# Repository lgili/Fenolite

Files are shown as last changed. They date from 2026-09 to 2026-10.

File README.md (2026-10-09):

# Fenolite

**Headless, agent-first PCB design automation in Python.** Fenolite lets an engineer — or an AI
coding agent — generate, open, verify, compare, convert and export printed-circuit-board projects
from Python code or a JSON-speaking command line, without a GUI. KiCad is the first backend (its
files, with `kicad-cli` as the verification oracle); a second backend for another major commercial
format family follows.

> **Status: version 0.4.** A design script becomes a KiCad project with a board and a schematic, for
> KiCad 9.0 and 10.0. The loop of the agent guide works on two-layer boards: the board is placed, routed
> by an external router, filled, checked by KiCad's own design-rule check and exported to fabrication
> files. The schematic is judged by KiCad's own electrical rules check, by its netlist and by its
> schematic parity test. Version
> 0.4 adds the agent guide inside the package, boards of up to 8 copper layers with stack-ups, shaped
> outlines, differential pairs, impedance and length rules, routing with planes, and the documents and
> drawings a manufacturer asks for. What was proved for this version, what waits for the next one, and the
> limits are in `docs/release/v0.4.md` (`docs/release/v0.3.md`, `docs/release/v0.2.md` and
> `docs/release/v0.1.md` for the versions before). Every Altium write is experimental: no write kind has
> the evidence to leave that state yet, and most Altium evidence is `INFERRED` or an author report.

*Fenolite* is the Portuguese word for phenolic board material — the laminate many of us etched our
first circuit boards on.

## Principles

- **Agent-first CLI.** JSON on stdout when not attached to a terminal, a fixed envelope, typed
  errors, a small exit-code vocabulary, and writes only with `--confirm` (`--dry-run` shows the plan).
- **Evidence on every answer.** Each result says how it was verified (see below). Nothing is
  claimed that was not checked.
- **No silent information loss.** What Fenolite does not understand in a file is preserved, and a
  lossy operation stops unless explicitly allowed.
- **Small, exact model.** Integer nanometres and microdegrees, stable ids, canonical JSON that
  diffs cleanly in Git.
- **Stdlib-only core.** `pip install fenolite` installs no other package; heavier features are
  optional extras.
- **Your templates, not ours.** Sheet frames and title blocks are generated from your own spec;
  Fenolite ships no organisation's templates, rules or libraries.

The model is described in `docs/design-model.md`; the CLI contract in `docs/cli-contract.md`.

## What version 0.4 does

- **The schematic.** `fenolite build` writes the schematic of the design beside the board, one sheet
  per module, which KiCad's ERC and parity test accept on 9.0 and 10.0 (`docs/schematic.md`).
- **Checks.** `fenolite check` runs KiCad's ERC and DRC, compares the netlist of the schematic with the
  model and the board, and compares schematic and board without a tool (`fenolite netlist`,
  `fenolite parity`).
- **Tables and files.** The bill of materials and the placement table (`fenolite bom`, `fenolite pnp`)
  are rendered through a column template that you write (`docs/assembly.md`). Fabrication files and
  review renders (`fenolite export`, `fenolite render`) are described in `docs/exports.md`, and
  `fenolite manifest` lists every design file and artefact with its SHA-256 and a state.
- **Small questions.** `diff`, `roundtrip`, `fmt`, `explain`, `restore`, `net`, `region`, `neighbors`
  and `pads` answer one thing each, with paging and a concise form.
- **The layout is kept.** A board edited in KiCad survives a rebuild, also when a module or a net is
  renamed, and `fenolite sync --to-source` writes the placements into the source tree (`docs/lens.md`).
- **The design script.** Six more rule kinds (hole to hole, hole clearance, annular width, courtyard,
  silkscreen, creepage), exact quantities, typed interfaces, and your own drawing sheet and title block
  (`docs/dsl.md`, `docs/sheet-templates.md`).
- **Altium files are read.** `inspect`, `check`, `diff` and `equivalent` take Altium documents,
  libraries and projects, read-only and without a tool (`docs/altium.md`, `docs/equivalence.md`), and
  `fenolite analyze` measures current capacity, clearance and creepage on a board
  (`docs/analyses.md`). What is proved of this, and one known defect, are in the release record.
- **Altium files are written.** `fenolite build --target altium` writes the PCB document (stacks of up to
  16 signal layers, blind and buried vias, texts, keep-outs, holes, polygons and the script's rules), the
  schematic documents per module, both libraries, the project file, an output job and the drawing sheet;
  `fenolite check` judges copper and parity on Altium input, `equivalent --level 5` compares routing, and
  `fenolite kit` builds the Altium verification kit (`docs/altium.md`, `docs/altium-kit.md`). All of it is
  experimental: the release record says per file kind what is proved and what is missing.

- **The agent guide.** `fenolite guide` prints the guide that ships in the package, `fenolite skill
  install` puts it where an agent finds it, `fenolite init` writes a starter project, and
  `fenolite fetch freerouting` installs the pinned router (`docs/cli-contract.md`).
- **Larger boards.** 6 and 8 copper layers, stack-ups, outlines with arcs and cut-outs, holes, rule areas,
  board texts and dimensions, differential pairs, impedance targets, net lengths and meanders, via
  protection, net ties and waivers, placement rules and part heights (`docs/dsl.md`); `route` keeps plane
  nets to their planes and is bounded by `--timeout`, and `fenolite ready` says whether a project is
  electrically ready. What each change ships, and what waits for the next release, is in
  `docs/release/v0.4.md`.
- **Fabrication documents.** `fenolite export` writes IPC-2581, ODB++, STEP, PDF and DXF, and fabrication
  and assembly drawings (`docs/exports.md`, `docs/drawings.md`); `fenolite testpoints` reports fiducials and
  test points.

## Evidence labels

| Label | Meaning |
|---|---|
| `KICAD-VERIFIED` | accepted by `kicad-cli` of the stated version, and the claim confirmed by its output |
| `ORACLE-VERIFIED(<tool>)` | an independent parser or tool agreed |
| `CORPUS-VERIFIED` | round-trip holds on public files listed in the corpus manifest |
| `ALTIUM-VERIFIED(kit)` | confirmed by a native-tool acceptance run with archived results: a run of the verification kit that `fenolite kit` builds, checks and records ([docs/altium-kit.md](docs/altium-kit.md)) |
| `ALTIUM-VERIFIED(author-report)` | reported by the author from ordinary use; never enough for a release claim |
| `INFERRED` | deduced from public documentation; a hypothesis in `docs/hypotheses.md` tracks it |
| `UNKNOWN` | bytes or fields preserved without interpretation |
| `UNVERIFIED` | default for anything new |

A command's overall label is the lowest label of the steps it ran.

## Install

```bash
pip install fenolite
```

It installs no other package. `fenolite capabilities --json` then says which external tools it found:
`kicad-cli` (KiCad 9.0 or 10.0) for the checks, the fills and the exports, and a router. It runs on Linux, macOS
and Windows.

## The loop

The ten commands an agent runs, from an empty folder to fabrication files. They start from a starter
project made of built-in parts and use the built-in router, so `kicad-cli` is the only tool they need; a
real board is routed by an external router or by copper written in the script.
`fenolite guide start --text` prints the agent guide, which explains each command and what to do when one
fails (in this repository: `src/fenolite/agent/skill/SKILL.md`), and `fenolite skill install` copies it
to where an agent reads skills:

```fenolite-loop
fenolite capabilities --brief --json
fenolite init blink --confirm --json
fenolite build blink/design.py --out blink/build --dry-run --json
fenolite build blink/design.py --out blink/build --confirm --json
fenolite place blink/build --strategy grid --confirm --json
fenolite route blink/build --router direct --confirm --json
fenolite fill blink/build --confirm --json
fenolite check blink/build --json
fenolite export blink/build -o blink/fab --all --manifest --confirm --json
fenolite render blink/build -o blink/views --svg --png --confirm --json
```

## Install for development

```bash
git clone <this repository>
cd fenolite
uv sync --extra dev
uv run fenolite --version
make check-fast   # lint, format, types, residue scan and the tests that need no external tool
make check        # everything, on parallel workers: the gate before a merge
```

Talk to it like an agent does:

```bash
uv run fenolite capabilities --json --fields tools          # what is installed here
uv run fenolite capabilities --text                         # the same, for humans
echo $?                                                     # 0 ok, 2 usage, 4 confirm, 5 findings …
```

Optional extras: `geo` (polygon booleans), `kicad-ipc` (live KiCad session), `mcp` (MCP server),
`oracles` (Gerber re-parsers used in tests), `dev`. Routers need no extra: they run as separate programs.

## Licence and provenance

Apache-2.0 (`LICENSE`, `NOTICE`). Format knowledge comes only from public sources; see `LEGAL.md`
for the clean-room rules and `CONTRIBUTING.md` for how to contribute. Every CI run and every commit
(after `make hooks`) passes a residue scan (`tools/residue/`) that blocks absolute paths, internal
identifier shapes and known non-public files; see `docs/provenance.md` for the provenance rules. AI agents working in this
repository: read `AGENTS.md` first.

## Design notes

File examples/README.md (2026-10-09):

# examples

Designs authored for Fenolite (CC0-1.0), used as documentation and as end-to-end tests. Every
example is original work: no file, value, name or layout comes from any organisation's projects.

| example | what it shows |
|---|---|
| `blink_2layer/` | the thin DSL: a mini MCU, a resistor and an LED (bottom side) on a 50 mm × 30 mm two-layer board, from the authored mini library through the folder's own library tables; `fenolite build` turns it into a KiCad 9.0 or 10.0 project: the board, project and rules files, the schematic `blink.kicad_sch` with `sym-lib-table`, and under `lib/` the three footprints and the symbol libraries `Mini.kicad_sym` and `fenolite.kicad_sym` (`docs/schematic.md`); the 29 pins the circuit does not use are marked with `no_connect`, so KiCad's ERC reports nothing on the built project |
| `blink_routed/` | the blink with copper declared by the script: three tracks from pad to pad with waypoints and layer-changing vias, and a row of stitching vias, 11 tracks and 7 vias in all; the build resolves them after placement, so a part moved in KiCad pulls its tracks along (`docs/copper.md`) |
| `board_40parts/` | forty parts in two modules: two mini MCUs, each driving nine LEDs through nine resistors, with an enable pull-up, on a 100 mm × 80 mm two-layer board with a `GND` zone on both layers and one scripted ground via under each controller; only the two controllers are placed (and locked), the rest is left to `fenolite place --strategy grid`; the board minimums come from `design.rules.minimum`, so KiCad's DRC judges the finished board against the script's own rules; it is the second board of the v0.1 acceptance loop (`docs/release/v0.1.md`); its schematic takes one A3 sheet, a row of symbols per module, and KiCad's ERC and parity test report nothing on it |
| `blink_official/` | the same circuit on KiCad's official libraries; DSL source only, built by a `needs_libs` test into a temporary folder |
| `altium_sample/` | the experimental Altium target (`fenolite build … --target altium`): eight parts at the top level and in two modules, a 5 V regulator, a driver with an enable pull-up and an LED, two supplies sharing `GND`, every pin connected by number; its lib ids name `FenoliteSample.SchLib` and `FenoliteSample.PcbLib`, which Fenolite does not ship; the built files are committed under `tests/data/altium/sample/` |
| `altium_kicad/` | the Altium target from KiCad symbols (change c0034): a dual amplifier with common supply pins, a controller with pins on four sides, upright resistors and a connector from the authored CC0 `FenoliteDemo.kicad_sym`, found through the folder's `sym-lib-table`; the build writes their pins and units into `altium_kicad.SchLib`, and the built files are committed under `tests/data/altium/kicad_example/` |
| `altium_hier/` | sheets per module and a signal harness for the Altium target (change c0037, `--altium-sheets modules`): a connector on the top sheet, a controller and a flash memory in two modules, an `SPI` harness between them; `partial.py` adds a harness entry whose net stays on one sheet; the lib ids name `FenoliteHier.SchLib` and `FenoliteHier.PcbLib`, which Fenolite does not ship; the built files are committed under `tests/data/altium/hier/` |
| `altium_hier_board/` | the blink circuit of `blink_2layer/` split into the modules `driver` and `led`, with its board and the same authored libraries, so the Altium build writes a PCB document whose parts link through their sheet symbols |
| `kit/` | the five sample scripts of the Altium verification kit (`docs/altium-kit.md`): `flat`, `tree`, `routed`, `board6` and `libs`, all on Fenolite's own catalog; `fenolite kit build` builds them into the kit, and nothing it builds is committed |
| `yardstick/` | the yardstick board, at stage 5 of five (`docs/evidence/yardstick.md`): an invented controller of eight identical 48 V buck channels with an isolated high-voltage sense section, 388 parts of KiCad's official libraries and of the generated hole and assembly libraries on a 250 mm × 110 mm six-layer board with a declared stack-up, inner planes, slots under the isolators, plated mounting holes with keep-outs, a high-voltage rule area, the USB pair's rules and impedance target, thermal via arrays, placement rules, a net tie, fiducials, tooling holes and test points; one function makes a channel and is called eight times, references are `n·100 + k`, the script places every part and draws no track, and every value is stated once at the top as `chosen for the example` or with a source id; DSL source only, built for KiCad 10 from the verified library cache by a `needs_libs` test and taken through the loop every night by `tools/yardstick.py run` (routed by Freerouting, judged by KiCad), with a time and memory budget per step |

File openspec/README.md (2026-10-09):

# openspec

Spec-driven development with [OpenSpec](https://github.com/Fission-AI/OpenSpec).

- `specs/<capability>/spec.md` — the current, normative requirements (SHALL/MUST + scenarios).
- `changes/<id>/` — one proposed change: `proposal.md` (why), `design.md` (how), `specs/` (deltas),
  `tasks.md` (≤ 1-day tasks, each with the command that proves it).
- `config.yaml` — project context and artefact rules injected into every change.

No code lands without a change. Archive a change with `openspec archive <id>` once all tasks are done.

## Change ids

Archived changes are under `changes/archive/`; a change in `changes/` is proposed or being implemented. Plan items keep their numbers (c0009–c0016);
split-offs and follow-ups take c0017 and later numbers in implementation order, and a new split-off
takes the next free number. Ids follow the form `cNNNN-<slug>`, a project convention (the `openspec`
CLI accepts any kebab-case name); lettered ids such as `c0009a` are not used. A slug may still change
until its change is proposed. The nine v0.2a changes were allocated together as c0060–c0068 on
2026-10-04, while c0058 was being written, so c0057 stays unused.
The six v0.2b changes were allocated together as c0069–c0074 on 2026-10-05.
The ten changes of the write part of v0.3 were allocated together as c0083–c0092 on 2026-10-06, and
c0093 was taken for the release of v0.2 on the same day.
Since 2026-10-07 (c0136) v0.3 is the whole second backend, its read part and its write part, and v0.4
names the proposals that are written on other branches and are not in this table: c0077–c0081 (the
agent track), c0096, c0097 and c0099 (board authoring) and c0100–c0120 (the complex board). c0095 is
reserved; c0098 is in v0.4 by the maintainer's decision of 2026-10-08 (roadmap, "Open decisions", row 35) and has its row below. `docs/roadmap.md`, “Milestone names”, has the decision; archived changes
keep the names of their day. The changes of v0.4 were gathered on the branch `v04` and are released as
`0.4.0` by c0154; their folders are not all rows of this table.

| id | slug | roadmap item | parent |
|---|---|---|---|
| c0009 | `kicad-board-backend` | 0009 (part 1) | — |
| c0010 | `kicad-project-file` | 0010 | — |
| c0011 | `dsl-thin-build` | 0011 (part 1) | — |
| c0012 | `sheet-templates-kicad` | 0012 | — |
| c0013 | `kicad-oracle-and-check` | 0013 (part 1) | — |
| c0014 | `verification-evidence` | 0014 | — |
| c0015 | `zone-fill` | 0015 | — |
| c0016 | `routing-plugins` | 0016 | — |
| c0017 | `kicad-board-writer` | split-off | 0009 |
| c0018 | `kicad-rules-footprints` | split-off | 0009 |
| c0019 | `layout-preserve` | split-off | 0011 |
| c0020 | `check-netlist-drc` | split-off | 0013 |
| c0021 | `kicad-libs-cache` | follow-up | c0008 |
| c0022 | `placement-grid` | split-off | 0016 |
| c0023 | `specctra-freerouting` | split-off | 0016 |
| c0024 | `manufacturing-exports` | unowned deliverables | — |
| c0025 | `release-v0-1` | unowned deliverables | — |
| c0026 | `kicad-board-minimums` | dogfood gap | c0010 |
| c0027 | `build-properties-vendoring` | dogfood gap | c0011 |
| c0028 | `board-frame-copper` | dogfood gap | — |
| c0029 | `copper-check` | dogfood gap | — |
| c0030 | `footprint-fields` | dogfood gap | — |
| c0031 | `zone-settings` | dogfood gap | — |
| c0032 | `altium-schematic-writer` | v0.3 write, first item pulled forward | — |
| c0033 | `altium-binary-schematic` | follow-up | c0032 |
| c0034 | `altium-schlib-writer` | v0.3 write item pulled forward | c0032 |
| c0035 | `altium-pcb-writers` | v0.3 write items pulled forward | c0032 |
| c0036 | `no-connect-pins` | follow-up | c0032 |
| c0037 | `altium-hierarchy-harness` | v0.3 write item pulled forward | c0032 |
| c0038 | `altium-pcb-copper` | v0.3 write item pulled forward | c0035 |
| c0039 | `altium-compound-reader` | v0.3 read | — |
| c0040 | `altium-schematic-reader` | v0.3 read | — |
| c0041 | `altium-pcb-reader` | v0.3 read | — |
| c0042 | `altium-project-reader` | v0.3 read | — |
| c0043 | `altium-import` | v0.3 read | — |
| c0044 | `altium-inspect-check-diff` | v0.3 read | — |
| c0045 | `design-equivalence` | v0.3 read | — |
| c0046 | `altium-sheet-template-import` | v0.3 read | — |
| c0047 | `board-analyses` | v0.3 read | — |
| c0048 | `altium-eco-clean` | v0.3 (Altium writer) | c0038 |
| c0049 | `test-speed` | v0.1 | — |
| c0050 | `transform-composition-bound` | v0.1 | — |
| c0051 | `drc-canary-repeatability` | v0.1 | — |
| c0052 | `release-hygiene` | v0.1 | — |
| c0053 | `altium-script-copper` | v0.1 (Altium writer) | c0038 |
| c0054 | `dsl-rule-constructor` | v0.1 | c0011 |
| c0055 | `dsl-footprint-authoring` | dogfood gap / v0.3 write footprint generator | c0011, c0018 |
| c0056 | `dsl-pin-pad-map-slots` | dogfood gap / v0.3 write footprint generator | c0055 |
| c0057 | (unused) | — | — |
| c0058 | `authored-symbols` | follow-up | — |
| c0059 | `shared-footprint-pads` | follow-up | c0055 |
| c0060 | `kicad-schematic-reader` | v0.2a | — |
| c0061 | `kicad-schematic-writer` | v0.2a | — |
| c0062 | `erc-oracle` | v0.2a | — |
| c0063 | `netlist-compare` | v0.2a | — |
| c0064 | `bom-pnp-templates` | v0.2a | — |
| c0065 | `artifact-manifest-states` | v0.2a | — |
| c0066 | `cli-inspection-commands` | v0.2a | — |
| c0067 | `evidence-matrix` | v0.2a | — |
| c0068 | `v01-followups` | v0.2a | c0025, c0028, c0029, c0031 |
| c0069 | `layout-lens-complete` | v0.2b | c0019 |
| c0070 | `schematic-hierarchy-layout` | v0.2b | c0061, c0063 |
| c0071 | `rules-complete` | v0.2b | c0018, c0026, c0054 |
| c0072 | `schematic-board-parity` | v0.2b | c0062 |
| c0073 | `interfaces-quantities` | v0.2b | — |
| c0074 | `drawing-sheets-followups` | v0.2b | c0012, c0068 |
| c0075 | `standard-component-catalog` | dogfood gap: offline common symbols and footprints | c0008, c0058 |
| c0076 | `component-catalog-coverage` | expand offline symbols and standard package footprints across common families | c0055, c0056, c0075 |

| c0082 | `kicad-worksheet-oracle-isolation` | CI correction: isolated worksheet boundary oracle | — |
| c0083 | `altium-repeated-sheets` | v0.3 write | c0043 |
| c0084 | `altium-rule-lowering` | v0.3 write | c0038, c0042 |
| c0085 | `altium-pcb-complete` | v0.3 write | c0035, c0038 |
| c0086 | `altium-schematic-complete` | v0.3 write | c0032 |
| c0087 | `altium-outjob-sheet` | v0.3 write | c0042, c0046 |
| c0088 | `altium-light-drc` | v0.3 write | c0044, c0072 |
| c0089 | `equivalence-level-5` | v0.3 write | c0045 |
| c0090 | `altium-roundtrip-write` | v0.3 write | c0044 |
| c0091 | `altium-verification-kit` | v0.3 write | — |
| c0092 | `altium-write-graduation` | v0.3 write | c0091 |
| c0093 | `release-v0-2` | release of v0.2a and v0.2b as `0.2.0`: release record, guard, version | every v0.2a and v0.2b change |
| c0094 | `bom-dnp-grouping` | correction of v0.2a: a BOM line is all DNP or all fitted | c0064 |
| c0098 | `electrical-readiness` | v0.4 (the maintainer's decision of 2026-10-08): `fenolite ready`, one read-only reply on whether a KiCad project is electrically ready: open nets, KiCad's ERC and DRC, unconnected pins, power nets without a declared width or a zone, parts without a footprint or a value | c0062, c0108 |
| c0121 | `altium-component-bodies` | v0.3 follow-up: the component bodies that c0085 cut, fact rows first | c0085 |
| c0122 | `altium-zone-holes` | correction of v0.3: a zone fill keeps the holes of its poured region | c0043 |
| c0124 | `altium-plane-lines` | correction of v0.3: the Altium import makes no track of a line on an internal plane | c0043, c0088 |
| c0125 | `altium-clearance-scopes` | v0.3 follow-up: more forms of the Clearance record in the Altium rule table | c0084, c0088 |
| c0126 | `footprint-instance-graphics` | v0.3 write: the graphics and texts of a footprint instance and the corner ratio of a pad in the model; closes task 2.2 of c0090 | c0090, c0123 |
| c0127 | `altium-arc-record-values` | v0.3, follow-up (decision of 2026-10-06) | c0090 |
| c0128 | `altium-rewrite-via-drill` | v0.3, follow-up (decision of 2026-10-06) | c0090 |
| c0129 | reserved | v0.3 follow-up of c0121 and c0099: keep the model keys of a component body that was read | c0099, c0121 |
| c0130 | `altium-clearance-matrix-cells` | v0.3 follow-up: a Clearance matrix read as one rule per cell of item kinds | c0125 |
| c0131 | `altium-unit-slack-rule` | v0.3 follow-up: the slack of the copper check on Altium input as a stated rule | c0130 |
| c0132 | `altium-via-inner-pads` | correction of v0.3 (2026-10-07): a via whose record names layers without a pad shape is judged by its hole there | c0088, c0130, c0131 |
| c0133 | `release-0-2-1` | patch release `0.2.1`: the rule for patch releases of the series, the record, the guard, the version | c0093, c0135 |
| c0134 | `catalog-pin-text-legibility` | correction of v0.3: an authored symbol shows a pin name only where it can be read; a measured rule on every authored symbol, no writer changes | c0076, c0086 |
| c0135 | `altium-pin-map-backport` | correction of 0.1.0 and 0.2.0: an Altium build applies `pad_map` to the PCB document and writes it into the schematic | c0056, c0035 |
| c0136 | `milestone-renumbering` | names only: the write side of the second backend is v0.3 (released as `0.3.0`) and the proposals open on other branches form v0.4; no behaviour changes | — |
| c0138 | `altium-outjob-gerber-settings` | correction of v0.3: the Gerber output of a written output job carries the complete settings record, with the plotted layers from the board; fact rows first | c0087 |
| c0143 | `catalog-power-interface-library-case` | correction of 0.2.0 and 0.2.1: a design with catalog parts and a `Power` interface builds for KiCad, the power flag in the catalog's library | c0061, c0075 |
| c0146 | `altium-schematic-fonts-and-part-r` | correction of v0.3 (found in Altium Designer 26 on 2026-10-07): the font table of a written schematic holds each distinct font once; the authored `Repeat` sample is written by the schematic writer | c0087, c0083, c0086 |
| c0148 | `altium-pin-hide-bits` | correction of v0.3 (found in Altium Designer 26 on 2026-10-08): every written pin holds bit 0x20 of `PINCONGLOMERATE`, with 0x08 and 0x10 as show flags; the reader reads the two bits as hide flags on pins without 0x20 | c0032, c0034, c0040 |
| c0149 | `release-0-2-2` | patch release `0.2.2`: the record, the version | c0133, c0143 |
| c0150 | `release-0-3-0` | release of the write part of v0.3 as `0.3.0`: the release record with the verdict of the rule of c0092 per Altium write kind and the maintainer's exception for the kit, its guard, the version and the changelog cut; c0149 is the patch release `0.2.2` on its own branch, and c0151 and c0152 are proposed as the follow-ups the record names | c0083–c0092, c0121–c0148 |
| c0140 | `part-height-rules` | v0.4: part heights as bodies of their footprint, read by one function, and height limits over named rule areas judged by `check`, `place` and `build` | c0099, c0103, c0113 |
| c0152 | `clearance-rounding` | follow-up of c0131 (Altium's rule check of 2026-10-08, S-0616): the copper check on Altium input lowers its clearance rules by Altium's observed tolerance, 3.5 file units in whole nanometres (9 nm), where that is above the unit's slack | c0131, c0132 |
| c0153 | `kicad-cli-per-worker` | correction (two transient failures of the kicad-9 job on 2026-10-08): every `kicad-cli` run gets private temporary, runtime, cache and state folders, so parallel runs share no instance lock file | c0009, c0082 |
| c0154 | `release-0-4-0` | release of v0.4 as `0.4.0`: the release record with the verdict per change, what is deferred to the next release by the maintainer's decision of 2026-10-08 and the follow-ups found that day, its guard, the version and the changelog cut | c0077–c0081, c0096–c0120, c0137, c0140, c0141, c0145, c0152, c0153 |

Older planning text that says `tokens.yaml` means the token inventory `src/fenolite/backends/kicad/data/tokens.toml`.

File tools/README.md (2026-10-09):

# tools

Developer scripts (stdlib-only, run as `uv run python tools/<script>.py`). They are not part of the
installed package. Later changes add the schema generator, the residue scan, the corpus fetcher and
the oracle setup scripts here.

| script | what it does |
|---|---|
| `test_outcomes.py` | Compares the JUnit XML files of two pytest runs (`--junitxml`): the totals of each run and every test id whose outcome differs; exit 0 when equal, 1 when not. It proves that a parallel run gives the results of a serial run (`tests/README.md`, "Parallel runs"). |
| `kicad_libs_fetch.py` | Fetches the official KiCad footprint and symbol libraries at the pinned commits of tags 10.0.6 and 9.0.9 into a verified cache outside the repository (`--cache`, else `FENOLITE_LIBS_CACHE`, else `~/.cache/fenolite/libs`); `--verify` re-hashes it. The libraries are CC-BY-SA 4.0 and are never committed (`docs/formats/kicad/libraries.md`, "Library cache"). |
| `altium_census.py` | `--uses altium-sch` or `--uses altium-schlib` [`--json`]: reads the cached Altium schematic or library corpus rows with `fenolite.backends.altium.read` and prints the merged census (record ids, unknown ids and keys, key case, `WEIGHT`, owners, fractions, pin strings, side streams, stream sizes, issue codes). Key names, ids and counts only, never a value of a file (change c0040). |
| `gen_agent_guide.py` | Writes the generated parts of the agent guide under `src/fenolite/agent/skill/`: `references/commands.md` from `fenolite.cli.describe`, `references/dsl-reference.md` from the signatures of `fenolite.dsl`, and the index of pages between the two marker lines of `SKILL.md`. `--check` writes nothing and exits 1 naming each stale file; `make check-fast` runs it. |
| `gen_evidence_matrix.py` | Renders `docs/evidence/matrix.md` from the evidence declarations of the backend modules (`fenolite.backends.matrix`) and the level text of `docs/hypotheses.md`: the matrix of backend, file kind and operation, the register level of each id it names, and each module's declaration. `--check` writes nothing and exits 1 when the committed page is stale (`tests/unit/test_evidence_matrix_page.py` runs it). |
| `yardstick.py` | Takes `examples/yardstick` through the loop of its stage and judges the run (change c0119; "The yardstick" below). |
| `yardstick_budgets.toml` | The seconds and MiB each step of the yardstick may take, per stage, and the findings a stage accepts. |

## The yardstick

`uv run python tools/yardstick.py run --out build/yardstick --record build/yardstick/record.json` (or
`make yardstick`) reads `STAGE` from `examples/yardstick/design.py` without running it, and runs the steps
of that stage, each as one child process `python -m fenolite <args> --json` in the output folder, which
becomes the project folder and must be empty. It needs `kicad-cli` 10 and `FENOLITE_LIBS_CACHE` naming the
verified library cache of tag 10.0.6 (`kicad_libs_fetch.py --tag 10.0.6`); from stage 4 also
`FENOLITE_FREEROUTING_JAR` (`fenolite fetch freerouting --confirm`, and Java 25) and `FENOLITE_KRT` with
`FENOLITE_KRT_PYTHON` (the pinned KiCadRoutingTools checkout), as the nightly job sets them.

- **Steps of stage 1**, in order: `capabilities`, `build-dry`, `build`, `fill`, `check` (concise; it exits
  5 before stage 4, because nothing is routed), `export`, `render`, `bom`, `pnp`, `manifest`, `rebuild-dry`,
  `rebuild`, `inspect`, `build-install` (a dry-run build without `FENOLITE_LIBS_CACHE`, so the libraries
  come from the KiCad install), then `heavy-read` and `heavy-rt1` once for each of the two corpus boards
  tagged `heavy` (`corpus_fetch.py --uses heavy --only <id> <id>`; `--skip-heavy` leaves them out).
  `--only STEP,…` runs single steps on an existing project.
- **Steps added by the later stages:** stage 3 `impedance`; stage 4 `route-pairs` (KiCadRoutingTools on the
  pair, with the escape of the controller), `route` (Freerouting, `--timeout 3600`, two tiers),
  `fill-routed`, `check-routed` (exit 0, or 5 with counts within the ratchets), `net` and `analyze`;
  stage 5 `export-package` (the document kinds and drawings, with `--manifest`) and `testpoints`.
- **Per step** the record keeps the arguments, the exit code, the wall seconds, the peak resident memory
  of the step's largest process, the bytes of the reply and the issue counts by code. The replies are
  kept under `yardstick-run/replies/` of the output folder.
- **Rules.** Every step exits as its stage expects; every `check` stage that ran is `ok`, except
  `drc.kicad`, whose only error type before stage 4 is `unconnected_items`; `copper.clearance` has no
  finding and the net comparison no difference; the manifest lists every file that `export`, `render`,
  `bom` and `pnp` wrote; the dry rebuild plans no change to a file outside `.fenolite/`, and the rebuild
  leaves the board's bytes unchanged. A failed `build` or `fill` skips the steps that need the board.
  From stage 4, `check-routed` holds KiCad's open connections and DRC errors of the routed board to the
  stage's ratchets; an error of `length.rules` there counts through KiCad's `length_out_of_range` or
  `skew_out_of_range` when KiCad reports that type as often, and fails the stage otherwise; at stage 5 every file that `export-package` and `testpoints` wrote is listed in
  `fab/fenolite-artifacts.json`.
- **Budgets.** `yardstick_budgets.toml` holds a table per stage: `source`, then `seconds` and `mib` per
  step under `[stage<n>.steps.<step>]`, and from stage 4 `[stage<n>.ratchets]` with `open_connections` and
  `drc_errors`. A step over its budget, or a count over its ratchet, fails the run; a step without a
  budget is recorded and fails nothing; a stage without a table, or from stage 4 without its ratchets, is
  exit 2. `rebase RECORD RECORD RECORD` prints the budgets that three runs give (median seconds times 1.5,
  rounded up to 10 s; largest MiB times 1.25, rounded up to 50 MiB; a ratchet is the largest count), and
  `rebase --provisional RECORD` those of one local run (times 4 and times 2).
- **Accepted findings.** A finding that only a repair in Fenolite can remove is accepted for a stage by
  an entry `[stage<n>.accepted.<key>]` with `stage` (the `check` stage), `type`, `reason` and `owner` (the
  change or issue that owns the repair). It is counted in every record and fails nothing; any other type
  still fails the run. Stage 1 has none.
- **The record** (`fenolite.yardstick-record.v0`) holds the date, the commit, the stage, the runner, the
  tool versions, the board's measures, the steps, the rules, the accepted findings, the budgets and the
  verdict, with no absolute path. `row RECORD --url URL` prints its row of the `Runs` table of
  `docs/evidence/yardstick.md`.
- **Exit codes:** 0 passed; 1 a step, a rule or a budget failed; 2 usage, or a missing `kicad-cli`,
  library cache, corpus row, router, budget table or ratchet table. The summary is printed, and appended to `--summary FILE`.
- Seconds and MiB are measures of one runner: no evidence label moves on a budget.

## Agent evaluation (`tools/agent_eval/`)

Measures whether a fresh AI agent can use Fenolite (change c0081). `run.py` gives one task of
`tools/agent_eval/tasks/` to one runner of `runners.toml` in a clean place, and Fenolite itself decides
the result.

```
make agent-eval TASK=led-indicator RUNNER=replay
uv run python tools/agent_eval/run.py --task led-indicator --runner replay [--repeat N] [--keep] [--record] [--yes]
```

| file | what it does |
|---|---|
| `run.py` | Builds the wheel of the checkout, installs it with no extra and no index in a new environment under a new temporary folder outside the repository (`uv` does both), makes an empty work folder, copies the task's `files/`, runs its `prepare` lines, installs the guide as the runner's row says, prints the budget, starts the runner with the call log first on `PATH`, stops it when the task's minutes are over, judges, writes `result.json` beside the work folder and prints one verdict line. Exit 0 when every verdict is `passed`, 5 otherwise, 1 when the place could not be prepared, 2 for a refused run. The temporary folder is removed unless `--keep` is given. |
| `judge.py` | The verdict, from the files of the work folder: the project exists, `fenolite check` exits 0, the nets of the built model are the expected groups of `REF-PIN`, the board fits, the output files exist. `passed` needs `kicad-cli`; without it the verdict is `unjudged`. |
| `shim.py` | The call log: a stand-in named `fenolite` that passes a call through unchanged and appends one JSON line per call (`n`, `argv`, `exit`, `elapsed_ms`, `error_code`). It logs no environment value; an absolute path is logged relative to the current folder, or as `<outside>/NAME`. |
| `tasks.py`, `tasks/` | The task format and the five tasks with their reference solutions (`tasks/README.md`). |
| `runners.toml` | The runners. `replay` plays the reference solution of a task and starts no agent: it is what the test suites run. Every other row starts a real agent and names the public page it was written from. |

**A run with a real agent costs money and is started by a person, never by an agent and never in CI.**
`run.py` refuses a runner other than `replay` while the variable `CI` is set; without `--yes` it prints
the task, the runner, the time budget and the cost cap and starts nothing; a row marked `unconfigured`
does not start at all. One run is one agent session of at most the task's minutes (20, and 30 for
`custom-footprint`), so the five tasks are at most 110 minutes of agent time. What a session costs is
not known before the first one: run `led-indicator` once, read the cost the runner reports, then decide
on the rest. The tool reads no key and calls no service itself; the agent it starts inherits the
environment of the person who started it, and is not sandboxed beyond an empty work folder and a new
environment.

To record a run, add `--record`: one row is appended to `docs/evidence/agent-eval.md` (date, commit,
runner, model, task, verdict, calls, failed calls, minutes, first failure), with no path, prompt or
transcript. Add a row to `Findings` by hand for each distinct first failure. `--keep` leaves the
temporary folder, which holds the transcript, on your machine; it is never committed.

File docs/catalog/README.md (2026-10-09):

# Fenolite component catalog

Fenolite ships an offline, incrementally expanded catalog under the `Fenolite:` library ID. Its
entries are Fenolite-authored model definitions. The catalog includes generic passive,
semiconductor, protection, power/control IC and electromechanical symbols: **49 symbols** plus **100 distinct
footprint variants** for chip passives, discretes, ICs, connectors, LEDs, switches, leaded passives,
crystals and mechanical features. See the
[coverage matrix](coverage.md) for exact IDs, evidence and package limitations.

Use the definitions in Python with `fenolite.catalog.get_symbol()` and
`fenolite.catalog.get_footprint()`. `fenolite catalog list` searches the installed catalog and
`fenolite catalog show Fenolite:Resistor` prints one entry's metadata. A KiCad build uses a catalog
definition when the CLI design references its lib id. With the lower-level `build_design()` API,
pass `get_footprint(lib_id)` definitions in `authored_footprints` and symbol definitions in
`authored_symbols`. A project definition with the same exact lib id
overrides the catalog for that build only. Other component packs can be added without requiring a
CAD installation or network access.

A catalog footprint definition holds no text field. The KiCad build generates the two a KiCad
footprint needs (change c0077): `Reference` (`REF**` in the project library, the part's reference on the
board) on `F.SilkS`, 1 mm above the footprint's courtyard box, and `Value` (the footprint's name in the
library, the part's value on the board) on `F.Fab`, 1 mm below it. `Part.field("Reference", …)` and
`Part.field("Value", …)` move or hide them (`docs/dsl.md`, "Field placement"). So a board that names
only catalog ids passes `fenolite check`: `tests/_catalog_design.py` holds such a design, and
`tests/unit/cli/test_catalog_only.py` and `tests/kicad/build/test_catalog_only.py` build and check it.

The schematic symbols use aligned wire connection points, inward-facing stems and 0.254 mm body
strokes. Their outlines are Fenolite-authored interpretations of familiar electrical shapes.
Review sheets render the actual catalog geometry, including background fill and terminal roles.

Pin names follow one rule (change c0134): a symbol shows a pin name only where it can be read.

- A symbol whose drawing tells its pins apart hides its pin names and shows the pin numbers alone:
  the passives, diodes, transistors, thyristors, switches, the relay, the transformer, the
  optocoupler, the bridge rectifier and the two amplifiers. Where the drawing alone would not say
  which pin is which, strokes say it: a plus and a minus at the amplifier inputs; a plus, a minus
  and two waves inside the bridge; an arrowhead on the optocoupler's emitter leg.
- The four plain rectangles show their names and are sized for them: `Linear_Regulator`,
  `Offline_Power_Controller`, `Microcontroller` and `Power_Module`.
- A hidden name stays in the definition: `fenolite catalog show` and the role line of the review
  sheets list every name, and a design may still name a pin by it.

`tests/unit/catalog/test_pin_text_legibility.py` measures the rule on every catalog symbol at the text
size of KiCad (1.27 mm) and at an estimate of Altium's 10-point pin text: no shown pin text overlaps
another, a shown name has room inside the body, no shown name or number lies on a stroke of the body or
on the mark of a pin shape, and no shown name only repeats its pin's number. The Altium size is an
assumption, not a measurement in Altium.

## Symbol review

The [20-symbol expansion inventory](target-20-symbols.md) records exact IDs, conceptual pin roles and public references.

- [New symbols, sheet 1](previews/c0076-new-20-symbols-page1.svg): transistors, thyristors, protection and potentiometer.
- [New symbols, sheet 2](previews/c0076-new-20-symbols-page2.svg): thermistors, crystal, switches, relay, transformer and photodetectors.
- [Complete 49-symbol gallery](previews/c0076-all-49-symbols.svg).

Regenerate the complete gallery with:

```sh
uv run python tools/catalog/render_symbols.py docs/catalog/previews/c0076-all-49-symbols.svg --page-size 20
```

The new drawings retain zigzag resistance, show unactuated contact states and inward photodetector arrows. Generic B/C/E, G/D/S, coil and winding numbers are role identifiers. The four-terminal pushbutton has two internally common pairs; the two Würth footprints require different explicit maps. No generic symbol supplies a default footprint. Offline build tests preserve these maps and pad nets for KiCad 9/10 targets.

## Footprint review

The [100-slot inventory](target-100-footprints.md) is fully resolved. It is a curated selection
informed by a public-board corpus; it is not a measured worldwide popularity ranking.

Review the native geometry in five sheets of 20 footprints each:

- [Sheet 1](previews/c0076-current-gallery-page1.svg)
- [Sheet 2](previews/c0076-current-gallery-page2.svg)
- [Sheet 3](previews/c0076-current-gallery-page3.svg)
- [Sheet 4](previews/c0076-current-gallery-page4.svg)
- [Sheet 5](previews/c0076-current-gallery-page5.svg)

Blue is the fabrication outline, green the courtyard, orange copper and gray explicit paste
windows. White drill apertures distinguish round holes and plated slots. The sheets show the
component-side view with pad numbers; asymmetric connector origins retain their electrical
coordinates while the renderer centers the courtyard. These are schematic review drawings of
the footprint geometry, not 3D mechanical models.

Regenerate the full sheet and its five pages with:

```sh
uv run python tools/catalog/render_footprints.py docs/catalog/previews/c0076-current-gallery.svg --page-size 20
```

The final audit checks 100 unique IDs against the inventory, registered public sources, distinct
pad/body/paste geometry (ignoring labels and IDs), positive pad clearance and the complete courtyard
bounds. Every definition is serialized and read back with its pad kind, layers, drill, slot,
attributes and drawing geometry preserved. A hermetic API build assigns all 100 definitions to
authored terminal-only test symbols, explicitly maps their terminals, and reads the resulting
board back for KiCad 9 and 10 targets. This proves catalog use and pad/net preservation; the
audit fixture does not represent a functional circuit or a routed board.

Reproduce the focused audit and local branch gate with:

```sh
uv run pytest tests/unit/catalog tests/unit/cli/test_catalog.py tests/unit/lens/test_build_catalog_inventory.py tests/unit/lens/test_build_catalog_symbols.py -q
make check-fast
openspec validate --specs --strict
```

The catalog is not a substitute for checking a selected manufacturer's part. Generic symbols do not
promise a device pinout. Copper lands without an explicit source recommendation are labelled
`INFERRED`; even sourced example lands are starting patterns that require checking against the exact
component datasheet and assembly process before fabrication. Catalog entries do not qualify a part
or board for electrical, thermal or safety requirements.

## Public evidence

- `S-0314` identifies the common passive component families and schematic-symbol categories.
- `S-0315` supplies 0402, 0603, 0805 and 1206 resistor body dimensions. It does not specify the
  footprints' copper land geometry.
- New family and package references are mapped per entry in [the catalog evidence map](sources.md).

Source details are in [the evidence register](../evidence/sources.md).

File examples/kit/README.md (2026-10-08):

# examples/kit

The five sample scripts of the Altium verification kit (`docs/altium-kit.md`). `fenolite kit build --out DIR
--confirm` builds each into an Altium project of the kit; nothing that it builds is committed here.

| sample | what it holds |
|---|---|
| `flat/` | a controller, a resistor, an LED and a connector on one sheet, with the generic drawing sheet and a title block; built in the binary and in the ASCII form |
| `tree/` | a supply, a sensing stage and four LEDs in the modules `power`, `io` and `io/leds`, with the bus `D`; four sheets, no board |
| `routed/` | the circuit of `flat` with tracks, vias, one polygon, five rules and two planted violations |
| `board6/` | the circuit of `flat` on six copper layers with a plane, blind and buried vias, texts, graphics, a keep-out and a hole |
| `libs/` | seven catalog parts, for the schematic library and the PCB library that the build writes |

Every script is authored for Fenolite (CC0-1.0) and takes its symbols and footprints from Fenolite's own
catalog, so a build reads no library and gives the same bytes on every machine.

A sample script is a design script. It may also bind `KIT`, a mapping with the keys `sheets`, `forms`,
`copper`, `planes` and `drawing_sheet`, and a function `kit_model(model)` that returns the model with what
the DSL cannot declare (a bus, six copper layers, board items). Both are read by `fenolite kit build` only:
`fenolite build` builds the same script without them.

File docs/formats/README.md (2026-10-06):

# docs/formats

One page per file-format topic, per backend (`kicad/`, `altium/`, …). Every fact on a page cites a
public source listed in `../evidence/sources.md` and carries an evidence label
(`KICAD-VERIFIED`, `ORACLE-VERIFIED(<tool>)`, `CORPUS-VERIFIED`, `INFERRED`, `UNKNOWN`).
Code is written from these pages, never from third-party source code (see `LEGAL.md`).

## Altium import pages (c0043)

- `altium/connectivity.md`: the rules by which the import derives nets from schematic sheets.
- `altium/import.md`: the mapping of PCB records into the model, the id table and the extension-bag keys.
- `altium/pcb-bodies.md`: the component-body record and its typed keys.

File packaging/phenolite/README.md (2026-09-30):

# phenolite → Fenolite

`phenolite` is an alias. Installing it installs **[Fenolite](https://github.com/lgili/Fenolite)**,
the headless, agent-first PCB design automation library for Python:

```bash
pip install fenolite      # the real package
pip install phenolite     # the same thing, for those who spell it in English
```

Import `fenolite` in your code. *Fenolite* is the Portuguese word for phenolic board material.

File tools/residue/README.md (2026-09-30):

# Residue scan

`scan.py` looks for material that must not be in a public repository: absolute user paths,
cloud-drive paths, internal revision or part-number shapes in data files, whole files known to be
derived from non-public material, and private tokens.

```bash
uv run python tools/residue/scan.py              # tree (+ dist/*.whl if present); exit 5 on hits
uv run python tools/residue/scan.py --staged     # what `git commit` would record
uv run python tools/residue/scan.py --list-patterns
make hooks                                        # install the pre-commit hook
```

Output lines are `path:offset:pattern-id`; the matched text is **never** printed.

## Sources

| Source | Where | Public? |
|---|---|---|
| structural regexes | `patterns.regex` | yes |
| whole-file SHA-256 list | `blobs.sha256` | yes (hashes only) |
| private tokens | `FENOLITE_RESIDUE_TOKENS` (inline, comma or newline separated), the file named by `FENOLITE_RESIDUE_TOKENS_FILE`, or `~/.fenolite-residue-tokens` | **never committed** |
| private whole-file SHA-256 list | the file named by `FENOLITE_RESIDUE_BLOBS_FILE`, or `~/.fenolite-residue-blobs` | **never committed** |

Token file format: one token per line; `#` starts a comment; a plain token matches
case-insensitively when not surrounded by letters or digits; a line starting with `re:` is a
regular expression. Blob files: `<sha256> <label>` per line.

A private gate with the maintainers' token list runs before every release; its content is not
published. No token list may be committed here, not even hashed (`tests/residue/test_no_token_list.py`).

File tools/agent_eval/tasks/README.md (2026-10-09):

# Tasks of the agent evaluation

Each folder is one task for `tools/agent_eval/run.py` (change c0081): a board stated as a requirement,
and what a correct result holds.

| task | what the agent must do |
|---|---|
| `led-indicator` | write a design script from nothing, place, route with the built-in router, check, export |
| `regulator-zone` | put the supply nets in a net class, pour a ground zone on one layer, fill it, keep the board within a size |
| `custom-footprint` | author a symbol and a footprint from dimensions, for a part the catalog lacks, with one pin on two pads |
| `fix-short` | find the short of a given routed project with `check` and repair it without changing a net |
| `two-sided` | place parts on both sides and join them with scripted copper through a via, under given minimums |

## Where the tasks come from

Every task, prompt, circuit, number and expected result here was written for Fenolite. Nothing comes
from an employer, a private project, a product or any organisation: the circuits are textbook
arrangements of a header, a resistor, a LED, a Zener diode and a capacitor, the part `U1` of
`custom-footprint` is invented, and every size is a round value chosen for the task. Every part of
every solution is an id of Fenolite's built-in catalog or is authored in the solution's script, and
no solution needs an external router or a KiCad library.

## Licence

The tasks are dedicated to the public domain under `CC0-1.0`: the `task.toml` files with their prompts
and expected results, the `commands.txt` files and this page. The task scripts (every `.py` file of a
task) carry the `Apache-2.0` header that the repository's SPDX guard (`tests/unit/test_spdx_headers.py`)
demands of every `.py` file, while the task texts are `CC0-1.0`.

## The format

```
<name>/
  task.toml             title, prompt, [budget] minutes, [expect], optional prepare
  files/                optional: copied into the work folder before the agent starts
  solution/
    commands.txt        the fenolite lines of a correct run, one per line
    files/              optional: the files a correct run writes
```

- `prompt`: at most 300 words, in plain words. It names every reference of the expected nets and the
  folders to leave. It names no command, no option and no page of the guide: finding them is what a
  run measures.
- `[expect]`: `project` (the folder of the built project), `copper_layers`, `max_size` (two lengths
  with units; the board may lie either way), `outputs` (file patterns, `**` for any depth) and
  `[expect.nets]`, a label for each net with its `REF-PIN` entries. `PIN` is a pin number of the
  part's symbol, not a pad number, and a pin on several pads is listed once. The labels are never
  compared: only the groups are.
- `prepare`: `fenolite` lines that build the starting state in the work folder. No task folder holds a
  built project: `fix-short` holds a script, and its starting project is built by the code under test.

`tools/agent_eval/tasks.py` reads a task and refuses a malformed one; `tests/unit/test_agent_eval.py`
loads them all and builds every solution; `tests/kicad/acceptance/test_eval_solutions.py` replays every
solution on `kicad-cli`.

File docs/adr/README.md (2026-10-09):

# Architecture Decision Records

One file per decision: `NNNN-short-slug.md`, numbered in order of allocation, never renumbered.
Format (MADR-lite); every ADR MUST contain these six sections, in this order:

```markdown
# ADR-NNNN: <title>

## Status
Proposed | Accepted | Superseded by ADR-XXXX | Deprecated

## Context
What forces are at play; what problem needs a decision.

## Decision
The decision, stated so that it can be checked.

## Alternatives
Each alternative considered, and why it was not chosen.

## Consequences
What becomes easier or harder; follow-up work.

## Evidence
Public sources (ids from `docs/evidence/sources.md`), tests or hypotheses that back the decision.
```

`tests/unit/test_adrs.py` checks the sections and the status vocabulary.

| ADR | Title | Status |
|---|---|---|
| [0001](0001-neutral-model.md) | Neutral model: small now, frozen after the second backend | Accepted |
| [0002](0002-kicad-file-backend.md) | KiCad file backend: Fenolite's own readers and writers, `kicad-cli` as the oracle | Accepted |
| [0003](0003-clean-room-and-provenance.md) | Clean-room development and provenance of format knowledge | Accepted |
| [0004](0004-licence-apache-2.0.md) | Licence: Apache-2.0; copyleft only behind a process boundary | Accepted |
| [0005](0005-sheet-templates.md) | Sheet templates: a neutral drawing sheet built from closed, sourced specifications | Accepted |
| [0006](0006-specctra-and-freerouting.md) | Specctra files from a restricted reference, and Freerouting behind a process boundary | Proposed |
| [0007](0007-fetching-external-tools.md) | Fetching external tools on request: only inside `fenolite fetch`, only with `--confirm`, only bytes of the pinned size and SHA-256 | Accepted |

**Numbering.**

- ADR-0002 was allocated by change c0001 before 0003 and 0004 existed; change c0009 writes it, so it is the only number written out of order.
- The next free number is one above the highest number written or allocated; a new ADR takes it when its change is proposed, and numbers are never reserved.
- ADR numbers are not tied to planning decision numbers. With 0001 to 0007 written (0006 by change c0023, 0007 by change c0078), the next free number is 0008.

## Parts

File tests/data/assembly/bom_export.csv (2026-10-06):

Reference | Value | Footprint | Datasheet | Description | ${DNP} | Bin
R10 | 330 | Mini:Mini_R_0603 |  | made-up resistor, 1 %, "thick" film | DNP
D1 | LED | Mini:Mini_LED_THT_3mm
R1 | 10k | Mini:Mini_R_0603 | none | made-up resistor |  | A

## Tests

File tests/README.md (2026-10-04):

# tests

| Folder | What lives there | Needs |
|---|---|---|
| `unit/` | fast, hermetic tests of `fenolite` and of repository invariants | nothing |
| `consistency/` | CLI contract checks run against every registered command (change c0002) | nothing |
| `residue/` | IP residue scan over the tree and the built wheel (change c0003) | nothing; private token list optional |
| `corpus/` | tests over the fetched public corpus (`tools/corpus_fetch.py`) | `needs_corpus` |
| `kicad/` | tests that call `kicad-cli` 9.0/10.0 | `needs_kicad` |
| `libs/` | census of the official KiCad libraries (read, resolve, count; nothing committed) | `needs_libs`, `slow` |
| `data/` | small fixtures authored for Fenolite, declared in `data/MANIFEST.toml` | nothing |

Run everything that needs no external tool with `uv run pytest -q`. `make check-fast` runs the
checks and the tests of `unit/`, `residue/` and `consistency/` that need no external resource;
`make check` runs every test. Both use parallel workers (see "Parallel runs" below).

## Markers and modes

| Marker or variable | Effect |
|---|---|
| `needs_kicad`, `needs_corpus`, `needs_libs` | skip when the resource is absent |
| `FENOLITE_REQUIRE=kicad,corpus,libs` | required-resource mode: those skips become failures (CI oracle jobs) |
| `kicad_min_major(10)` | skip when the running `kicad-cli` is older (for example `pcb upgrade`, 10.0 only); never a failure, even in required-resource mode |
| `FENOLITE_HEAVY=1` | include corpus files over 20 MB |
| `FENOLITE_KICAD_CLI=/path` | use this `kicad-cli` (a missing file counts as no `kicad-cli`) |
| `KICAD10_FOOTPRINT_DIR`, `KICAD10_SYMBOL_DIR` (or `KICAD9_*`) | official library folders for `needs_libs`; they take precedence over the install |
| `FENOLITE_KICAD_INSTALL_DIR=/path` | the KiCad share folder to use instead of the default install (a missing path counts as no install) |
| `FENOLITE_CENSUS_OUT=/path/census.json` | where `tests/libs/` writes its counts (never a tracked file) |

## Parallel runs

`make check`, `make check-fast` and the CI jobs run the tests on `pytest-xdist` workers
(capability ci-baseline, "Parallel test runs"). A plain `uv run pytest ...` stays serial.

| Where | Options |
|---|---|
| `make check`, `make check-fast` | `-n auto --maxprocesses 8 --dist loadfile` (`PYTEST_WORKERS`, `PYTEST_MAX_WORKERS`, `PYTEST_PARALLEL`) |
| CI `unit`, `kicad-10`, `kicad-9` | `-n auto --dist loadfile` (4 workers on the Linux runners, 3 on macOS) |
| by hand | `uv run pytest tests/kicad -q -n 8 --dist loadfile` |

Rules for tests:

- Write only below `tmp_path`. Use no fixed port and no fixed path outside the repository.
- Do not depend on a test of another file. A summary test may read what the earlier tests of its
  own file collected: `--dist loadfile` runs a file on one worker, in file order. `--dist load`
  breaks such files, so do not use it.
- Give every subprocess call that must finish a limit of 10 s or more. A short limit is only for
  a call that must time out.
- The write modes are serial. With `FENOLITE_PROBES_WRITE=1`, `FENOLITE_GOLDEN_WRITE=1`,
  `FENOLITE_CENSUS_OUT` or `FENOLITE_CHECK_EVIDENCE` set, a run with `-n` stops with a usage error
  (exit code 4): several workers would write the same file.
- Prove a change of the options with `uv run python tools/test_outcomes.py serial.xml parallel.xml`
  on the `--junitxml` files of a serial and a parallel run.

### Measurements (2026-10-04, change c0049)

Machine: 10 cores (4 performance, 6 efficiency), macOS, KiCad 10.0.6, corpus and library caches
present. The machine was never quiet: other agents ran test suites and a Docker container during
every run below (2 to 12 other pytest processes, load average 5 to 38). The times are therefore
upper bounds, and comparisons between rows are rough.

| Run | Options | Wall time | Outcomes |
|---|---|---|---|
| whole suite, before | serial | 3357 s (56 min) | 4827 passed, 24 skipped |
| `tests/kicad` | serial (part of the run above) | 1783 s | 584 passed, 10 skipped |
| `tests/kicad` | `-n 6 --dist loadfile` | 605 s | 584 passed, 10 skipped |
| `tests/kicad` | `-n 8 --dist loadfile` | 546 s | 584 passed, 10 skipped |
| `tests/kicad` | `-n 10 --dist loadfile` | 617 s | 584 passed, 10 skipped |
| `tests/kicad` | `-n 8 --dist load` | 838 s | 583 passed, 11 skipped: `test_upgraded_summary` lost the results of its file |
| `make check-fast` | `-n auto --maxprocesses 8 --dist loadfile` | 122 s (tests 101 s) | 3832 passed, 6 skipped |
| `make check`, after (rebased: 736 more tests) | `-n auto --maxprocesses 8 --dist loadfile` | 1226 s (20 min; tests 1205 s) | 5563 passed, 24 skipped |

- The cap is 8: the fastest of 6, 8 and 10, and it leaves two cores to the `kicad-cli` threads.
- With `loadfile` the longest file bounds the run. In the `tests/kicad` runs with 8 and 10 workers,
  `tests/kicad/check/test_corpus_rt.py` alone took 509 s and 611 s on its worker (412 s serial). The
  next ones are `tests/libs/test_official_resolve.py` (468 s serial), `tests/libs/test_official_read.py`
  (411 s) and `tests/kicad/check/test_check_demos.py` (364 s). Splitting them is later work.
- Equality. `tools/test_outcomes.py` on the serial and the final parallel JUnit files: the 4849
  test ids present in both runs have the same outcome (0 differences). The parallel run has 738
  more ids (723 from changes merged between the two runs, 15 from this change) and lacks 2 that
  were renamed. On one commit, the 594 ids of `tests/kicad` (`-n 8 --dist loadfile`) equal the
  serial run id by id.
- Before and after are not the same suite: the final run holds 15 % more tests and used 4538 s of
  CPU against 3064 s. Per test, the wall time went from 0.69 s to 0.22 s (3.2 times faster) while
  other agents kept the machine at a load average of 18 to 31.
- The maintainer's earlier figure for a serial `make check` on a quiet machine was 11 minutes.

### CI effect (2026-10-04, change c0049)

The first run with the parallel steps is https://github.com/lgili/Fenolite/actions/runs/37178050484
(commit 87c4244). The last serial run that finished on `main` is https://github.com/lgili/Fenolite/actions/runs/37171749778
(commit 75f3a87); three changes landed between the two, so the suites are not the same.

| Job | Serial: job, pytest | Parallel: job, pytest | Serial outcomes | Parallel outcomes |
|---|---|---|---|---|
| `unit` (ubuntu) | 139 s, 115.82 s | 108 s, 84.14 s | 4304 passed, 1080 skipped | 4490 passed, 1109 skipped |
| `unit` (macos) | 246 s, 201.36 s | 81 s, 56.46 s | 4304 passed, 1080 skipped | 4490 passed, 1109 skipped |
| `kicad-9` | 242 s, 208.50 s | 274 s, 239.96 s | 388 passed, 340 skipped, 1 xfailed | 426 passed, 343 skipped, 1 xfailed |
| `kicad-10` | 1485 s, 1440.18 s | 1088 s, 1051.89 s | 1140 passed, 21 skipped | 1182 passed, 21 skipped |
| whole run | 1492 s (24 min 52 s) | 1095 s (18 min 15 s) | all jobs passed | all jobs passed |

- Totals. Each job grew by exactly the tests added between the two commits, counted with
  `--collect-only` on both trees: 215 for the whole suite (`unit`, 5384 to 5599), 42 for
  `tests/kicad tests/corpus` (`kicad-10`, 1161 to 1203) and 41 for `tests/kicad` (`kicad-9`, 729 to
  770). No test failed in either run.
- `kicad-9` lists every outcome (`-rA`): the 386 passed and xfailed test ids that both logs list
  have the same outcome, and the 38 ids only in the parallel log are the tests of
  `tests/kicad/copper`, added after the serial run.
- Times. `kicad-10` bounds the run: its pytest step went from 24 min 0 s to 17 min 32 s with 42 more
  tests. The design expected a drop to about a third; `--dist loadfile` is bounded by its longest
  file (see the measurements above). `kicad-9` did not get faster: 31 s more with 41 more tests.

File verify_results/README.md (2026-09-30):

# verify_results

Results of verification runs made outside CI (for example a native-tool acceptance kit run on a
licensed machine). Each result file records the tool and version, the date, and the SHA-256 of
every artefact it judged, so an evidence label can point to it.

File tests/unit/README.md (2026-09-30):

# tests/unit

Hermetic unit tests: no network, no external tools, no corpus. Mirror the package layout
(`tests/unit/core/`, `tests/unit/model/`, `tests/unit/cli/`) and keep repository-invariant tests
(`test_pyproject_invariants.py`, `test_spdx_headers.py`, …) at this level.

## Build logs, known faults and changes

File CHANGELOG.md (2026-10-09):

# Changelog

All notable changes to Fenolite are documented here. The format follows
[Keep a Changelog](https://keepachangelog.com/en/1.1.0/) and the project uses
[Semantic Versioning](https://semver.org/) (pre-1.0: minor versions may break).

## [Unreleased]

## [0.4.0] - 2026-10-08

### Added

- v0.4, the agent track, board authoring and the complex board: the agent guide ships in the package with a starter project and eleven design pages, `fenolite fetch freerouting` installs the pinned router, and `tools/agent_eval` measures an agent on five authored tasks (c0077 to c0081); constrained placement, rule explanations of copper findings, `fenolite ready`, signed body volumes and part heights (c0096 to c0099, c0140); 6 and 8 copper layers, stack-ups, outlines with arcs and cut-outs, rule areas and board items, differential pairs, impedance targets, net lengths and meanders, routing with planes, open nets and a bounded routing step, pairs for KiCadRoutingTools, script copper in a part's frame, via protection, placement rules, net ties and waivers, power paths, the documents and drawings a manufacturer asks for, fiducials and test points, a reviewed plan written as reviewed, and the yardstick example (c0100 to c0120). What each change ships and what waits for the next release is in `docs/release/v0.4.md`; every Altium write stays experimental.
- **New command `fenolite ready PATH`** (c0098): one read-only reply on whether a KiCad project is electrically ready for fabrication. It gathers the open nets (`analysis.connectivity`, as `fenolite net`), KiCad's ERC and DRC (the `erc.kicad` and `drc.kicad` stages of `check`, unchanged) and the footprint rule of `model.validate`, and adds three rules: pins on no net or alone on a net without a no-connect mark (`ready.pin-unconnected`), power nets with neither a track width of their class or of a rule nor a zone (`ready.power-net-unsized`), and parts without a value (`ready.part-value-missing`); open nets are `ready.net-open`. Exit 0 when `result.ready`, 5 with the findings; a missing `kicad-cli` exits 6 as for `check`, and `--no-kicad` reports ERC and DRC as skipped (`ready.check-skipped`, `result.complete` false). The three rules are `INFERRED` (`H-G-READY-RULES`). `model.circuit.power_interface_nets` and `checks.validate.unresolved_footprints` are now the one place of the power-interface set and of the footprint rule, used by ERC lite, the schematic writer and `model.validate` with their output unchanged.
- `fenolite check` marks every DRC type whose count reached the limit of KiCad's report (499 entries of `clearance` and `unconnected_items`, 199 of any other type): `summary.limits` of the stage `drc.kicad` and one `check.report-limit` warning per type; such a count is a lower bound. Status and exit code do not change (c0141). A reply of a board under every limit gains `"limits": []`; `null` says that nothing is known. The limits are measured on an authored bench with `kicad-cli` 10.0.6; the 9.0.9 counts of 2026-10-05 wait for their recorded probes.
- **Footprints from the built-in catalog and from `dsl.Footprint` now carry `Reference` and `Value` on the board and in the project library, so a catalog-only board passes `check`. Projects built before gain the two properties on their next build: this is the first change of KiCad bytes since 0.2.0, and only for these footprints.** Altium projects do not change. (c0077) The two fields are generated 1 mm above (`Reference`, `F.SilkS`) and below (`Value`, `F.Fab`) the footprint's extent box, and `Part.field` moves or hides them. **A library footprint that lacks one of the two now gets it on the board too, with the new info `build.field-added`: a `Part.field` request for such a field, which ended in `FEN-3004`, now builds.** **`fenolite build --target altium` of a design that names catalog symbols or footprints and declares script copper no longer stops with `FEN-3001`**: the KiCad build that resolves the copper takes the catalog's definitions too. Verified on `kicad-cli` 9.0.9 and 10.0.6 (`H-K-FP-FIELDS`, `KICAD-VERIFIED (9.0.x, 10.0.x)`; the `kicad-9` and `kicad-10` jobs of CI run 37772583226 pass `tests/kicad/build/test_catalog_only.py`).
- **New command `fenolite fetch freerouting`** (c0078): downloads the pinned Freerouting jar from its publisher after `--confirm`, checks its size and SHA-256 and installs it in the user's tools folder, where `route --router freerouting` finds it; no other command downloads anything (ADR-0007). `--dry-run` shows the file, its size, its digest, its address and its licence (GPL-3.0) and makes no request; `--from FILE` installs a copy you already have, with the same check; `--dir DIR` chooses another folder. The tools folder is `FENOLITE_TOOLS_DIR`, else the cache folder of the platform (`~/Library/Caches/fenolite/tools`, `%LOCALAPPDATA%\fenolite\tools`, `~/.cache/fenolite/tools`). The command installs no Java: Freerouting still needs Java 25 or newer. **Changed messages:** without a jar, `fenolite route --router freerouting` still exits 6 with `FEN-6001`, and its message and hint now name `fenolite fetch freerouting --confirm`; the `freerouting` entry of `doctor`'s `result.routers` gains `source` (`argument`, `env`, `fetched` or `null`). Two new error codes: `FEN-6003` (exit 6, retryable: the download failed) and `FEN-3006` (exit 3: the bytes do not have the pinned size or SHA-256; nothing is written). `--router-path` and `FENOLITE_FREEROUTING_JAR` work as before and win over the tools folder. The `routing` jobs of CI install their jar with this command, which proves the pinned address, size and digest on every run (`H-G-FETCH-PIN`); the decision that allows the download is row 36 of the roadmap's "Open decisions" (ADR-0007).
- `design.board(copper=…)` takes 6 and 8 copper layers (c0100): zones, planes and script copper on every inner layer, the KiCad layer table KiCad itself writes, proved through fill, DRC and export on KiCad 9 and 10 (the KiCad 9 half runs on two committed filled boards; `H-K-PCB-LAYERS` and `H-K-BUILD-LAYERS` are `KICAD-VERIFIED (9.0.x, 10.0.x)`, and the `kicad-9` and `kicad-10` jobs of CI run 37772583226 pass them); `Design.copper_layers`; a rebuild names the board's count when it differs, and `layout.copper-mismatch` hints at `copper=<the board's count>` and `--discard-layout`; the hint of `build.plane-not-lowered` names the `design.zone(…)` call instead of a step in KiCad; `--target altium` writes the six- and eight-layer document with the stack of c0085. `fenolite.dsl.design.INNER_LAYERS` and `layers.INNER_ROWS` are replaced by `inner_layers(copper)` and `inner_rows(copper)`.
- `fenolite route` selects the nets that still have open connections, so a second run and script copper can share a net; `routed` and `unrouted` now come from the board after the merge, copper of nets left open is kept, and `--require-complete` exits 5 and writes nothing when a selected net stays open (c0108). Tracks, arcs and vias carry `locked`, read from and written to KiCad boards; `--rip` keeps locked and script copper; `Design.track`, `via` and `stitch` take `locked=`. `fenolite net` gives `islands` and `open` per net. `routing.select.unrouted` takes `open_nets`. An Altium build writes the lock of a locked track, arc or via, or warns with `altium.not-lowered`; the Altium import reads it. **Releases 0.2.x and 0.3.x cannot read a model document that carries the key `locked` on a track, an arc or a via.**
- **`fenolite export` writes IPC-2581, ODB++, STEP, board PDF and DXF per layer, and the schematic PDF** (c0116; `--ipc2581`, `--odb`, `--step`, `--pdf`, `--dxf`, `--sch-pdf`); `--all` still selects the four fabrication kinds, and a preset changes no document kind. A STEP gets the 3D models that Fenolite locates, reported with their source and SHA-256 in `result.models`; a missing model is a warning. A schematic whose hierarchy names a sheet that cannot be given to the run is refused (`export.sheet-missing`), and a board that does not fit its page gives the warning `export.page-too-small`. `result.repeat` says which hashes compare between exports. New command `fenolite models` lists the models of a board and copies them into `3dmodels/` with `--vendor`; `tools/kicad_libs_fetch.py --models` fetches single files of the official 3D library (no fetch was run yet). `LibraryResolver.missing_models` now also finds a model in the project's `3dmodels/` folder, in the install and in a fetched cache, so it can report fewer warnings than before. The document kinds and `fenolite models` carry `INFERRED`: their probes are recorded for `kicad-cli` 10.0.6 and not yet for 9.0.9.
- Board stack-ups (c0101): `read_board` fills `Board.stackup` from a KiCad stack-up that KiCad uses, created boards whose model holds a stack-up get the complete node and a matching board thickness, and scripts declare one with `design.stackup()` and `fenolite.dsl.stack` (the board's stack-up wins over an unlocked script one). `analyze` takes its thicknesses from it, `export` notes a job file that will state KiCad's default, and `inspect` shows it. New warnings name a stack-up that KiCad ignores and a board thickness that differs from its layers. An Altium build writes a stated core or prepreg, passes masks over and names what the document does not hold. A design without a stack-up builds the files it built before. **Changed: a board whose model holds a stack-up and that is created for KiCad (for example a model imported from Altium) now gets the `stackup` node in `setup`, and is refused with `kicad.board.stackup-invalid` when its copper entries are not the board's copper layers.** **Changed: `export --gerbers` of a board without a stack-up reports one info, `export.stackup-default`; an info does not stop the writes of `export`: only an error does (a warning does not either, since c0116).** **Release 0.2.x cannot read a model document that carries the new keys** (`dielectric_kind`, `color`, `impedance_controlled`). Stack-ups are written for 2, 4, 6 and 8 copper layers. `stack.preset(name)` gives the entries of a stack-up that one public fabricator page states, for `design.stackup(*stack.preset(name))`: `two-layer-1.6mm`, `four-layer-1.6mm` and `six-layer-1.6mm` (`stack.PRESETS`; sources S-0720 to S-0722, `INFERRED`), and the guide page `rules` teaches them. The job file, completeness and default rows of the stack-up facts are `KICAD-VERIFIED (9.0.x, 10.0.x)`, the re-save rows `KICAD-VERIFIED (10.0.x)`, and so is `backends.kicad.stackup.EVIDENCE`.
- `fenolite analyze` gains power paths (`[[path]]`, `--path`, `--kinds power`): the copper on the path, its narrowest sections and via groups, capacities judged where the whole current flows, and a bounded resistance and drop from a resistivity you give; insulation between layers (`--kinds insulation`, `insulation_nm`); creepage that bridges grooves narrower than your groove width (`groove_nm`, `--groove-width`). Creepage and clearance now cross copper of other nets, or of none, at no length and name it, so they can be shorter than before; a judged creepage that passes a groove without a groove width now warns. The capacities and the drop are estimates against your limits, not a simulation, and Fenolite ships no resistivity, groove width or insulation distance. **A reply without the new kinds changes too:** each measure holds `over`, `result.inputs` holds `paths`, `resistivity_pohm_m` and `groove_nm`, the evidence names `H-G-AN-OVER`, and a board with a graphic on a copper layer now gets a warning in the distance analysis. **Not yet usable on a real board:** the insulation between layers and the resistance of a via group need the depths of the stack-up, which the model gets with change c0101; until then the reply says that the stack-up is missing. A requirements file that holds a `[[path]]` row, `insulation_nm` or `groove_nm` is refused by 0.2.x and 0.3.0 (c0115).
- Via protection (c0112): `protect()` and `protection=` on `Design.via`, `via_step` and `Design.stitch`, and `Design.via_protection()` for the board default. KiCad boards read and write tenting, covering, plugging, capping and filling per via and in `setup`; target 9 holds tenting only and refuses the others (exit 7). `inspect` reports `via_protection`. **Changed:** a KiCad 9 board with via tenting, rebuilt for target 10, now keeps the mask that 9.0.9 plots, and a protection set in KiCad on a script via is reported when the build replaces it. Altium: the build writes a via's tenting where the design states it, the import reads the tenting flags into the model (**every imported via gains explicit tenting**), and the four other features are named and not written. A design that states no protection builds the files it built before, for KiCad and for Altium. 0.2.x and 0.3.0 cannot read a `board.json` that carries `protection` or `via_protection`.
- **The agent guide ships in the package** (c0079): `fenolite guide` prints it, `fenolite skill install` copies it to an agent's skill folder or adds a pointer to `AGENTS.md`, and `fenolite init` writes a starter project that builds with the built-in catalog and that the built-in router closes; `capabilities --brief` and `capabilities --command NAME` give a small first reply (6.0 kB for 35 commands, against 21.9 kB) and a command's arguments as data. **`agent/SKILL.md` moved into `src/fenolite/agent/skill/`**, and its loop block now starts from an empty folder: `capabilities --brief`, `init blink`, `build`, `place`, `route --router direct`, `fill`, `check`, `export`, `render`. `inspect` left the block for the page's section on small questions. A command can print a text of its own in text mode (`Result.text`), which is how `fenolite guide start --text` prints a page; the JSON output of every existing command is unchanged, and the default result of `capabilities` gains only the entries of the three new commands. `skill install --agent claude-code` writes to `.claude/skills/fenolite`, and `--dir DIR` serves every other agent. The block is proved on KiCad 10.0.6 for projects of both majors and on KiCad 9.0.9 for target 9 (`H-K-GUIDE-STARTER`, `KICAD-VERIFIED (9.0.x, 10.0.x)`, by the `kicad-9` and `kicad-10` jobs of CI run 37772583226).
- A yardstick example of about 370 parts (`examples/yardstick`), taken through the loop every night by `tools/yardstick.py` with time and memory budgets per step, and a record of its runs in `docs/evidence/yardstick.md` (c0119). The board is an invented controller of eight identical 48 V buck channels with an isolated high-voltage sense section, on KiCad's official libraries; it is at stage 5 of five: six copper layers with a declared stack-up and inner planes, a board outline with rounded corners, slots under the isolators, plated mounting holes with keep-outs, a high-voltage rule area, the USB pair's rules and impedance target, thermal via arrays, placement rules, a net tie, fiducials, tooling holes and test points (388 parts). The runner also routes it (KiCadRoutingTools for the pair, Freerouting for the rest, with a budget of 3600 s), refills it, judges the routed board against ratchets of open connections and DRC errors, runs the analyses of the high-voltage gap, exports the document kinds and drawings and the test-point report, and reads and round-trips the two heavy demo boards of the corpus. `make yardstick` runs it locally. The job `yardstick` of `nightly.yml` is not a merge gate; its first passing run (37836196244, dispatched on the release branch) reached stage 5 with 459 open connections and 78 other DRC errors on the routed board, within the ratchets, but one run is not three: the budgets of `tools/yardstick_budgets.toml` are provisional, from local runs, and the ratchets are bounds until the first three scheduled runs. Building it found that `Design.stackup()`, `Design.rule_area()` and the board drawings refused a board declared with `board(outline=…)` (fixed, see below), so the example had a rectangular outline until that repair.
- **`fenolite route --timeout` now bounds the whole routing step for every router** (c0109): it bounded each net for KiCadRoutingTools, and 600 stood for the default. `route` keeps the copper of every router run that finished in time and reports the rest with `route.budget-exhausted` (a warning, exit 0; it was `route.tool-failed`, exit 5, and no copper); run `route` again to continue with the nets still open. KiCadRoutingTools routes groups of nets of equal sizes in one process, with `--escalation off` and without `--clearance` (`--router-option group-nets=N` splits a group); a net that does not fit at the requested sizes now stays open instead of being routed narrower. Freerouting is given only the nets of the job (a net outside the job whose class clearance is larger than the default rule stays declared, `route.net-declared`) and runs without its optimizer unless `--router-option optimize=on` (`route.optimizer-cut`), so its routes may hold more vias and detours than before. New `--order GLOB` routes the matching nets first, in tiers; new result keys `budget`, `runs` and `not_attempted`. For plugin authors: `RoutingJob.budget`, `JobNet.tier`, `RouterRun`, `RoutingResult.runs` and `not_attempted`, `routing.budget.Budget`; the constructors of both plugins take `budget` where they took `timeout`, and `write_dsn` takes `others`. No model or schema change.
- **Pads keep KiCad's fabrication marks, scripts place fiducials, test points and tooling holes, and a new command reports them** (c0118). Pads keep KiCad's fabrication marks (fiducial, test point, BGA, heatsink, castellated, mechanical, press-fit) in the model as `Pad.fab_property`, read and written on boards and in footprint files; authored pads take `fab_property=`. New command `testpoints`: test points, fiducials, holes, net coverage and the user's targets (`--min-coverage`, `--min-pitch`, `--min-fiducials`), and a CSV, with `--manifest` its entry of kind `testpoints`. Placement tables mark fiducial rows (field `fiducial`, key `fiducials` of `[placement]`). An Altium build writes a part with a marked pad as before and names the unwritten marks in one `altium.not-lowered` info ("pad properties"), also for library footprints such as BGA packages. `Ipcd356Record` gains `covered`, the mask code of a record. A script places fiducials, test points and tooling holes with `design.fiducial()`, `design.test_point()` and `design.tooling_hole()`, whose footprints and symbols are generated in `Fenolite_Assembly` and whose fiducials and tooling holes get a copper keep-out (`clear_<ref>`, through `rule_area`) and are locked. An Altium build writes test points as parts, leaves fiducials out with one `altium.not-lowered` info ("assembly features"), and writes a tooling hole as a board hole, as every hole of `design.hole()`. Releases 0.2.x and 0.3.0 cannot read a model document that carries `fab_property`. The KiCad facts are recorded for 10.0.6 and 9.0.9.
- `tools/agent_eval`: five authored tasks, a judge that uses `fenolite check` and the expected nets, a log of every `fenolite` call, and a runner that starts a fresh agent on one task in a clean environment. Reference solutions are replayed by the test suites; runs with a real agent are started by hand and recorded in `docs/evidence/agent-eval.md` (c0081). Nothing of it is in the package and no command changes. `make agent-eval TASK=<name> RUNNER=replay` plays a task's solution without any agent. A real agent costs money: the runner refuses one while `CI` is set, and without `--yes` it prints the budget and starts nothing; the first row for a real agent is written from its public documentation and stays `unconfigured` until the maintainer has checked it. No run with a real agent is recorded: **the first runs with a real agent are deferred to the next release** by the maintainer's decision of 2026-10-08. Writing the tasks found one defect, fixed since by c0143 (released in 0.2.2 and 0.3.0): a design that names the built-in catalog and a `Power(...)` interface does not build (`build.vendor-unsafe-name`, the libraries `Fenolite` and `fenolite` differ only in letter case), so a catalog part with a power input pin cannot pass KiCad's ERC from a connector supply; the task `regulator-zone` uses a Zener shunt regulator for that reason.
- `route` joins the SMD pads of plane nets to their planes with fan-out vias before the router runs, and never traces a plane net (c0107); `--no-plane-fanout` skips the step, and `result.plane_layers` and `result.plane_fanout` report it. Copper layers of type `power` are plane layers, and **`board(planes=…)` now sets that type on KiCad boards: the board of a script that declares planes changes in those rows, also on a rebuild; a script without planes builds the bytes it built before.** A plane without a zone of its net gives `build.plane-zone-missing`. The Specctra file declares plane layers and planes, keeps classes to their layers, and carries class clearances, class-to-class clearance and per-layer widths; the rules it cannot carry, the edge clearance among them, are reported (`specctra.rule-not-sent`). `route` now reads the project's rules file. New rule kind `no_tracks` (`disallow track` in KiCad, for target 10 until its probe is recorded on 9.0), which an Altium build reports as not lowered. **Releases 0.2.x and 0.3.x cannot read a model document that holds a `no_tracks` rule.** `build.plane-not-lowered` is no longer given.
- **Net ties, waivers and check severities** (c0114). Net-tie pad groups are read, written and authored (`Footprint.net_tie`), and the copper check no longer reports two pads of one group: a board whose tied pads touch, or sit closer than the clearance, loses those `copper.short` and `copper.clearance` findings in `check` and in the build's copper guard. `design.waive()` accepts one `copper.*` or `kicad.drc.*` finding with a reason, which `check` and the build's copper guard then list as `info`, and `check` reports waivers and KiCad exclusions that no longer match (`check.waiver-unmatched`, `check.exclusion-stale`); `design.rules.severity()` sets the severity of a KiCad DRC check in the project file. Waivers also apply to `check` on a built Altium project and to the copper guard of the Altium build; the Altium build reports net-tie groups and severities instead of writing them. **Output changes:** the result of `check` gains `waivers`, `result.copper_check` of `build` gains `waivers`, the summary of `copper.clearance` gains `net_tie_pairs` and that of `drc.kicad` gains `exclusions`, and the issue of a DRC entry that the KiCad project excludes now ends with ` (excluded in the project: <comment>)`. The model gains three keys, each omitted when unused, so a design that uses none of them builds the same bytes: `net_ties` (`board.json`, `library.json`), `waivers` (`findings.json`) and `severities` (`rules.json`); 0.2.x cannot read a document that carries one of them. KiCad's verdicts are proved on `kicad-cli` 10.0.6; the 9.0.9 runs are owed.
- Script copper can be given in a part's frame (c0111): `part.at(dx, dy)` and `part.pad(n).at(dx, dy)` stand wherever a point is taken, and the build resolves them after placement, so vias, waypoints and stitches follow a moved part at the next build. `design.stitch(region=part.pad(n))` makes a thermal via array inside a pad. `part_frame` gives the same points to the Python API. `via_step` and `Design.via` also take their point as one argument, an anchor or an `(x, y)` pair; the two-length forms work as before, and a script without anchors builds the same bytes. No model, schema, CLI or issue-code change: an anchor that cannot be resolved and a pad that cannot hold an array use five existing `kicad.copper.*` codes (`docs/copper.md`). A via of another net anchored inside a pad passes KiCad's DRC, which gives it the pad's net; the copper guard of `build` refuses it. Measured on `kicad-cli` 10.0.6; the same probes on 9.0.9 are pending, so `H-G-FRAME-ANCHOR` and `H-K-VIA-IN-PAD` are `INFERRED`.
- `export --fab-drawing` writes a fabrication drawing (outline and its dimensions, board, stack-up, drill and
  impedance tables, numbered notes) with KiCad's drill maps and report, and `--assembly-drawing` top and bottom
  assembly drawings, all plotted by `kicad-cli` from a copy of the board; `--drawing-spec FILE` sets paper, sheet,
  tables, notes and assembly options; the drill counts are checked against KiCad's report (c0117;
  `docs/drawings.md`). The impedance table has no row yet, and the stack-up table waits for stack-ups read from
  KiCad boards (c0101). The kinds are `INFERRED`: their probes hold on `kicad-cli` 10.0.6 and are not yet recorded
  on 9.0.9.
- **The agent guide teaches how to design a board** (c0080): eleven pages (`fenolite guide <topic>`) on the design script, parts, footprints, placement, routing, rules, checks, reading and comparing files, fabrication files, the Altium target and recovery, plus generated command and DSL references (`tools/gen_agent_guide.py`, whose `--check` runs in `make check-fast`, with the lint step). Every command line, design script and recovery recipe of the guide is run by tests, and **a new command, DSL name or error code must be added to it**: `tests/unit/agent/test_pages.py` names what is missing. The start page keeps its loop and gains the index of the pages; its line on `fenolite manifest` no longer names an artefact folder outside the project, which that command refuses. The page `design-script` says that a `Power` builds with catalog parts (c0143), and the page `routing` teaches the anchors of script copper, `part.pad(n).at(dx, dy)` and `part.at(dx, dy)` (c0111).
- Rule areas and keep-outs (`design.rule_area`), board texts, drawings and dimensions (`design.text`, `line`, `rect`, `circle`, `arc`, `polygon`, `dimension`) and rules scoped to an area (`select.area`, written as `intersectsArea`) from the script (c0103); script items are regenerated on every build. `check` and the copper guard of `build` apply area rules and report copper in a keep-out as `copper.keepout` (`--copper-check warn` writes anyway); a rule naming no rule area stops the build (`build.area-unknown`). With `--target altium` rule areas with a restriction and centred texts are written, and an area's name, an area for rules only, a justified text, a dimension and a rule with an area selector are reported. **Release 0.2.x cannot read a model document that carries the new keys** (`name` of a keep-out, `h_justify`, `v_justify`, `dimensions`, the selector `area`). A rule with an area selector is written for KiCad 9 and 10: its probe `dru-cond-area` is recorded for 10.0.6 and, since the image run of 2026-10-08, for 9.0.9. The rule-area, text, dimension and keep-out facts are `KICAD-VERIFIED (9.0.x, 10.0.x)` (the re-save of an area's name and of a dimension's text on 10.0.6 only), confirmed by the `kicad-9` and `kicad-10` jobs of CI run 37772583226; every name a created dimension writes is a name of the 8.0 format (the 8.0.0 demo boards, S-0723, and the format page, S-0001). **`fenolite check` can exit 5 where it exited 0**: on a board whose copper lies in a keep-out, and on a board whose hand-written `intersectsArea` rules are now applied by the copper stage. The summary of the copper stage gains `keepouts` and `rule_areas`, `result.pcb` of an Altium build gains the kind `dimension`, and a KiCad board read with a named rule area, a justified text or a linear dimension now holds them in the model.
- Differential pairs in KiCad (c0104): class pair width, gap and via gap (`diff_pair_width`, `diff_pair_gap` and `diff_pair_via_gap` on `design.rules.netclass()`, written to and read from the project file); rule kinds for pair gap, uncoupled length, skew and length (`diff_pair_gap`, `diff_pair_uncoupled`, `skew`, `diff_pair_skew`, `length`); `select.pair()` and `design.rules.pair()`; the copper check lowers the clearance inside a pair as KiCad does, so `check` stops reporting a coupled pair that is below its class clearance and at or above its class pair gap; pair names with digits after the P or N are recognised (`D_P0`/`D_N0`), so `build.diff-pair-name` stops warning on them. `build.interface-not-lowered` is now given only for a pair that no rule selects, and the new warning `build.diff-pair-gap-shadowed` names a pair that KiCad would report at its class gap. A hand-written `.kicad_dru` with pair rules now lifts them into the model. The pair kinds and the pair selector are written for KiCad 10, where every probe is recorded on 10.0.6; for target 9 they are refused (`rules.kind-unchecked`, exit 7) until their probes are recorded on 9.0.9. **0.2.x and 0.3.0 cannot read a `circuit.json` or a `rules.json` that carries the new keys, kinds or the `diff_pair` selector.** An Altium build names pair rules, class pair values and pair interfaces (`altium.not-lowered`) and writes none of them.
- **Outlines with arcs and cut-outs, holes, and rebuilds that follow a new outline or copper count (c0102).** A script can give the board an outline with arcs and cut-outs (`board(outline=…)`, `cutout()`, `fenolite.dsl.shape`) and holes (`design.hole()`); authored footprints accept unnumbered hole pads. A rebuild now follows a new outline or copper count: copper that no longer fits, or that lies on a removed layer, is dropped and reported, and a stale stack-up is removed. Outline edges carry new uuids from the first build after this change. With `--target altium` an outline with arcs plans no PCB document, a round hole that is not plated is written, and a slot or a plated hole is reported. **Release 0.2.x cannot read a model document that carries the new key `arcs`.** Rebuilds that stopped with `layout.copper-mismatch` for a count change, or kept an old outline with `layout.outline-kept`, now apply the script: run them with `--dry-run` first to read the counts of `kicad.outline.copper-dropped` and `kicad.layers.removed`. An outline edited in KiCad still wins unless the script says `board(..., locked=True)`. The symbol library writer of authored symbols now writes `in_bom`, `on_board` and `exclude_from_sim` of the definition, where it wrote `yes`, `yes` and `no` for every symbol. The outline, hole and layer-change facts are `KICAD-VERIFIED (9.0.x, 10.0.x)` (the zone box `KICAD-VERIFIED (10.0.x)`): KiCad 9.0.9 reports `invalid_outline` for two overlapping cut-outs only, where 10.0.6 also reports a cut-out across or touching the edge and a self-crossing ring, and Fenolite's own check refuses all of them for both targets.
- Placement rules (c0113): `design.near()` for decoupling, crystal and gate-driver proximity. `fenolite check` gains the default stage `placement.rules` (rules of a built project, wire length and congestion of every board), on KiCad projects and on Altium documents; `place` reports the same numbers (`result.rules`, `result.measures`) and refuses a part in a keep-out that forbids footprints, as KiCad's DRC does (`place.keepout`), and its grid leaves such areas free; `build` reports rule findings as warnings (`result.placement.rules`). On a built project with rules, `check` can now exit 5. An Altium build stores the rules and says in one `altium.not-lowered` info that it did not judge them. A `rules.json` with `proximity` cannot be read by 0.2.x or 0.3.0. `rule_area(forbid=…)` takes `footprints`, which was refused: the area is then a placement keep-out (`(footprints not_allowed)` in KiCad; one `altium.not-lowered` info of kind `keepout-footprints` in an Altium build). The keep-out rule is recorded on KiCad 10.0.6 and waits for the KiCad 9 run of CI (`H-K-PLACE-KEEPOUT`).
- **A board whose zone or rule area holds `(layer "*.Cu")` can be rewritten** (c0145): the layers of a zone written under the singular head with a wildcard or a mask (`(layer "*.Cu")`, `(layer "F&B.Cu")`) were read, and then every rewrite of the board, unchanged, was refused with exit 7 (`field 'layers' cannot be written from the model`): `route`, `place`, a rebuild and `write_board`, in 0.2.1 too. The child is now kept as written, as under `layers`. A single layer written under `layers` is kept as well instead of being respelled, and a changed layer set over a wildcard is refused under both heads. KiCad 10.0.6 itself does not load a wildcard under `layer` (`docs/formats/kicad/board.md`, `H-K-ZONE-LAYER-HEAD`), so `fill` and `check` still fail on such a board with the tool's message.
- Net lengths as KiCad 9 and 10 count them (tracks, arcs, via heights from the stack-up, die lengths), pin-to-pin lengths and pair skew in `fenolite analyze --kinds length --net GLOB [--from REF]`, a `length.rules` stage in `check` for length and skew rules, and `Design.meander` to bring a script track to a target length or to the length of another script track (c0106). The total follows the major of `--kicad-version`: the two majors count a via apart, and a file without a stack-up is counted on the default stack-up KiCad assumes, with the info `kicad.length.default-stackup`. `result.lengths` gives each net's parts, its paths from a start pad and the copper on no path; new codes `analysis.length-open`, `analysis.length-stub`, `kicad.length.bad-die` and eight `kicad.meander.*`. `fenolite build` resolves meanders right after script copper and reports `result.copper.meanders` when a script holds one; a script without meanders builds the same bytes. The routed lengths of `fenolite net` and of `equivalent --level 5` now come from the same kernel functions (`geometry.arc_length`, `segment_length`), with the same values to the nanometre. `result.pairs` gives the skew of each differential pair (a pair interface of the design, or two nets the pair name rule couples). The default stage `length.rules` of `fenolite check`, right after `copper.clearance`, judges the `length`, `skew` and `diff_pair_skew` rules of change c0104 on those totals without `kicad-cli`, as KiCad does (`min` and `max`, not `opt`; a net of pads only at length 0; skew against the longest net of each group, each pair apart for `diff_pair_skew`), with the new codes `length.out-of-range`, `length.skew-out-of-range` and `length.input-missing`; it runs on KiCad input only, and `check` on Altium input keeps its stage list. The canaries are recorded for `kicad-cli` 10.0.6 and not yet for 9.0.9, so every reply carries `INFERRED`; an Altium document is measured without via heights and is `UNVERIFIED`.
- **A reviewed plan is written as reviewed, a command writes all its files or none, and a long step reports progress** (c0120). A dry run returns `result.plan_id`, and `--confirm --plan ID` writes the reviewed bytes without running the command again (`FEN-4002`, exit 4, when a target or an input changed). A command writes all its files or none; a failed write gives `FEN-1002` (exit 1, retryable) instead of a traceback. **Changed:** a command that reports an error finding writes nothing, `place --force` excepted (`manifest` and `kit record`, whose write is the report of the findings, still write); a writing command that reports an error without `--confirm` now exits 5, not 4. A stopped command (SIGTERM, Ctrl+C) stops its tools and gives `FEN-1003`. `--progress` writes progress records on stderr. `route` reuses the copper of router runs that finished before a stop (`result.resumed`, `route.resumed`). **Changed:** exit 1 is a bug only when `retryable` is false; the hint of `FEN-4001` names `--confirm --plan <id>`; every plan carries `result.plan_id` and every receipt `plan`; `capabilities` lists `global_flags` and `mutation_flags`; `route` returns `resumed`. Dry runs now write under `~/.cache/fenolite/state` (`FENOLITE_STATE_DIR`; `off` turns it off).
- `fenolite route` gives differential pairs and escape requests only to a router that routes them (`features` in `fenolite capabilities`), or the pair nets as single nets with `--pairs-as-nets`; every other pair gives `route.pair-skipped` (c0110). `--escape REF[=grid|perimeter]` names parts to escape (`route.escape-skipped` without the feature); Freerouting runs without automatic neck-down and takes `fanout=off`; routed copper narrower than asked gives `route.width-below-job`. The KiCadRoutingTools pair (`route_diff.py`) and escape (`bga_fanout.py`, `qfn_fanout.py`) steps exist; after the gate of c0110 KiCadRoutingTools declares `pairs` and not `escape` (below); Freerouting's design file holds no `pair` list. No model or schema change.
- Impedance targets per net class or pair (`design.rules.impedance()`, `trace()`), checked by derived rules on KiCad 9 and 10 and written as KiCad 10 tuning profiles; build warnings for shadowed rules, class values, gaps and an unmarked stack-up; `fenolite impedance` with the table for the fabricator and `INFERRED` estimates of single-ended lines; an Altium build keeps targets in the model and names them; 0.2.x and 0.3.0 cannot read a `rules.json` that carries the key `impedance` (c0105). The KiCad probes of the change (`pro-tuning-*`, `dru-impedance-width`) are written and not yet recorded.
- A part can state its height (`Part(height=…)`): it becomes a body of its footprint, kept in `.fenolite/`, and `design.height_limit(area, max=…)` limits the parts under a named rule area. `check` (stage `placement.rules`), `place` and `build` report `placement.too-tall` and `placement.height-unknown`. A part's height has one source, its bodies, read by `outward_height`. A `rules.json` with `heights` cannot be read by 0.2.x or 0.3.0 (c0140). **Not yet complete:** the signed body bounds of change c0099 are not on this line, so `outward_height` reads each body's `height`; on the Altium target a limit gives `placement.rule-unresolved`, because a PCB document holds no rule-area name, and a script height is reported as a body without an outline (`altium.not-lowered`, `body/<id>`) and not written.
- Copper findings carry hashable rule candidate explanations for the actual clearance judgment; relation/source grouping preserves every finding without advice or exemptions, with unchanged numeric verdicts and CLI output (c0097).
- **Signed component body volumes:** known Altium imports serialize z_min/z_max equal to source standoff/height; negative standoff no longer produces model.body-height. Mounted-face volume analysis reports intersections and missing inputs conservatively (c0099).
- **Retained unknown bodies:** malformed heights (stored as 0), reversed extents, unsupported model types and mismatched projection sides are retained with projection_unknown and a warning, without model.body-height or an unmapped census entry (c0099).
- **Body document compatibility:** v0.2.0 body documents retain defaults, bytes and legacy validation until reimport; the readers of releases 0.2.x and 0.3.0 reject documents with new body keys (c0099).
- Add mechanical intent metadata (`MechanicalIntent`, `Part.place(..., locked=True, anchor=...)`), group-bounded constrained placement with injected checkers (`fenolite place --strategy constrained --constraints FILE`, schema `fenolite.placement-request.v0`), explicit incomplete assessment and confirmed readback copper previews for both faces. Holes and keep-outs of a script stay `design.hole()` and `design.rule_area()`: the hole and keep-out calls of the c0096 branch are not part of this integration (the maintainer's decision of 2026-10-07). `Hole.intent`, `Keepout.intent` and `FootprintInstance.anchor` are model fields that builds do not persist (c0096). Releases 0.2.x and 0.3.0 cannot read a `board.json` that carries `intent` or `anchor`.
- The explanation of a copper finding between the two nets of a differential pair holds the row `pair-gap:<class>` that governs it (c0104 with c0097), and `fenolite place --strategy constrained` judges supplied volumes with the body-volume check of c0099 and takes each copper finding's relation from c0097, where it computed its own (c0096, task R5). No verdict changes.

### Changed

- The layer-table benches of c0100 write the created test board without its stack-up, so they judge the layer table alone; a stack-up whose copper entries are not the board's copper layers is refused by the board writer on a created and on a read board alike (`kicad.board.stackup-invalid`), which the requirement of c0101 now states and a test pins. No behaviour of the library changes (c0101).
- The README of the agent evaluation tasks says in one sentence which licence covers what: the task scripts carry the `Apache-2.0` header that the SPDX guard demands of every `.py` file, the task texts are `CC0-1.0` (c0081).
- The probes that the v0.4 changes registered for KiCad 9 have their 9.0.9 outcomes, measured in the pinned image (57 rows of `docs/evidence/kicad/probes/9.0.9.json`). **A rule of the kind `no_tracks` is now written for target 9 too** (`dru-kind-no_tracks` is `present` on 9.0.9); it gave `rules.kind-unchecked` there before. Three outcomes differ from their tests on 9.0.9 and are recorded as measured: `drc-limit-hole_clearance` and `drc-limit-keys` (`different`), and `route-fanout-t9` (`inconclusive` in a container without `kicad-cli` 10).
- The fan-out oracle of c0107 is judged on KiCad 9 wherever it runs: the two target-9 boards of its case, filled by KiCad 10.0.6, are committed under `tests/data/kicad/routing/`, and a run on 9.0 without a `kicad-cli` 10 reads them after checking that they are the boards it built and routed. `route-fanout-t9` is `equal` on 9.0.9 in the pinned image (it was `inconclusive`). No behaviour of the library changes (c0107).
- Three probes of c0108 are pinned on KiCad 9 as well: `pcb-lock-load`, `copper-open-kicad` and `copper-open-parity` are registered for both majors and recorded `equal` on 9.0.9 in the pinned image; they were registered for KiCad 10 alone and measured on 9 by hand. No behaviour of the library changes (c0108).
- The probes that the changes stacked after the first 9.0.9 run registered for KiCad 9 have their 9.0.9 outcomes, measured in the pinned image (173 more rows of `docs/evidence/kicad/probes/9.0.9.json`, 723 in all). **Rules with an `area` or a `diff_pair` selector and rules of the kinds `diff_pair_gap`, `diff_pair_uncoupled`, `skew`, `diff_pair_skew` and `length` are now written for target 9 too** (`dru-cond-area`, `dru-cond-diff_pair` and the five `dru-kind-*` probes are `present` on 9.0.9); they were refused there before (`rules.unsupported-selector`, `rules.kind-unchecked`). One outcome differs from its test on 9.0.9 and is recorded as measured: `outline-invalid-selfx` is `absent` (9.0.9 reports no `invalid_outline` for the self-crossing ring of the bench).
- The height of a part (`fenolite.model.board.outward_height`, c0140) now takes the `z_max` of a body with signed bounds and skips a body of unknown projection, so the height limits of `check`, `place` and `build` judge an imported Altium body by its signed bounds (c0099).
- **The copper check on Altium input passes copper up to 9 nm inside a clearance rule, where it passed 5 nm** (c0152). Altium Designer 26.5.0's own rule check reports none of the seven pad-to-track findings that Fenolite gave on the public document `altium-third-party-pcbdoc-03`, 8 and 9 nm short of a 5 mil rule (S-0616). The cause is not Fenolite's reading: the document's own integers put the track 3.5 file units (8.89 nm) inside the rule, and Fenolite reads the gap to within 0.11 nm; Altium allows at least that much. Every clearance rule of a PCB document is now lowered by 9 nm, that observed tolerance in whole nanometres (`CLEARANCE_SLACK_NM`; the unit's 5 nm of c0131 is inside it), documented in `docs/formats/altium/import.md` as `ALTIUM-VERIFIED(author-report)`. On the eight public PCB documents the class of findings 8 to 20 nm short goes from 25 to 9 (0 on `-03`, 1 on `-01`, 8 on the heavy one), all 10 to 20 nm short, and they stay errors. KiCad boards are judged strictly at the nanometre, as before.
- The fact rows of differential pairs (c0104) in `docs/formats/kicad/rules.md`, `project.md` and `copper.md` say `KICAD-VERIFIED (9.0.x, 10.0.x)`, as their five hypothesis rows do: the `kicad-9` job of CI run 37772583226 passed the pair rules, names, classes, copper parity and rule design tests on 9.0.9.
- Impedance targets (c0105): `dru-impedance-width` (both majors) and eight `pro-tuning-*` probes (KiCad 10) are pinned in the probe files from CI run 37772583226, and `H-K-DRU-IMPEDANCE` is `KICAD-VERIFIED (9.0.x, 10.0.x)`. The KiCad 10 GUI save that settles the keys of a tuning profile (`H-K-PRO-TUNING-KEYS`) is deferred to the next release, so tuning profiles stay `INFERRED`.
- Net lengths (c0106): `H-K-NETLEN-TOTAL`, `-STACKUP` (2 to 8 copper layers), `-RULES` and `-MEANDER` are `KICAD-VERIFIED (9.0.x, 10.0.x)` and `-VIA9` `KICAD-VERIFIED (9.0.x)`, from the `kicad-9` and `kicad-10` jobs of CI run 37772583226; the roadmap moves matched-length and skew analysis from v0.6 to v0.4.
- `tests/routing/test_krt_gate.py::test_planes` (c0107) routes the plane bench through KiCadRoutingTools with and without a `no_tracks` rule, needing a checkout and no `kicad-cli`; v0.22.1 put every track on `F.Cu` in all three runs, so `H-K-KRT-PLANES` is recorded `inconclusive` and the plugin keeps `route.constraint-not-sent`. The plane fan-out is `KICAD-VERIFIED` (`backends.kicad.fanout.EVIDENCE`), and the routing page of the agent guide shows `route` on a board with `planes=` and `result.plane_fanout.failed`.
- The design script of the routing page of the agent guide locks one script track (`locked=True`, c0108); `test_krt_outcome_is_recorded_either_way` prints the outcome `krt-partial`, so the `routing` job's log shows it; the MODIFIED "Net selection" of c0108 keeps the scenario names of the living spec.
- KiCadRoutingTools on nets that already hold copper is recorded (c0108): `krt-partial` is `different` on 9.0.9 and 10.0.6 in the `routing` jobs of CI run 37803522539 (one of the bench's six open connections stays open, every earlier copper item is kept); `H-K-KRT-PARTIAL` records it and stays `INFERRED`. Nothing depends on it, since `route` takes its verdict from the board.
- `H-K-KRT-GROUP` (c0109) is `KICAD-VERIFIED (9.0.x, 10.0.x)`: the `routing` jobs of CI run 37772583226 passed `test_group` on both majors. S-0216, S-0221 and S-0222 name the tag pages of Freerouting 2.4.1 and the `route.py --help` of KiCadRoutingTools v0.22.1 that c0109 relies on.
- The feasibility gate of c0110 is written: the pair, name, QFN and BGA benches (authored parts in `tests/routing/_gateparts.py`), `tests/routing/test_pair_gate.py` and `test_escape_gate.py` run in the `routing` jobs and print each outcome, each tool run bounded by `FENOLITE_GATE_SECONDS` (900 by default). `krt-pair-names` is recorded `equal` on a local checkout (`H-K-KRT-PAIRNAMES`); `H-K-DRU-PAIRCOUPLE` is `KICAD-VERIFIED (9.0.x, 10.0.x)` and its four `dru-pair-couple-*` probes are pinned for both majors.
- **KiCadRoutingTools routes differential pairs** (c0110): the gate ran in the `routing` jobs of CI run 37803522539 on 9.0.9 and 10.0.6. `krt-pair-t9` and `krt-pair-t10` are `equal` (no unconnected item, no gap or uncoupled finding), so `kicadroutingtools` declares `pairs` and `fenolite route --router kicadroutingtools` gives it the pairs, routed with `route_diff.py` (the gate ran the tool by script; the run through `fenolite route` under KiCad is still to be recorded); `H-K-KRT-PAIR` is `KICAD-VERIFIED (9.0.x, 10.0.x)`. Its escape is not declared: on the BGA bench the dog-bone escape left more connections open than routing without it and put vias in pads (`krt-escape-bga-t<M>` `different`, `H-K-KRT-ESCAPE` refuted by `H-K-KRT-ESCAPE-2`), so `--escape` still gives `route.escape-skipped` with every router. Freerouting's fanout stage stays on by default (better than `fanout=off` on both benches and majors, `H-G-DSN-FANOUT-2`); `H-G-DSN-PAIR` and `H-G-DSN-NARROW` are `ORACLE-VERIFIED(freerouting 2.4.1)`. The outcomes are in `docs/evidence/routing.md` and the results files `krt-v0.22.1.json` and `freerouting-2.4.1.json`.
- The agent guide's `routing` page teaches a thermal via array: its tested design block adds `design.stitch(…, region=d1.pad(2))`, one via inside pad 2 of `D1` (c0111). The two fact rows of `docs/formats/kicad/frame.md` on anchored points and on vias inside an SMD pad are `KICAD-VERIFIED (9.0.x, 10.0.x)`, from the `kicad-9` and `kicad-10` jobs of CI.
- **`fenolite place` and `fenolite check` judge a keep-out that forbids footprints at `KICAD-VERIFIED`** (c0113): `H-K-PLACE-KEEPOUT` holds on 9.0.9 and 10.0.6 in the `kicad-9` and `kicad-10` jobs of CI, so `placement.legality.KEEPOUT_EVIDENCE` no longer lowers the level of a reply on a board with such a keep-out.
- The agent guide teaches net ties, waivers and check severities (c0114): the `footprints` page declares a net-tie footprint with `net_tie()`, the `rules` page calls `design.rules.severity()` and `design.waive()`, and the `checks` page says how to accept one finding. The fact rows of net ties and of stored DRC exclusions are `KICAD-VERIFIED (9.0.x, 10.0.x)`, from the `kicad-9` and `kicad-10` jobs of CI.
- The power benches of c0115 take a target: `neck-plain`, with its fill stored, and `layers` also run on KiCad 9 (`tests/kicad/analysis/test_power_nine.py`), whose 9.0.9 outcomes the `kicad-9` job prints for tasks 1.2 and 11.1. No behaviour of the library changes.
- The 9.0.9 outcomes of the power benches are recorded (c0115): the `kicad-9` job of CI run 37803522539 printed `equal` for the plain neck (nothing at 1.95 mm, 2.0000 mm at 2.05 mm) and for the inner layers, so `analysis-neck-plain` and `insulation-layers` are registered for KiCad 9 too (two more rows of `9.0.9.json`), and `H-K-AN-LAYERS` is `KICAD-VERIFIED (9.0.x, 10.0.x)`.
- **An export that selects a document kind, and `fenolite models`, carry `KICAD-VERIFIED`** (c0116): the four hypotheses of `exports.DOCUMENTS_EVIDENCE` and `H-K-EXPORT-MODELS` hold on 9.0.9 and 10.0.6 in the `kicad-9` and `kicad-10` jobs of CI. The first real fetch of official 3D models (the three of `examples/blink_official` at tags 9.0.9 and 10.0.6, with the maintainer's consent of 2026-10-08) is recorded in `docs/evidence/kicad-libs.md`, and `H-G-MODELS-FETCH` is `CORPUS-VERIFIED`.
- **The drawing kinds of `fenolite export` carry `KICAD-VERIFIED`** (c0117): `H-K-DRAW-ITEMS`, `-PAGE` and `-DRILL` hold on 9.0.9 and 10.0.6 in the `kicad-9` and `kicad-10` jobs of CI, so `exports.drawings.EVIDENCE` is raised and the fact rows of the drawings follow.
- The agent guide teaches the assembly features (c0118): the `placement` page calls `design.fiducial()`, `design.test_point()` and `design.tooling_hole()` in its tested design block, and the `fabrication` page names them beside `fenolite testpoints`. New KiCad tests build the features from the script (`tests/kicad/assembly/test_built_features.py`, with the two outcomes `asm-tooling-drill` and `asm-features-pos`) and run the probes of both majors on KiCad 9 (`test_features_nine.py`).
- **`fenolite testpoints` carries `KICAD-VERIFIED` evidence for its own part** (c0118): the `kicad-9` job of CI run 37803522539 printed the 17 probes of the pad marks, fiducials, keep-out and test points that are stated for both majors, each with its 10.0.6 outcome, so they are registered for KiCad 9 too (17 more rows of `docs/evidence/kicad/probes/9.0.9.json`), the five rows `H-K-PAD-FABPROP`, `-LIB`, `H-K-FIDUCIAL-FORM`, `-KEEPOUT` and `H-K-TESTPOINT-D356` are `KICAD-VERIFIED (9.0.x, 10.0.x)` (the keep-out refill on 10.0.x only) and `exports.testpoints.EVIDENCE` is raised; the reply still takes the lower level of the board read. The features built from a script passed their checks on both majors.
- Development: the release record of 0.4.0 and its guard (`docs/release/v0.4.md`, `tests/unit/test_release_record_v04.py`, change c0154): the verdict per change of v0.4, what is deferred to the next release by the maintainer's decision of 2026-10-08 (everything that depends on his own tests: KiCad GUI saves, a run of a real agent, Altium Designer checks) and the follow-ups found that day.

### Fixed

- The RT-A2 test of the examples (`tests/unit/lens/test_altium_rta2.py`) classifies `examples/yardstick`, which c0119 added and which made three of its tests fail: no Altium build of the yardstick writes anything, so it is listed as refused with the measured reason. Without the official KiCad libraries its symbols do not resolve (exit 3); with them the build is refused in the binary and in the ASCII form (exit 5) by one `altium.text-unwritable`, the description of `Isolator_Analog:AMC1200BDWV` holding `±`. A test holds the entry to that reason where the libraries are installed. No behaviour of the library changes (c0119).
- The DRC report limits of c0141 say what each KiCad major measured. KiCad 9.0.9 writes no `hole_clearance` entry for the construct of the limits bench (a pad beside an unplated hole), so that limit is not measured there and stays the assumed 199; `backends.kicad.drc.MEASURED_TYPES` names the measured types per major (thirteen on 10.0, twelve on 9.0) and follows the probe files. The 9.0.9 report has nine top-level keys, without `ignored_checks`; `drc-limit-keys` compares with the keys of the running major and is `equal` on 9.0.9 (recorded again), and `drc-limit-hole_clearance` stays `different` there. The limits, the marks and every reply of `check` are unchanged (c0141).
- **A board declared with `board(outline=…)` takes a stack-up, rule areas and board drawings** (c0101, c0103;
  found by c0119). `design.stackup()`, `design.rule_area()` and `design.text`, `line`, `rect`, `circle`, `arc`,
  `polygon` and `dimension` refused such a board ("call board() first") because they tested the size that only
  `board(width, height)` sets; they now accept a board of either form, as `zone()` and `cutout()` do. A rounded board
  writes the stack-up, rule areas and drawings, with their uuids, that a rectangle of the same script writes, and a
  rectangle's files are unchanged.
- The yardstick runner (`tools/yardstick.py`, c0119) judges `rebuild.board-unchanged` on the board as the rebuild
  left it. It hashed the board at the end of the run, after `route-pairs`, `route` and `fill-routed` had rewritten it,
  so the first nightly run (37820561099) failed the rule although the rebuild wrote the bytes it found (SHA-256
  `8886fb6a…` before and after). No command changes.
- The yardstick runner judges the errors of `length.rules` on the routed board as it judges KiCad's DRC errors there:
  `length.out-of-range` and `length.skew-out-of-range` are counted once, by the `drc_errors` ratchet, when KiCad's
  `length_out_of_range` and `skew_out_of_range` have the same counts, and fail the stage when they differ. The first
  nightly run failed on the routed USB pair (`USB_DN` 121.7 mm and `USB_DP` 114.2 mm against a 60 mm maximum, 7.5 mm
  of skew against 0.5 mm), which KiCad reported with the same counts (c0119).
- **A `docker:<image>` value of `FENOLITE_KICAD_CLI` or `--kicad-cli` runs that image on Windows.** The marker went
  through a `Path`, which spells the slashes of `kicad/kicad:9.0.9` as backslashes on Windows, so the runner was given
  the image `kicad\kicad:9.0.9`. `cli.docker_image` turns them back (an image reference holds no backslash), and the
  runner, the pull hint and the tests' resolver use it.
- The tests that CI runs on KiCad 9 and on Windows match what those platforms do: the routing benches that `kicad-cli`
  judges are written for the major of the local `kicad-cli` (a 10.0 board is one that KiCad 9 does not read, and the
  `Mini.pretty` footprints are in the 10.0 form, so a target-9 bench takes `Mini_v9.pretty`); the fake `java` of the
  Freerouting tests and the stand-in agent of the time-budget test start on Windows; the files of a built project are
  compared by POSIX names; a test board names a Windows model path as an escaped KiCad string; `docs/hypotheses.md` is
  read as UTF-8. `H-K-OUTLINE-INVALID` and `INVALID_ON_9` of `test_outline_shapes.py` say what 9.0.9 reports: no
  `invalid_outline` for the self-crossing ring of the bench (`outline-invalid-selfx` `absent`, as recorded in
  `9.0.9.json`); the 10.0.6 expectation is unchanged.
- **Parallel `kicad-cli` runs no longer share KiCad's instance lock file** (c0153). Every run of the package runner now gets its own temporary, runtime, cache and state folders (`TMPDIR`, `TMP`, `TEMP`, `XDG_RUNTIME_DIR`, `XDG_CACHE_HOME`, `XDG_STATE_HOME`) beside its own `KICAD_CONFIG_HOME`, removed with the run, so `fenolite` commands run side by side, and the oracle tests on parallel workers, no longer race on `/tmp/org.kicad.kicad/instances/kicad-cli-<major>.0` ("Invalid lock file"). The Docker runner is unchanged (each container has its own `/tmp`). Outputs do not change; a project folder named `.fenolite-state` is now a reserved name, like `config`.
- A schematic symbol that is mirrored and turned by 90 or 270 degrees connects its pins where KiCad does (c0137): KiCad turns the symbol first and mirrors the turned symbol, and Fenolite mirrored first. A build whose `schematic-placements.toml` asks for such a pair (`rotation = 90` with `mirror = "x"`, for example) set the labels of that unit where KiCad does not connect its pins, and the own netlist, the netlist guard and `fenolite netlist` read such an instance of a KiCad sheet with its pins swapped; all of them now follow `schlayout.pin_point`, which rotates first. The order is read from the demo sheets of the corpus (`docs/formats/kicad/schematic.md`, `H-K-SCH-PINFRAME-ORDER`, `CORPUS-VERIFIED`), which a sheet with such an instance now names in its evidence; the probes `sch-pin-frame-*` could not tell the two orders apart (their symbol is symmetric) and keep their outcomes. **A build without such a pair is written byte for byte as before**; the stacked-pin test over the corpus no longer leaves those instances out.

## [0.3.0] - 2026-10-08

### Added

- v0.3, the write part of the second backend: `fenolite build --target altium` writes a complete Altium project (PCB document, schematic documents, both libraries, project file, output job and drawing sheet), a model with a board is written back as Altium documents with the round-trip level RT-A3, `fenolite check` judges copper and parity on Altium input without a tool, `equivalent` compares routing at level 5, and `fenolite kit` builds, checks and records the Altium verification kit. **Every Altium write stays experimental in 0.3.0**: by the rule of change c0092 no write kind has the evidence to leave it, and no kit run is recorded. What is proved, the verdict per write kind and what is not in this release are in `docs/release/v0.3.md`.
- A pin may be bonded to several pads (c0123): `pad_map={"3": ("3", "EP")}` in a script, and the pads that a footprint model lists for one pin in an Altium import. Every pad takes the pin's net on the board; the generated KiCad schematic holds one hidden pin per further pad, so KiCad's netlist, ERC and parity test see them; `netlist.assignment_compare` and level 2 of `equivalent` name every pad. `Component.pin_pad_map` holds such a pin in several pairs, and `Component.pads_of(pin)` reads it. A design whose pins have one pad each is written byte for byte as before. **The model version stays `"0"`, at a cost: Fenolite 0.2.x and earlier read a document that holds a pin of several pads without an error and apply one pad per pin.** New finding `model.pin-pad-map` (error) for a pad that two pins name; a build of a script with such a pad keeps its own error beside it (`altium.pin-pad-map-invalid`, `build.pin-pad-map-invalid`).
- An Altium build bonds a pin to every pad its `pad_map` lists (c0123). The release 0.2.1 fixed the build for a map of one pad per pin; now each pad of a pin carries the pin's net in the PCB document, script copper and `--copper-from` are checked against every pad, and the map record of the pin in the schematic and its library lists all its pads. RT-A2 compares the map. `fenolite check`, the parity test and `equivalent` know the map of a built Altium project from 0.3.0: they report nothing for the mapped pins, where 0.2.1 reports `netlist.assignment-differs`. A map that names a missing pin or pad, or that leaves one pad to two pins, is refused with `altium.pin-pad-map-invalid`, as in 0.2.1. **The files of an Altium build change only for a script whose `pad_map` gives a pin several pads.**
- The Altium import names the components of a sheet that several sheet symbols name per channel: by the project's PCB document, else by the project's designator format (`D9_1` … `D9_12` instead of `D9` twelve times). On the public project with such a sheet, the schematic and the board now share 694 pad assignments instead of 508. The import instantiates repeated sheets: a sheet symbol `Repeat(NAME, first, last)` gives one channel per index, each with its own components, nets and designators (`$ChannelIndex` and `$ChannelAlpha` are resolved; a sheet entry `Repeat(NAME)` takes one member of the parent's bus per channel; a net inside a channel is named per channel); `altium.import.repeated-sheet` is now only the statement that cannot be instantiated. Imported components carry the pin-to-pad map of their footprint model (`pin_pad_map`), which `check` and level 2 of `equivalent` apply; `altium.import.pin-map` (info) counts the map records that one pad per pin cannot say. The `Repeat` part rests on Altium's documentation and authored sheets (no public file holds one), and a board links to such channels by designator only; the annotation file is still not read (c0083).
- The Altium PCB document holds stacks of up to 16 signal layers, blind and buried vias, board texts, graphics, keep-outs and non-plated holes; polygons are written unpoured and repoured in Altium. `result.pcb` of an Altium build counts every model item as written or not lowered, and an item without a record is named by `altium.not-lowered` (`where` = `<kind>/<id>`). Changed: a blind or buried via is written instead of refused; `altium.via-unsupported` is a warning for micro vias only, and the build goes on without them; a board's keep-outs, texts, graphics and holes are written instead of reported per kind; a copper count that is odd or above 32 gives the stack of the two outer layers and `altium.not-lowered` (`stackup`) instead of `altium.copper-stack`. A keep-out holds its restrictions in the key Altium saves and in the key KiCad's importer reads, so a KiCad import carries them. Component bodies are not written yet (reported one by one), and the model's board holes have no slots (c0085).
- `equivalent --level 5` compares routing per net: which pads the copper joins, the vias per layer pair and the routed length per layer. Differences are located at the net (`equiv.route-missing`, `equiv.route-connectivity`, `equiv.route-vias`, `equiv.route-length`); copper that reaches no pad and nets that depend on a zone without a fill are reported and fail nothing (`equiv.route-stub`, `equiv.route-unjudged`, under `result.notices`). `--tolerance-ppm` and a profile's `tolerance_ppm` set a relative tolerance for routed lengths. **Behaviour change:** without `--level`, `equivalent` now runs level 5 when both sides hold a track, an arc or a via, so two routed boards that differ only in their routing exit 5 where they exited 0; pass `--level 4` for the earlier result. The triangle holds at level 5 on `kicad-cli` 10.0.6 for the routed sample and the seven public PCB documents (c0089).
- An Altium build writes an output job set up from the export preset and draws the script's drawing sheet on its schematics; `template build --target altium` writes a `.SchDot` from a sheet specification. The job (`<name>.OutJob`, on by default beside a PCB document, `--altium-outjob off` to leave it out) holds Gerber, NC drill, pick-and-place, bill-of-materials, schematic-print and PCB-print outputs with their source documents and two containers, and no output setting: the options of `--altium-outjob-preset` are listed in `result.outjob.defaults` to be set in Altium. The drawing sheet of `design.sheet(drawing_sheet=…)` is drawn on every Altium schematic as lines and texts on a custom sheet of the paper's size, with the title block as sheet parameters; a logo and a text that mixes a token with other text are losses that need `--allow-lossy`. Both files are proved by Fenolite's own readers only and stay `INFERRED` until Altium has opened them (c0087).
- An Altium build writes the script's rules by kind and scope, names every rule it cannot lower with its reason, and `export --altium-rul` writes them as a rule file. Seven Altium rule kinds carry the neutral ones (Clearance, Width, Routing Via Style, Hole Size, Board Outline Clearance, Hole To Hole Clearance, Minimum Annular Ring), scoped to all objects, a net, a net class or their conjunction; a rule is written exactly or not at all. **Changed:** the single `altium.not-lowered` info with `where` `design-rules` is gone; each rule that is not written gives one `altium.not-lowered` warning with `where` `design-rules/<kind>`, and `result.rules` lists what was written and what was not. A `clearance` or `edge_clearance` minimum of the script now reaches the PCB document and precedes the class rules; a width, via or hole-size minimum is reported, because Altium's record also holds a maximum. The import maps Board Outline Clearance, Hole To Hole Clearance and Minimum Annular Ring (c0084; that Altium applies the rules is not yet confirmed).
- `fenolite kit` builds the Altium verification kit, checks the files a run leaves and records the run: the base of the label `ALTIUM-VERIFIED(kit)`. `kit build` writes five sample projects from the scripts under `examples/kit/`, a checklist (`STEPS.md`), a result form and a script that a user may start inside Altium for the compile steps; the kit is the same byte for byte on every machine. `kit verify` reads the documents that Altium saved with Fenolite's readers, compares them with the kit's own at the levels of `equivalent`, checks the typed values and lists strings that look like a home folder or a login name. `kit record` writes the archive of the results and a run record without any path or user name; `kit status` lists the runs and the rows whose run is stale. No run was made yet, so no row carries the label; the copper check of a re-saved board waits for c0088 and is reported as pending (`docs/altium-kit.md`, c0091).
- A model with a board can be written as Altium documents; RT-A2 compares footprints and copper, and the new level RT-A3 measures an import, write and re-import over the public corpus. `AltiumBackend().write(design)` (and `fenolite.lens.altium.write_model` for a design read from a KiCad board, whose rounded pads need KiCad's corner ratio) writes the PCB document from the model alone and a schematic generated from the circuit; what the writers do not carry is counted per kind and reported as `altium.not-lowered`, and a loss of copper, pads or footprints is refused (`FEN-7001`) without `allow_lossy`. The write is experimental and is not in the capability report. An Altium build now stores the board it wrote in `.fenolite/board.json` (footprints with their pads, tracks, arcs, vias, zones), so `roundtrip.rta2` compares every kind of the written scope and no longer has `summary.not_in_model`; a project built earlier is skipped with `model-predates-board` until it is built again. No project file of a build changes. New: the opt-in check stage `roundtrip.rta3` with the codes `check.rta3-failed` and `check.rta3-unwritten`, and `fenolite roundtrip PATH --level rta0|rta1|rta2|rta3` for Altium input. On the seven public PCB documents that are not heavy the two imports are equal inside the written scope and KiCad's importer reads each rewrite as Fenolite does; a rewrite is not a copy: footprint graphics, bodies, shapes on copper and poured fills are not in it, and `docs/evidence/altium-roundtrip.md` gives the counts (c0090).
- A footprint of the model holds its graphics and free texts, and a rounded pad its corner ratio (c0126): `FootprintInstance.graphics`, `FootprintInstance.texts` (in the pad frame) and `Pad.corner_ratio` (parts per million of the pad's shorter side; `Design.validate()` reports `model.corner-ratio`). `fenolite diff` compares them as the kinds `footprint_graphic` and `footprint_text`. **Changed: the Altium import maps the tracks, arcs, fills, regions and texts of a component to its footprint (the designator and the comment become the fields `Reference` and `Value`), so `altium.import.unmapped` no longer lists `footprint-graphics` on a normal document and an imported `board.json` is larger** (the own samples grow by 41 % to 76 %; measured on the public corpus: owed). **Changed: a rewrite of an Altium board (`AltiumBackend().write`, RT-A3) keeps the lines, arcs, fills, regions, designator and comment of its footprints on the overlays and on Mechanical 1 to 16**; a graphic on copper is counted as `footprint-copper`, a loss that needs `allow_lossy`. `fenolite build --target altium` places the footprints into the model and goes through the same lowering (`lower.from_design` with `lower.LowerOptions`); every project file it writes keeps its bytes, and only `.fenolite/board.json` changes: it holds the footprint graphics and corner ratios that were written (the ten `ALTIUM` pins of the pinned builds moved for that reason alone). RT-A2 and RT-A3 compare the footprint graphics and the corner ratio; a project built before this change is skipped with `model-predates-graphics`. No KiCad output changes: a design read from KiCad holds the fields only after `backends.kicad.fpitems.with_footprint_items`. A model document of 0.2.0 reads as it is; **0.2.0 cannot read a model document that carries the new keys** (`graphics` and `texts` of a footprint, `corner_ratio` of a pad). `lens.altium.pcb_document` and `lens.altium.corner_ratios` are removed.

### Changed

- **The default output of an Altium build changes** (c0086): the Altium schematic draws each symbol's own graphics, follows the module tree at any depth, and carries port directions, buses, parameters and text outside ASCII. `--altium-symbols generic` gives the former output (one rectangle per part), byte for byte; `graphics` is the default by the maintainer's decision of 2026-10-06. New options `--altium-symbols generic|graphics` and `--altium-directions on|off`, new `result.schematic`, new info `altium.bus-flattened`. With `--altium-sheets modules` a nested module now gets its own sheet `<name>_<module path with ".">.SchDoc` instead of being drawn on the sheet of its top-level module; `flat` stays the default. Symbols and footprints from the catalog, and symbols the script authored, now build for `--target altium`. The properties of a part become hidden parameters. In the binary form a comment or a parameter value may hold Windows-1252 characters. The committed samples `blink`, `kicad_example`, `no_connect` and `routed` were regenerated; their earlier bytes, which the author reports covered, are kept under `tests/data/altium/generic/`. Nothing of this has been opened in Altium yet (Part Y of `docs/evidence/altium-schematic.md`); KiCad's importer reads the written library graphics as the model holds them.
- **`fenolite check` on Altium input runs two more stages by default, and can exit 5 where it exited 0** (c0088): `copper.clearance` (shorts, clearance and zone overlaps of the PCB document, with the Clearance rules the document holds) and `parity` (the PCB document against its schematic documents: references, values, footprints and nets), both without any tool. `--stages` selects the former set. The stage says what it could not judge and then carries `UNVERIFIED`: unpoured polygons, internal planes, Clearance rules outside the rule table, and filled zones that no clearance applies to (a pour is never judged against a default the document does not hold). `fenolite parity` takes an Altium project, project folder or PCB document. `fenolite build --target altium` judges the copper of the PCB document it is about to write and refuses a board with a short (exit 5, nothing written); `--copper-check warn` writes it, and the option is no usage error with that target any more. The result of an Altium build gains `copper_check`. The copper check judges no board-edge clearance on either backend. For Altium input only, each clearance rule is judged 5 nm lower, because a distance of an Altium document can read up to 4 nm closer after the unit conversion; KiCad boards are judged exactly as in 0.2.0.
- **`fenolite check` on an Altium PCB document can judge clearance where it judged shorts only, and exit 5 where it exited 0** (c0125): the Altium rule table reads more forms of a Clearance record. A blank object matrix and one whose every entry equals the rule's value are one clearance; the records of a clearance matrix between all net classes (`ISMATRIX` and the cell keys) are read; `ExistsOnLayer` of every copper layer of the board on both scopes gives a clearance rule with `layers`, and `OnMid` on a board without an internal signal layer applies to nothing (new reason `no-layer`, which is no unread rule). A matrix of differing clearances stays unmapped and its reason now counts the differing entries instead of quoting the matrix; the option that ignores the pads of one footprint, a layer condition for some of the copper layers and every other scope function stay unmapped too. The forms are read, never written. **On the public corpus this lifts ONE of the three PCB documents that had no clearance in force**, to the level `INFERRED`: the one whose records are a clearance matrix on a two-layer board, the only forms a neutral rule says exactly. The two others stay `UNVERIFIED` (`docs/evidence/altium-roundtrip.md`, "Light DRC over the corpus"). `map_rules`, `rulemap.lift` and `import_rules` take the board's copper layers (`layers=`); KiCad boards and every written file are unchanged.
- **The Altium import reads a Clearance matrix cell by cell, and the stage summary of a document check has one more key** (c0130): a Clearance record whose object matrix holds differing clearances gives its generic rule and one more clearance rule per cell (`<rule>/<kind>-<kind>`, with `item_kind` selectors for `track`, `pad`, `via` and `zone`), when the matrix is exact in those kinds; a matrix that tells an arc from a track or a through-hole pad from a surface pad stays unmapped and its reason names the pairs. Cells for fills, regions, text and holes are kept in the rule's bag. `summary.clearance_cells` (`judged`, `unjudged`) counts them, from the new `DesignRules.clearance_cells`. **On the public corpus this lifts one record, on the heavy document, which stays `UNVERIFIED`; the two other documents with such a matrix are not moved** (their matrices are not exact, and they carry the option that ignores the pads of one footprint). The measurement of that heavy document also found 28 false shorts of the import (vias without a pad on inner layers), listed on `docs/evidence/altium-roundtrip.md`. Read only; KiCad boards and every written file are unchanged.
- **The canonical model of an imported Altium project changes when a footprint model lists several pads for a pin** (c0123): the pads are pairs of `pin_pad_map`, no longer `pin_pads` entries of the extension bag, and `altium.import.pin-map` counts only a record without a pad and a pad that another pin holds. On the public project with such records the assignment comparison covers four more elements.
- **The output job that `fenolite build --target altium` writes now holds the Gerber settings, and every written `.OutJob` differs from the one an earlier build wrote** (c0138). No release wrote an output job (0.2.x writes none; the job is unreleased v0.3 work), so this concerns folders built from the development branch. **A rebuild into such a folder replaces the job and keeps the old one as `<name>.OutJob.bak`**, as it does for every other file the build wrote; it is refused instead (exit 7, `FEN-7001`, nothing written) only when the job was edited since that build or when the folder's `.fenolite/` record is gone, and then `--discard-layout` replaces it, again with the backup. **A rebuild of a folder built by 0.2.x adds the output job to the project file, keeping `<name>.PrjPcb.bak`**: a project file that is still as a build wrote it and does not list the job is written again with the job listed, so that Altium's Projects panel shows it; a project file that was changed since (Altium saved it, or you edited it), or that the folder's `.fenolite/` record does not know, is kept as before, whatever `--discard-layout`, with the info `altium.outjob-not-listed` and how to list the job. Why: run in Altium Designer 26, the job as written before produced drill, pick-and-place, bill-of-materials and print files and no Gerber layer file, because a Gerber output without a settings record plots nothing. The Gerber output now carries the complete record of 44 fields that the public saved jobs hold: millimetres, the decimals of the export preset's `gerbers.precision` (4 without a preset), and as plotted layers the layers of the board (silkscreen, paste, solder mask, the copper layers from top to bottom with a plane at its place, Mechanical 13 to 16). Every output, of every kind, gains the key `OutputDefault<i>=0`; no other output kind gains a settings record. **No board outline is plotted yet: the Gerber set of the written job holds no outline file**, because the PCB document holds the outline as the board shape and on no layer; `result.outjob.gerber.outline` says so, and you turn the outline on in the Gerber setup in Altium. `result.outjob` gains `gerber` (`unit`, `decimals`, `layers`, `outline`) and `result.outjob.defaults` no longer lists `gerbers.precision`. `outjob.from_preset` takes the board's copper stack (`copper=`), `write_outjob` refuses a Gerber output without the whole record, and `read_outjob` gives the settings of an output (`JobOutput.settings`, `record_fields`). Altium has not opened such a job yet: every row is `INFERRED` until Part O of the second Altium session is reported; the committed sample `tests/data/altium/outjob/blink.OutJob` changes (eight more lines).
- **The notes about a kept Altium project file name only what the file lacks** (c0138). A project file that exists in `--out` and is kept is now read with Fenolite's own project reader: `altium.pcb-not-in-project`, `altium.schlib-not-in-project`, `altium.sheets-not-in-project` and `altium.outjob-not-listed` are given only for documents the kept file really does not list, and each names those documents alone. Before, the first three were given on every rebuild into a folder with a project file, even one that listed everything. A kept file that cannot be read gets them as before, with a hint that says so.
- **`.fenolite/build.json` of an Altium build keeps a kept project file that is still as a build wrote it** (c0138). A rebuild that keeps `<name>.PrjPcb` (nothing has to change in it, or the output job is off) records the file again when its bytes are the ones the folder's record held, so that a later build still knows it as built and can add the output job to it. Before, a kept project file dropped out of the record at the first rebuild. A project file that is kept because it was changed, or that had no record, is not recorded. The record's file list is no list of what a run wrote: `result.files` and the receipt are, and they do not name a kept file.
- **An Altium board with internal planes is imported with fewer tracks.** A plane layer is stored in negative, so a line, an arc, a fill, a region or a text drawn on it cuts the plane and is no copper; the import made a track without a net of each such line. It now makes no entity of them, with or without a net: `altium.import.unmapped` counts them as `plane-cuts`, and the layer of the plane holds the count in its `altium` bag (`plane_cuts`). The ids of the other imported items do not change. The copper check on Altium input no longer filters those lines out of its view and reports the planes as before (`copper.item-unsupported` at `plane`); `equivalent --level 5` no longer counts them as copper on no net, and a rewrite of such a board (RT-A3) no longer writes them as tracks. On the two public documents with planes the import holds 74 and 43 tracks fewer, the number KiCad's own import of them holds (c0124).
- The Altium import keeps the holes of a poured region: copper inside a hole of a pour is no longer joined to it. A zone fill of an imported document is one ring that holds the outline and its holes, the form of a KiCad filled polygon (new `geometry.keyhole_ring`), so the copper check no longer reports tracks and vias in a hole as shorts and `equivalent --level 5` finds the islands of a pour. A hole outside its outline is dropped and reported by the new warning `altium.import.zone-hole-outside`. Imported boards whose pours have holes get other fill polygons than before; boards without holes are unchanged (c0122).
- **The counts of `fenolite roundtrip --level rta3` and of the stage `roundtrip.rta3` change on a document that holds vias whose drill equals their diameter** (c0128): such vias are now written by the trip and leave `unwritten.via`; no verdict changes. `AltiumBackend().write(design, rewrite=True)` (also `lower.write_design` and `lower.from_design`) is the caller's statement that the design is the reading of an Altium document and that the write gives it back; a via whose drill equals its diameter, which a saved document can hold, is then written as it was read. Without the argument nothing changes: `fenolite build --target altium`, `write_model` and a plain `write` refuse or leave out such a via as before, the committed samples keep their bytes, and `rewrite=True` is refused for a board that was not read from an Altium document. On the public document with 48 such vias the rewrite holds all 242 vias, and KiCad's importer reads it as Fenolite does.
- **The content of an imported Altium board with arcs changes** (c0127): an arc that is read from an arc record keeps the record's own centre, radius and angles in its `altium` bag (the pair `arc`, on an `Arc` and on a graphic of kind `arc`), and the write of a model (`AltiumBackend().write`, RT-A3) gives that record back while it still says the arc's three points within 2 nm. No id changes; a design read from KiCad never holds the pair; a build from a script writes the same bytes. An arc that was moved in the model is written from its points, as before, and an arc with a kept record is no longer refused when its three points lie on one line. On the heavy public document 7 of 517 arcs came back more than 2 nm away and 12 were not written; all 529 are now written and equal, RT-A3 holds on the eight public PCB documents, and `H-A-VER-RTA3` is `CORPUS-VERIFIED`. That level means that Fenolite reads its own rewrite of a public Altium PCB document back to an equal model inside the written scope, and that KiCad's importer reads the rewrite as Fenolite does at levels 1 to 5; it says nothing about Altium opening a written file (that stays `INFERRED` until the kit run of c0091 and c0092), and the scope leaves out footprint graphics (until c0126), component bodies (until c0121) and the items counted as not written in `docs/evidence/altium-roundtrip.md`. The stage `roundtrip.rta3` still reports `INFERRED`, no round-trip cell of the matrix is set, and the write stays experimental.
- The slack of the copper check on Altium input is a stated rule (c0131): one file unit (1/10 000 mil, 2.54 nm) per item of the pair, 5.08 nm for a pair, held as 5 whole nanometres and never rounded up. **No finding changes: the rule gives the 5 nm the check already used**, for Altium input only; KiCad boards are judged strictly at the nanometre, as in 0.2.0. The derivation (how far the conversion to nanometres moves a track, a via, a pad, a pour and an arc) is in `docs/formats/altium/import.md`. On the eight public PCB documents the slack removes 6 075 findings, all 1 to 4 nm short; 25 findings that are 8 to 20 nm short stay errors, and nothing is allow-listed. The rule is slightly tighter than the worst case of the conversion for a pad against a rectangular pad (5.55 to 6.36 nm against 5.08 nm) and is not widened, for lack of a public pair that shows it.
- **The JSON result of every `fenolite build --target altium` gains the key `pcb`** (c0121, repairing c0085 to its own spec): `result.pcb` holds `written`, `not_lowered` and the new `bodies`, after `copper`, and is `null` without a PCB document. The contract described the key since c0085, but only the library's build summary held it and the command never returned it. No written file changes. An Altium build writes the extruded component bodies of a board on request (`--altium-bodies extruded`, off by default); bodies that name a 3D model are reported. With the option, each extruded body of a footprint that has an outline and a height above its standoff becomes one record in both body storages of the PCB document, owned by its component, and the bodies of a footprint definition go into the PCB library; the write of a model takes the same choice (`bodies="extruded"` on `AltiumBackend.write`, `lens.altium.write_model` and `AltiumBackend.model_roundtrip`), and RT-A2 and RT-A3 then compare the bodies that were written. Without the option every file of a build is the file of before, byte for byte, and no body is ever made for a footprint that has none. **Experimental, and the evidence is thin**: the keys of the record were measured on 1272 saved bodies of five public documents of three repositories, 1265 of them from one repository; two keys (`MODELID`, `MODEL.CHECKSUM`) have no known rule and hold stand-ins; and no written body has been opened in Altium, so the option stays off until step X8 of the author report is in. New sample `tests/data/altium/body2/`.
- **Catalog symbols show a pin name only where it can be read, so some symbols look different** (c0134). The transistors, thyristors and photodetectors, `Schottky_Diode`, `Potentiometer`, `Transformer`, `Switch_SPDT`, `Pushbutton_NO`, `Relay_SPDT`, `Dual_LED_Common_Cathode`, `Optocoupler`, `Bridge_Rectifier`, `Operational_Amplifier` and `Comparator` no longer draw their pin names, which lay on each other and on the drawing in KiCad and in Altium; the amplifiers mark their two inputs with a plus and a minus stroke, the bridge its four terminals, the optocoupler its emitter. `Linear_Regulator`, `Offline_Power_Controller`, `Microcontroller` and `Power_Module` keep their names in a larger box, `Schottky_Diode` has the longer pins of `Diode`, and `Capacitor_Polarized` and `Capacitor_Electrolytic` carry their plus mark below the lead, clear of the pin number. In the example library `FenoliteDemo.kicad_sym`, `CONN2` no longer shows its pin numbers a second time as names, `MCU8` and `DUAL_OPAMP` are larger, `MCU8` has longer pins further apart with its names clear of its clock wedge and its numbers clear of its inversion bubbles, and `R_V` has longer pins. A design that uses one of these symbols gets a different schematic on its next build, once: the symbol's look, and for the enlarged ones the places of its pins. Pin numbers, pin names, nets, designators and the board do not change. A test now measures the rule on every symbol Fenolite authors, with the marks KiCad draws for inverted and clock pins, at KiCad's text size and at an estimate of Altium's that nobody has measured in Altium yet.
- **The two LED lands of the catalog are documented as cathode-first** (c0144): `LED0603_Kingbright_APT1608SURCK` and `LED0805_Kingbright_APT2012SURCK` number their pads as the manufacturer does, pad 1 the cathode, while the symbol `Fenolite:LED` has pin 1 anode. `docs/catalog/sources.md` and `docs/catalog/coverage.md` now say, as they do for `SOD128_Nexperia_CFP5`, that the pair needs `pad_map={"1": "2", "2": "1"}`; without it the anode's net lies on the cathode's pad. Check a design of 0.2.x that uses one of these lands: nothing in a build changes, the footprints and their summaries are the same. The four kit samples that used the pair now carry the map and connect the LED by pin name, so their schematics draw it the right way round and their boards keep every pad's net.
- **The catalog applies a default pin-to-pad map to a diode or LED on a cathode-first land** (c0147). A part of `Fenolite:LED`, `Diode`, `Zener_Diode`, `Schottky_Diode` or `Photodiode` (pin 1 anode, pin 2 cathode) on `LED0603_Kingbright_APT1608SURCK`, `LED0805_Kingbright_APT2012SURCK` or `SOD128_Nexperia_CFP5` (pad 1 the cathode) that gives no `pad_map` now gets `{"1": "2", "2": "1"}` in the KiCad and the Altium build alike: the anode pin on the anode pad, the cathode pin on the cathode pad. An explicit `pad_map` always wins, and a design that authors the symbol or the land itself gets no default. **A design that uses one of these lands without a `pad_map` and wired the LED or diode by pin number gets its two pad nets swapped on the next build, and the new warning `build.pad-map-default` names the part, the land and the map.** Connect the part by pin name (`A`, `K`) and write `pad_map={"1": "2", "2": "1"}` to silence the warning, or write `pad_map={"1": "1", "2": "2"}` to keep the pad order of earlier builds. A design that gives a map, and every part on another land, builds the same files as before; the kit samples carry their map since c0144.
- The help of `build --altium-symbols` says “the output of 0.2.0 and earlier” where it said “the output before v0.4” (c0136).
- Development: the release record of 0.3.0 and its guard (`docs/release/v0.3.md`, change c0150). The milestone names of c0136: the write side of the second backend, which these pages called v0.4 before 2026-10-07, is the second part of v0.3, and v0.4 names the proposals still on other branches (the agent track, board authoring, the complex board); the record of 0.2.0 and the archived changes keep the names of their day. The proposals c0083–c0092, c0121, c0126 and c0138 were written before their code. The maintainer's Altium Designer 26 reports of 2026-10-07 and 2026-10-08 are recorded on the evidence pages as author reports, which never move a write out of `experimental`: the written projects open and compile; the output job with the Gerber settings record produces every output, Gerber layer files among them; the sheets of a repeated-sheet sample are no longer black, and the bus of a `Repeat` entry does not split into the channels (an open defect); on one public board Altium's own rule check passes seven clearance pairs that Fenolite reports 8 to 9 nm short, so Fenolite's check is the stricter one there. No kit run was recorded; the maintainer's decision on the kit and the revalidation it owes are in `docs/evidence/altium-kit/README.md`. Archived the completed specs of c0089 (level 5 of `equivalent`) and c0122 (zone holes of the Altium import), with the full suite and the CI run cited in their closing tasks.

### Fixed

- **A design that names parts of the built-in catalog and declares a `Power(...)` interface builds for KiCad** (c0143; the same fix is released for the 0.2 series as 0.2.2). Since the release 0.2.0 such a design failed to build with `build.vendor-unsafe-name` ("symbol libraries 'Fenolite' and 'fenolite' differ only in letter case"), so a catalog regulator, comparator or amplifier fed from a connector could not pass KiCad's ERC. The power flag of such a design now lies in the catalog's library (`Fenolite:PWR_FLAG` in `lib/Fenolite.kicad_sym`), and ERC takes the supply as driven. A design without catalog parts keeps `lib/fenolite.kicad_sym`, and no file of a design that built before changes. A design that needs a flag and has a symbol `PWR_FLAG` of its own in such a library is refused with `build.reserved-library`.
- **Altium schematic files written by 0.3.0 now show and hide pin names and numbers as intended in Altium** (c0148). Fenolite wrote a pin's `PINCONGLOMERATE` with bits 0x08 and 0x10 as "name shown" and "number shown" and without bit 0x20, which every pin Altium saves holds; Altium Designer 26 reads the two bits as hide flags when 0x20 is clear, so it showed the names that a symbol meant hidden and hid the numbers (on the catalog LED the two names crossed over and the part looked reversed; its pads and pin map were right). **Changed: every pin of every Altium schematic document and library that a build writes now holds bit 0x20**, with 0x08 and 0x10 as show flags, the form that Altium Designer 26.5 showed as meant (author report of 2026-10-08 on the new check project `tests/data/altium/pinbits/`; 4 175 of 4 175 pins of the public corpus hold 0x20). Files written by 0.2.x show names that were meant hidden: rebuild them. The schematic reader reads the two bits as show flags with 0x20 and as hide flags without it (`Pin.name_shown`, `Pin.designator_shown`); the import's model does not change. Every committed Altium schematic sample and the ten `ALTIUM` pins of the pinned builds moved for this reason alone (measured record by record, `tests/_pin_bits.py`); no KiCad output changes.
- **`fenolite check` on an Altium PCB document no longer reports a short where a via has no pad** (c0132): Altium's "Remove Unused Pad Shapes" takes the pad of a via off the layers on which nothing touches it, the via record names those layers (a table of thirty-two bytes at offset 209, read by `read.pcbprims.via_pad_removed`), and the import keeps them in the via's `altium` bag as the pair `pad_removed`. The copper check on Altium input judges such a via with its diameter where it has a pad and with its drill as diameter where it has none: a pour around the hole is no finding, and copper inside the hole still is a short. On the one public document that holds such vias (123 of 1 770) the 28 false shorts and one false clearance finding are gone and no other finding changes. `summary.items.via` of the stage counts the parts in which such a via is judged, and a rewrite (`AltiumBackend().write`, RT-A3) writes the via with a pad on every layer and counts it under the new kind `via-pad-shape`. The model, the ids of imported items, every KiCad output and the judging of KiCad boards are unchanged; the meaning of the bytes is `INFERRED` (`H-A-IMP-VIA-PADLESS`), and nine further bytes of the long via record stay unexplained and unread.
- The font table of an Altium schematic holds each distinct font once (c0146). A drawing sheet declared the fonts of its texts without looking at the sheet's own font, so a sheet with a text of 10 points held Times New Roman 10 twice; a copy that Altium Designer 26 saved held it once (one file, observed on 2026-10-07). Such a text now names font 1. The sample of the `Repeat` statement that the import's tests read (`tests/data/altium/channels/two/`) is written by the schematic writer itself, after its first files, which held no colour at all, showed as a black page in Altium; the import reads the same circuit from it. KiCad output is not touched. **Changed: the schematic documents of `fenolite build --target altium` with a drawing sheet, and the `.SchDot` of `fenolite template build --target altium`, differ from those an earlier build wrote when the sheet holds a text of 10 points (both shipped sheet examples do): `FONTIDCOUNT` is one lower and the labels of the frame are renumbered. A build without a drawing sheet is byte-identical.**
- **`fenolite build --target altium --copper-from` accepts a KiCad board whose bottom-side footprint has pads off its X axis** (c0142). The check compared the pads as the board stores them, mirrored about the footprint's X axis on the bottom (`H-G-BOTTOM-STORE`), with the library footprint, so such a board was refused with `altium.copper-board-mismatch` ("the pads of … differ"), with or without a `pad_map`, and so was script copper on such a part; a board whose bottom footprint was stored unmirrored was accepted. The mirror is now undone before the comparison, at any rotation. No written file changes.

## [0.2.2] - 2026-10-08

### Fixed

- A design that names parts of the built-in catalog and declares a `Power(...)` interface builds for KiCad (c0143). In the releases 0.2.0 and 0.2.1 such a design failed to build with `build.vendor-unsafe-name` ("symbol libraries 'Fenolite' and 'fenolite' differ only in letter case"), so a catalog regulator, comparator or amplifier fed from a connector could not pass KiCad's ERC. The power flag of such a design now lies in the catalog's library (`Fenolite:PWR_FLAG` in `lib/Fenolite.kicad_sym`), and ERC takes the supply as driven. A design without catalog parts keeps `lib/fenolite.kicad_sym`, and no file of a design that built before changes. A design that needs a flag and has a symbol `PWR_FLAG` of its own in such a library is refused with `build.reserved-library`.

### Changed

- Development: the second patch release of the series. It is cut from the tag `v0.2.1`, not from `dev`, and holds this one fix, carried back from `dev`; `docs/release/v0.2.md` records it under “Patch releases” (c0149). Archived the completed specs of c0143 and c0149.

## [0.2.1] - 2026-10-07

### Fixed

- `build --target altium` applies `pad_map` (c0135). In the releases 0.1.0 and 0.2.0 an Altium build ignored a `pad_map` that renames pads: the PCB document carried each net on the pad of the pin's own number (for `pad_map={"1": "2", "2": "1"}`, the two nets exchanged), and the schematic said nothing of the map; the KiCad build of the same script was right. Now each net is on the mapped pad of the PCB document, the schematic and its library hold the map in the footprint model (one record for each pin whose pad is not the pad of its own number), and script copper and `--copper-from` are checked against the mapped pads. A `pad_map` that names a pin the symbol lacks or a pad the footprint lacks, or that leaves one pad to two pins (`pad_map={"1": "2"}` on a part that has a pin 2), is refused with the new error `altium.pin-pad-map-invalid` (exit 5, nothing written), as the KiCad build refuses it; 0.2.0 built such a script. A script without a `pad_map` builds the same files, byte for byte.
  - **If you built a script with a `pad_map` for Altium with 0.1.0 or 0.2.0, build it again.** The PCB document, the schematic and its library change; the files they replace are kept beside them as `.bak`. A PCB document that was edited since it was built is not replaced: the build stops with exit 7, and `--discard-layout` replaces it (the edited file is kept as `.bak`), or build into another folder. A board that was laid out from the old PCB document has the nets of the mapped pads on the wrong pads: check it against the rebuilt one.
  - `fenolite check` on such a project still reports `netlist.assignment-differs` and exits 5: this release compares the schematic by pin number and the board by pad number. The written files are right; the comparison learns the map in 0.3.0.

### Changed

- Development: the first patch release of the series. It is cut from the tag `v0.2.0`, not from `dev`, and holds this one fix; `docs/release/v0.2.md` records it under “Patch releases” (c0133). Archived the completed specs of c0133 and c0135.

## [0.2.0] - 2026-10-06
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

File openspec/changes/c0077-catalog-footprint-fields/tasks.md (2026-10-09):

## 0. Entry check

- [x] 0.1 Check the prerequisites and reproduce the defect on the tip of `dev`. Write under this task, with the date and the commit:
  - that `0.3.0` is released and that c0126 and c0123 are archived (stop here otherwise);
  - the issue codes of `fenolite check` on the three-part design of `design.md` ("Reproduction"), built into a temporary folder, and whether a footprint authored with `fenolite.dsl.Footprint` shows the same defect;
  - the function of `src/fenolite/lens/preserve.py`, as it is after c0069, that takes the rule of Decision 4, and the place in `src/fenolite/lens/build.py` where `build.field-added` is reported;
  - every pinned digest that moves: run `grep -rln "Fenolite:" tests examples` and list each test, each entry of `tests/data/MANIFEST.toml` and each kit sample (`examples/kit`, `tests/unit/verify/kit/test_manifest.py`) that pins bytes of a KiCad file built from catalog or authored footprints. The kit pins Altium documents, which Decision 7 keeps; say so with the test that shows it.
  Proof: `openspec validate c0077-catalog-footprint-fields --strict --no-interactive` passes, and the notes hold the `netlist.*` codes of the run and the list of digests.
  - Open: the prerequisites are not met on the base of this work, so the task is not ticked. The rest of it is done and written below; the implementation went on by decision of the coordinator of the v0.4 night, on the integration branch of the milestone.
  - 2026-10-07, base `f36e08d9` (the integration branch of v0.4: `dev` plus the proposals of the milestone). **Prerequisites: not met.** The newest tag is `v0.2.1` and `pyproject.toml` says `0.2.1`: `0.3.0` is not released. c0126 is an open folder with no task ticked, and c0123 is not a folder on this base (`docs/roadmap.md` says it lives on its own branch). Nothing this change does reads what they add: it adds entries to `FootprintInstance.fields` and slots to prepared definitions, and touches no pin-to-pad mapping.
  - Reproduction on `f36e08d9` with `kicad-cli` 10.0.6: the three parts of `design.md` plus `R2` on `Local:TwoPad` (authored with `fenolite.dsl.Footprint`), three nets, no track. `build --confirm` exits 0; the board holds four properties, each `fenolite.path`; `lib/Fenolite.pretty/Chip_0603.kicad_mod` and `lib/Local.pretty/TwoPad.kicad_mod` hold none. `check` exits 5 with `netlist.assignment-differs` for `-1` and `-2`, `netlist.uncovered` twice (`-1, -2` not in the model; `D1-1, D1-2, J1-1, J1-2, R1-1, …` not in the board), and `kicad.drc.duplicate-footprints` ×3, `kicad.drc.extra-footprint` ×4, `kicad.drc.missing-footprint` ×4, `kicad.drc.unconnected-items` ×5. The authored footprint shows the same defect. After the change the same folder gives 12 properties and only the five `kicad.drc.unconnected-items` of a board without tracks.
  - Decision 4 is taken by a new function `lens.preserve._apply_mandatory_fields(kept, built)`, called in `merge_layout` right after `_apply_user_properties` for a kept footprint. `build.field-added` is reported in `lens.build.build_design`, at the top of the loop over the parts, once per lib id whose definition's `properties` lack `Reference` or `Value`.
  - Pinned digests that move: **none**. `grep -rln "Fenolite:" tests examples` gives 16 files (four kit samples, one parity fixture, `tests/data/lens/acceptance/design.py`, ten test files). None pins bytes of a KiCad file built from catalog or authored footprints: the unit suite of the touched areas (5000 tests) failed in one test only, a behaviour test (below). `tests/data/MANIFEST.toml` has no entry for such a file. The kit pins Altium documents and its own inputs (`tests/unit/verify/kit/test_manifest.py`, 0 failures); `tests/unit/cli/test_catalog_only.py::test_altium_documents_are_unchanged` shows that the Altium plan keeps every SHA-256.
  - One behaviour test moves: `tests/unit/cli/test_build_fields_command.py::test_library_without_the_field` expected `FEN-3004` for `Part.field("Value", …)` on a library footprint without `Value`. Such a footprint now gets the field, so the request builds; the test now expects exit 0, one `build.field-added` and the hidden field.
  - A defect found on the way, on the base: `build --target altium` of a design that names catalog ids and declares script copper stopped with `FEN-3001` (`no symbol library table row has the nickname 'Fenolite'`), because the KiCad build that resolves the copper got the script's footprints only. The scenario "Altium documents are unchanged" needs that build, so `cli/cmd_build.py` now passes the catalog's footprint and symbol definitions to it, and the delta of `fenolite-component-catalog` says so.
  - Deltas re-read: the four requirement names are in no living spec and in no other open change (`grep` over `openspec/`); all four deltas are ADDED. `openspec validate c0077-catalog-footprint-fields --strict --no-interactive`: valid, exit 0.
  - 2026-10-08, base `04ef42a` (`v04`, rebased onto 0.3.0 in `9fb3513`): **`0.3.0` is released**: `fenolite --version` prints `0.3.0`, `CHANGELOG.md` holds `## [0.3.0] - 2026-10-08`, and the release record is the archived change `2026-10-08-c0150-release-0-3-0` (branch `release-0.3.0` at `6eddd23`). c0123 and c0126 shipped in 0.3.0 and are still open folders, not archived, on `v04` as on `release-0.3.0`; nothing of this change reads what they add (see above). Release 0.4 is prepared from `v04` by the maintainer's decision of 2026-10-08, so the task is closed on this base. Pinned digests: still none moves; the CI run 37772583226 of `04ef42a` passes every job (`unit` on 3.11 to 3.13 and three systems, `kicad-9`, `kicad-10`, `routing`, `wheel`). `openspec validate c0077-catalog-footprint-fields --strict --no-interactive`: no error (the four long-requirement warnings only).

## 1. Register

- [x] 1.1 Add the row `H-K-FP-FIELDS` to `docs/hypotheses.md` (backend `kicad`, level `INFERRED`, the test and criterion of `design.md`, result `pending`). Proof: `uv run pytest tests/unit/test_hypotheses_register.py tests/unit/verify/test_cited_ids.py -q`; `grep -c '^| H-K-FP-FIELDS ' docs/hypotheses.md` prints `1`.
  - Open: the row is added as the last row of the table and `grep -c` prints `1`, but the proof exits 1 (2026-10-07: 1 failed, 41 passed). The one failure is `test_cited_ids_registered`: `openspec/changes/c0140-part-height-rules/design.md` cites an id of c0099 that no row registers yet, which no row registers. It fails the same way on a clean copy of `f36e08d9` and belongs to c0140; nothing of this change is in its message.
  - 2026-10-08, base `04ef42a`: ticked. The proof passes (`uv run pytest tests/unit/test_hypotheses_register.py tests/unit/verify/test_cited_ids.py tests/unit/test_provenance.py -q`: 50 passed, exit 0; c0140's cited id is registered on this base), and `grep -c '^| H-K-FP-FIELDS ' docs/hypotheses.md` prints `1`.

## 2. The two fields

- [x] 2.1 Add `FieldDefault`, `default_fields`, `FIELD_GAP`, `FIELD_SIZE` and `FIELD_THICKNESS` to `src/fenolite/backends/kicad/embed.py`, and make `mod.prepare_authored_definition` add the two properties. Write `tests/unit/backends/kicad/test_embed_fields.py` (scenarios "Catalog footprint placed on top", "Bottom side", "Deterministic uuids", "Authored two-pad footprint", "Every catalog footprint"). Regenerate, in this commit, each pinned digest that task 0.1 listed. Proof: `uv run pytest tests/unit/backends/kicad/test_embed_fields.py tests/unit/catalog tests/unit/test_import_graph.py -q`; `uv run pyright src`.
  - 2026-10-07: 577 passed, exit 0; `pyright src`: 0 errors, exit 0. No digest to regenerate (task 0.1). Beside the names of `design.md`, `embed` gained `MANDATORY_FIELDS`, `LIBRARY_REFERENCE`, `field_property` and `library_field_uuid`, which `mod` and `lens` share.
- [x] 2.2 Make `embed.place_footprint` add a field that a library footprint lacks, and make `lens/build.py` report `build.field-added`; document the code in `docs/cli-contract.md` and add its table to `src/fenolite/cli/data/explain.toml` (scenarios "Library footprint keeps its own fields", "Library footprint without a reference"). Proof: `uv run pytest tests/unit/backends/kicad/test_embed_fields.py -k library tests/unit/cli/test_explain_cmd.py tests/consistency -q`.
  - 2026-10-07: 4 passed, 289 deselected, exit 0 (`-k library` holds for every path of the command). The same paths without `-k`, with `tests/unit/lens/test_build_issues.py` and `tests/unit/cli/test_build_fields_command.py`: 297 passed, 15 skipped, exit 0. The field is added after `_uuids` and before the bottom-side pass, so the uuids of the properties the library gave do not move.
- [x] 2.3 Make a kept footprint gain a missing `Reference` or `Value` field in `src/fenolite/lens/preserve.py` (scenarios of "Kept footprints gain missing mandatory fields"), and describe the rule in `docs/lens.md`. Proof: `uv run pytest tests/unit/cli/test_catalog_only.py -k "older_board or edited or second" tests/unit/lens -q`.
  - 2026-10-07: 24 passed, exit 0; `tests/unit/lens` without `-k`: 847 passed, 1 skipped, exit 0. The repaired board has the bytes of the board a first build writes.
- [x] 2.4 Prove `Part.field` on generated fields (scenario "Field request on a catalog part"). Proof: `uv run pytest tests/unit/backends/kicad/test_embed_fields.py -k field_request -q`.
  - 2026-10-07: 1 passed, 16 deselected, exit 0.

## 3. Acceptance

- [x] 3.1 Write `tests/_catalog_design.py::catalog_blink()` and `tests/unit/cli/test_catalog_only.py` (scenarios "Nets of the script and of the board agree", "A regression is caught" and "Altium documents are unchanged"). Proof: `uv run pytest tests/unit/cli/test_catalog_only.py tests/unit/cli/test_catalog.py -q`.
  - 2026-10-07: 14 passed, exit 0.
- [x] 3.2 Write `tests/kicad/build/test_catalog_only.py` (scenario "KiCad accepts the project"). Proof: `uv run pytest tests/kicad/build/test_catalog_only.py -rA` on the local KiCad 10.0.6 and on KiCad 9.0.9.
  - Open: the test is written and passes on the local `kicad-cli` 10.0.6 (2026-10-07, `FENOLITE_REQUIRE=kicad`: 4 passed, exit 0; targets 9 and 10: `check` exits 0 with no issue, the control without the fields exits 5 with `netlist.assignment-differs`). The run on 9.0.9 is left to the `kicad-9` job of CI: no 9.0.9 was run this night.
  - 2026-10-08: ticked by the local run of 2026-10-08 in the pinned 9.0.9 image (`kicad/kicad:9.0.9@sha256:e638b79b…`, linux/amd64, branch `v04-k9-probes`; whole `tests/kicad` without the corpus: 777 passed, 4 failed, 784 skipped, 1 xfailed; `tests/kicad/test_probe_results.py` passed on the 536 probes of major 9): `tests/kicad/build/test_catalog_only.py` 2 passed (target 9: `check` exits 0, the control is refused), 2 skipped (target 10 on `kicad-cli` 9).

## 4. Documentation

- [x] 4.1 Describe the generated fields in `docs/dsl.md` ("Authored footprints" and "Field placement") and in `docs/catalog/README.md`: what is generated, where it is placed, and that `Part.field` moves or hides it. Say in `docs/altium.md`, in one sentence, that the Altium build is unchanged by the generated fields. Proof: `uv run pytest tests/consistency tests/unit/test_repo_layout.py tests/residue -q`.
  - 2026-10-07: 304 passed, 15 skipped, exit 0. `docs/formats/kicad/board.md` ("Placed footprints") holds the rule of the backend too.

## 5. Closing

- [x] 5.1 Update the evidence labels: `H-K-FP-FIELDS` becomes `KICAD-VERIFIED (9.0.x, 10.0.x)` with the two runs, or records what KiCad reported. Proof: `uv run pytest tests/unit/test_provenance.py tests/unit/test_hypotheses_register.py -q`.
  - Open: the row says `KICAD-VERIFIED (10.0.x)` with the run on 10.0.6 and names the missing 9.0.9 run. The proof exits 1 for the reason of task 1.1 (2026-10-07: 1 failed, 43 passed; the failure is c0140's an id of c0099 that no row registers yet).
  - 2026-10-08: ticked: `H-K-FP-FIELDS` is `KICAD-VERIFIED (9.0.x, 10.0.x)` with both runs; `uv run pytest tests/unit/test_provenance.py tests/unit/test_hypotheses_register.py -q` passes. CI has still to confirm the 9.0.9 half.
  - 2026-10-08: CI confirmed it: run 37772583226 on `04ef42a`, job `kicad-9` (`kicad/kicad:9.0.9@sha256:e638b79b…`), passes `test_kicad_accepts_the_project[t9]` and `test_control_without_the_fields_is_refused[t9]`, and job `kicad-10` passes the target-10 half.
- [x] 5.2 Add to `CHANGELOG.md` under `## [Unreleased]`, in bold where behaviour changes: "**Footprints from the built-in catalog and from `dsl.Footprint` now carry `Reference` and `Value` on the board and in the project library, so a catalog-only board passes `check`. Projects built before gain the two properties on their next build: this is the first change of KiCad bytes since 0.2.0, and only for these footprints.** Altium projects do not change." Update the row of this change in `docs/roadmap.md`. Proof: `git diff --stat HEAD -- CHANGELOG.md docs/roadmap.md` lists both files.
  - Open: the changelog entry is the last one of `## [Unreleased]`. `docs/roadmap.md` is left to the coordinator of the milestone, who edits it for every change of the wave.
  - 2026-10-08, base `04ef42a`: ticked. The entry now says that both majors verified it (the `kicad-9` and `kicad-10` jobs of CI run 37772583226 pass `tests/kicad/build/test_catalog_only.py`), and the row of c0077 in `docs/roadmap.md` ("v0.4: proposals on other branches") says that it ships in 0.4; `git diff --stat HEAD -- CHANGELOG.md docs/roadmap.md` lists both files.
- [x] 5.3 Stop and report "ready for the long runs": `make check-fast`, the unit suite on Python 3.11 (`uv run --python 3.11 pytest tests/unit -q`), `uv run pytest tests/residue tests/corpus/test_manifest.py -q` after `git add -A`, `uv run python tools/residue/scan.py`, and `openspec validate --all --strict --no-interactive`. The full `make check` is run once by the coordinator on the rebased branch, not by the implementing agent. Proof: each command exits 0.
  - Open: no Python 3.11 is installed on this machine and installing one is a download, so the 3.11 run is left to CI. `make check-fast PYTEST_WORKERS=3` exits 2 (2026-10-07: lint, format, types and residue pass; 1 failed, 9575 passed, 18 skipped): the one failure is `test_cited_ids_registered` of task 1.1, which fails the same way on a clean copy of `f36e08d9`. 2026-10-07: `pytest tests/residue tests/corpus/test_manifest.py` after `git add -A`: 85 passed, exit 0; `tools/residue/scan.py`: 0 hits, exit 0; `openspec validate --all --strict --no-interactive`: 100 passed, exit 0.
  - 2026-10-08, branch `v04-close-a` on `04ef42a`, with every edit of the closing pass of c0077 to c0103 in the tree (the gate of the release, run once for all of them): `make check-fast PYTEST_WORKERS=4` exits 0 (ruff check, the guide's `--check`, ruff format, pyright, the residue scan, and 12731 passed, 29 skipped); the whole unit suite on Python 3.11.15, `uv run --isolated --python 3.11 --extra dev pytest tests/unit -q -n 4 -p no:cacheprovider`: 12348 passed, 25 skipped, exit 0; after `git add -A`, `uv run pytest tests/residue tests/corpus/test_manifest.py -q`: 80 passed, 5 skipped (no `kicad-cli`, no KiCad libraries), exit 0; `uv run python tools/residue/scan.py`: 0 hits, exit 0; `openspec validate --all --strict --no-interactive` reports the same six errors as on `04ef42a` (c0084, c0085 twice, c0086, c0108, c0128) and none of this change, besides the long-requirement warnings. The full `make check` is the coordinator's.

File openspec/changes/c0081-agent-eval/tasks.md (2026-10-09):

## 0. Entry check

- [x] 0.1 Read the living `agent-guide` and `verification-loop` specs and `openspec list`. Write under this task, with the date and the commit: that `0.3.0` is released with c0123, and that c0077 and c0079 are archived (stop here otherwise); how the nets of the model name a pin of a part whose `pad_map` gives one pin several pads (the judge's `nets` check and the task `custom-footprint` follow it); whether c0097 is on `dev`, and what `check` reports for the starting project of `fix-short` that day; what `fenolite check` returns for a correct built project when no `kicad-cli` is found (the exit code and the stage statuses that the judge's `unjudged` rule reads); the catalog ids each task needs and that the catalog on `dev` has them (else the task's circuit is adjusted, and the adjustment is written here); and that S-0618 is still free for the page that documents the non-interactive mode of the first real runner (else the next free id of the block S-0617 to S-0619). Register that page in `docs/evidence/sources.md`. Proof: `openspec validate c0081-agent-eval --strict --no-interactive` passes after any re-base; `uv run pytest tests/unit/test_provenance.py tests/unit/verify/test_cited_ids.py -q`; `grep -c '^| S-0618 ' docs/evidence/sources.md` prints `1`.
  - **Entry note, 2026-10-08, on the integration branch `v04` at `3336325e`** (the base the coordinator gave; `origin/dev` is at `446b310a`).
  - **Prerequisites, not as the proposal states them.** `0.3.0` is not released: the package says `0.2.1`. c0123 is on the base (`446b310a`). c0077 and c0079 are implemented on `v04` (`f09afbfc`, `3336325e`) and not archived. This task says to stop then; the coordinator decided to implement on `v04`, where the code of the three changes is present, and that decision is recorded here, not taken by the implementer.
  - **A pin with several pads.** A net of the model lists a pin once, as `PinRef(component_id, pin)` with the pin number; the pads are pairs of `Component.pin_pad_map` (`(("2", "2"), ("2", "4"))` for `pad_map={"2": ("2", "4")}`, read back from the built solution of `custom-footprint`). The judge's `nets` check reads the pin numbers only. A member that names pins by their name is resolved to the pins of that name.
  - **c0097** is not on the base. The starting project of `fix-short` (built, then routed with `direct`): `fenolite check board/build --stages model.validate,copper.clearance` exits 5 with one `copper.short` (GND and VIN, located at two segments).
  - **Without `kicad-cli`**, `fenolite check` of a correct built project exits 6 with `FEN-6001` on standard error; its envelope carries `evidence.level` `UNVERIFIED` and no stage. The judge's `unjudged` rule reads the exit code 6, and a `drc.kicad` stage that is skipped for `kicad-cli` when a later version reports one.
  - **With `kicad-cli` 10.0.6**, the envelope of a passing `check` carries `evidence.level` `INFERRED` (the lowest level of its stages wins; `erc.kicad`, `zone.fill` and `drc.kicad` are `KICAD-VERIFIED`). The judge records that level as it is.
  - **Catalog ids** (all present on the base): `led-indicator`, `fix-short`: `Connector_2`, `Resistor`, `LED`, `Header_1x2_P2.54`, `Chip_0603`; `two-sided`: the same with `Chip_0805`; `custom-footprint`: `Connector_3`, `Header_1x3_P2.54`, and a symbol and a footprint authored in the script; `regulator-zone`: `Connector_2`, `Resistor`, `Zener_Diode`, `Capacitor_Film`, `Header_1x2_P2.54`, `R_Axial_Vishay_MRS16_P7.62`, `DO35_P10.16_Diodes`, `C_Film_Wima_MKS02_L4.6_W2.5_P2.5`.
  - **Adjustment of `regulator-zone`.** The circuit is a Zener shunt regulator, not a three-pin regulator. `Fenolite:Linear_Regulator` has `power_in` pins, so KiCad's ERC reports `kicad.erc.power-pin-not-driven` for a supply that comes from a connector; the script's answer is `Power(vin, gnd)`, and a design that names the catalog and a `Power` interface does not build: `build.vendor-unsafe-name`, "symbol libraries 'Fenolite' and 'fenolite' differ only in letter case" (the catalog library and the library of the power flag). That is a defect of Fenolite found while the task was written; no change addresses it yet, and it is reported to the coordinator. Every catalog symbol with a `power_in` pin is affected (`Linear_Regulator`, `Comparator`, `Operational_Amplifier`, `Offline_Power_Controller`).
  - **Exported files** lie in subfolders (`board/fab/gerbers/*.gbr`, `board/fab/drill/*.drl`), so the tasks' `outputs` patterns are `board/fab/**/*.gbr` and `board/fab/**/*.drl`.
  - **S-0618** was free and is registered: `https://code.claude.com/docs/en/headless`, read on 2026-10-08 through the fetch tool, which returned the page as Markdown text. The page names no version flag, no cost or turn cap and no output field for model, turns or tokens, so the row `claude-code` is written without them and marked `unconfigured` (task 4.2).
  - Proofs: `openspec validate c0081-agent-eval --strict --no-interactive` passes; `uv run pytest tests/unit/test_provenance.py tests/unit/verify/test_cited_ids.py -q`: 14 passed; `grep -c '^| S-0618 ' docs/evidence/sources.md` prints `1`.
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

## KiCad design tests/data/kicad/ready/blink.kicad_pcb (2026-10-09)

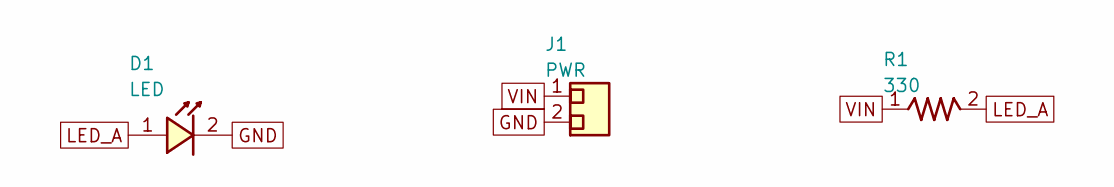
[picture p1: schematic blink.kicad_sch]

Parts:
D1: LED; Chip_0603
J1: PWR; Header_1x2_P2.54
R1: 330; Chip_0603

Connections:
GND: D1.2 (K), J1.2
LED_A: D1.1 (A), R1.2 (B)
VIN: J1.1, R1.1 (A)

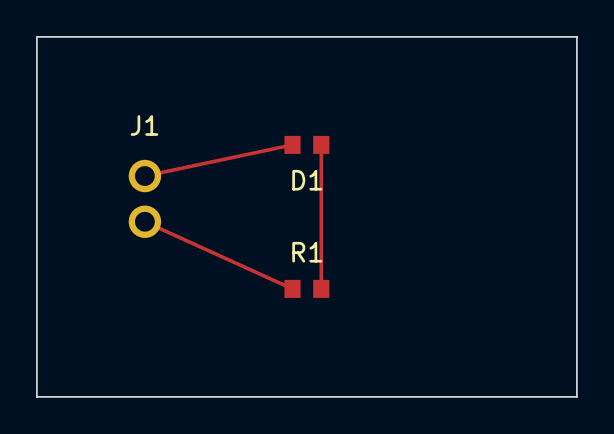
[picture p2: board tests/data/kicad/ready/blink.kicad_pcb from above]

Board: 2 copper layers, 30.0 x 20.0 mm, 3 parts (0 on the bottom side), 3 nets.

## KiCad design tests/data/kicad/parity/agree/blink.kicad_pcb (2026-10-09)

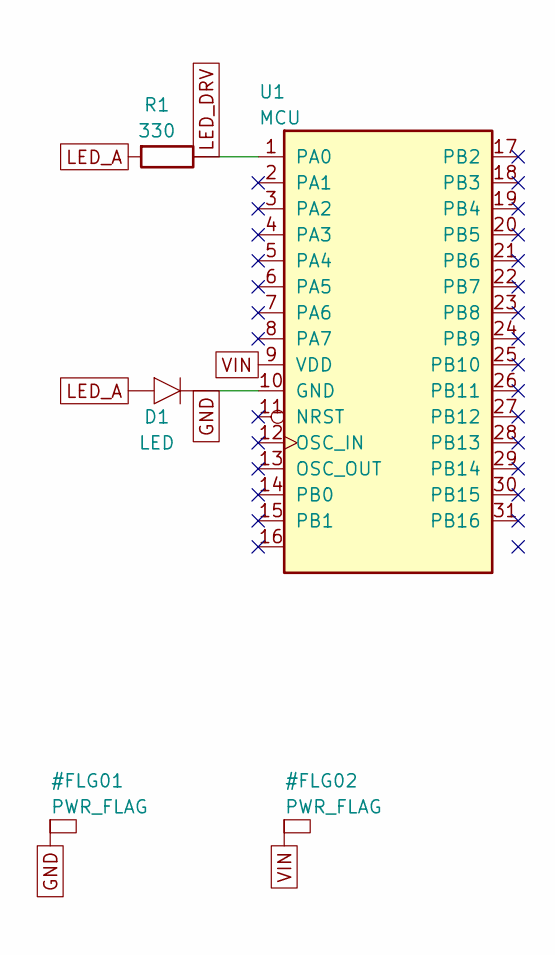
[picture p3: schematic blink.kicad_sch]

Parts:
D1: LED; Mini_LED_THT_3mm
R1: 330; Mini_R_0603
U1: MCU; Mini_QFP-32_7x7mm_P0.8mm

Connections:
GND: D1.1 (K), U1.10 (GND)
LED_A: D1.2 (A), R1.2
LED_DRV: R1.1, U1.1 (PA0)
VIN: U1.9 (VDD)

Board: 2 copper layers, 3 parts (1 on the bottom side), 3 nets, no tracks yet.

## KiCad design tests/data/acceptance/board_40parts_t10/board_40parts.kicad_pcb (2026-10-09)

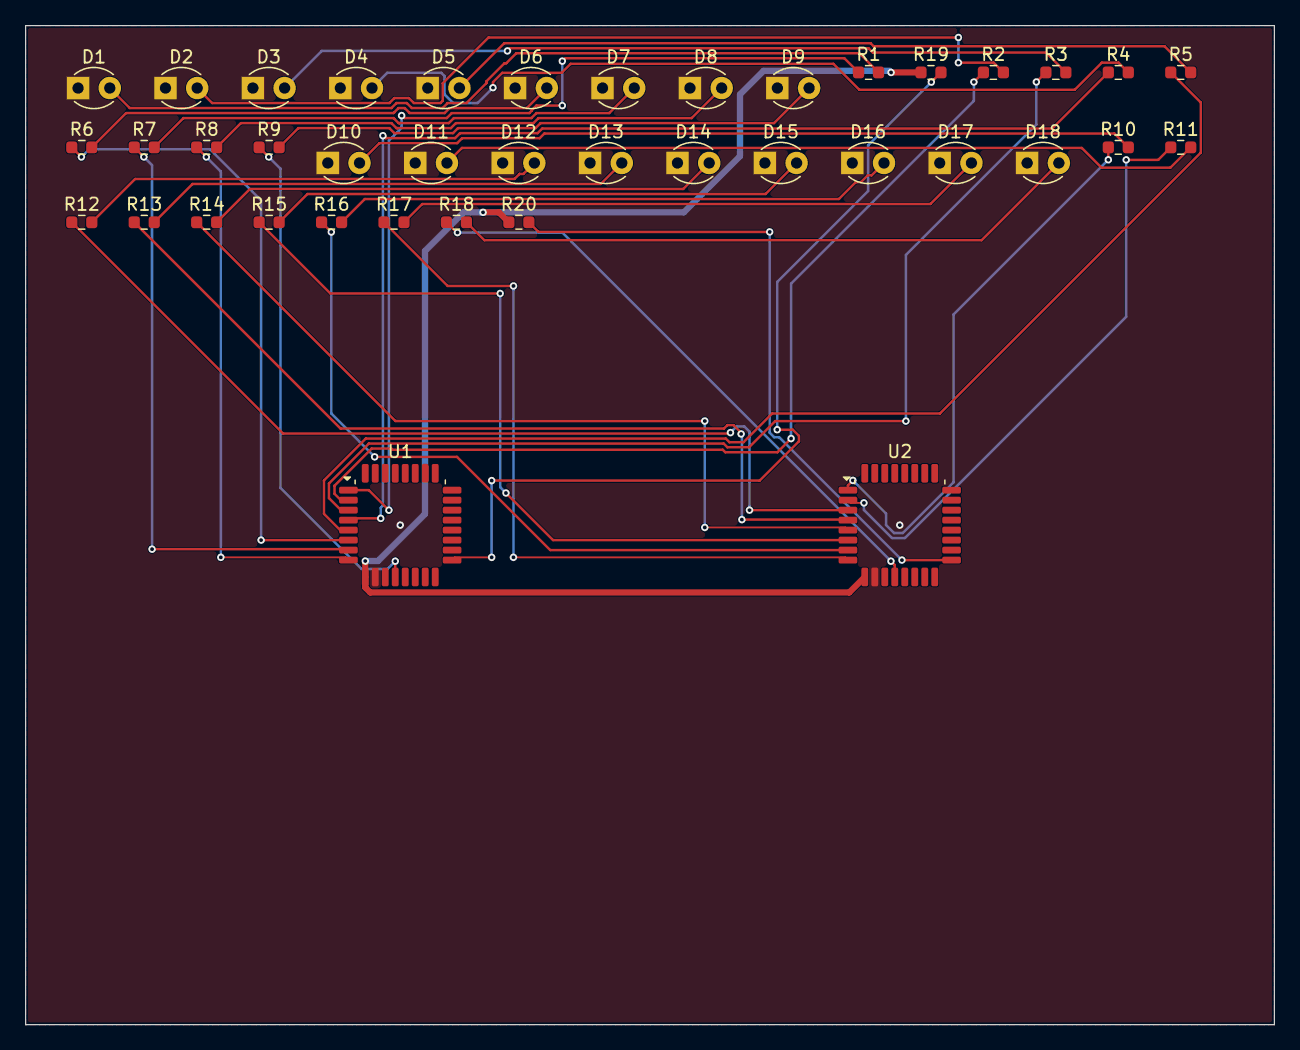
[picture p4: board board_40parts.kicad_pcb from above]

Board: 2 copper layers, 100.0 x 80.0 mm, 40 parts (0 on the bottom side), 40 nets.

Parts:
D1, D2, D3, D4, D5, D6, D7, D8, D9, D10, D11, D12, D13, D14, D15, D16, D17, D18: LED; Mini_LED_THT_3mm
R1, R2, R3, R4, R5, R6, R7, R8, R9, R10, R11, R12, R13, R14, R15, R16, R17, R18: 330; Mini_R_0603
R19, R20: 10k; Mini_R_0603
U1, U2: MCU; Mini_QFP-32_7x7mm_P0.8mm

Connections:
DRV1: R1.1, U1.1
DRV2: R2.1, U1.2
DRV3: R3.1, U1.3
DRV4: R4.1, U1.4
DRV5: R5.1, U1.5
DRV6: R6.1, U1.6
DRV7: R7.1, U1.7
DRV8: R8.1, U1.8
DRV9: R9.1, U1.12
DRV10: R10.1, U2.1
DRV11: R11.1, U2.2
DRV12: R12.1, U2.3
DRV13: R13.1, U2.4
DRV14: R14.1, U2.5
DRV15: R15.1, U2.6
DRV16: R16.1, U2.7
DRV17: R17.1, U2.8
DRV18: R18.1, U2.12
EN1: R19.2, U1.17
EN2: R20.2, U2.17
GND: D1.1, D2.1, D3.1, D4.1, D5.1, D6.1, D7.1, D8.1, D9.1, D10.1, D11.1, D12.1, D13.1, D14.1, D15.1, D16.1, D17.1, D18.1, U1.10, U2.10
LED1: D1.2, R1.2
LED2: D2.2, R2.2
LED3: D3.2, R3.2
LED4: D4.2, R4.2
LED5: D5.2, R5.2
LED6: D6.2, R6.2
LED7: D7.2, R7.2
LED8: D8.2, R8.2
LED9: D9.2, R9.2
LED10: D10.2, R10.2
LED11: D11.2, R11.2
LED12: D12.2, R12.2
LED13: D13.2, R13.2
LED14: D14.2, R14.2
LED15: D15.2, R15.2
LED16: D16.2, R16.2
LED17: D17.2, R17.2
LED18: D18.2, R18.2
VIN: R19.1, R20.1, U1.9, U2.9

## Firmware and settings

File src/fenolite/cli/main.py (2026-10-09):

# SPDX-License-Identifier: Apache-2.0
# Copyright (c) 2026 Fenolite contributors
"""The ``fenolite`` dispatcher: global flags, command discovery, errors, exit codes and the
mutation protocol. See ``docs/cli-contract.md``."""

from __future__ import annotations

import argparse
import contextlib
import dataclasses
import os
import random
import signal
import sys
import time
from collections.abc import Generator, Mapping, Sequence
from datetime import UTC, datetime
from pathlib import Path
from typing import Any, NoReturn, TextIO, cast

from fenolite import __version__
from fenolite.cli import plans
from fenolite.cli import progress as progress_records
from fenolite.cli.api import Command, Context, PlannedWrite, Result, discover
from fenolite.cli.errors import CliError, ErrorInfo, from_exception
from fenolite.cli.exitcodes import ExitCode
from fenolite.cli.output import (
    CursorError,
    Envelope,
    Evidence,
    FieldNotFoundError,
    InputRef,
    OutputMode,
    Receipt,
    WrittenFile,
    make_receipt,
    page,
    parse_fields,
    project_fields,
    render_json,
    render_text,
    resolve_mode,
    write_error,
)
from fenolite.core.errors import FenoliteError, Issue
from fenolite.core.io import WriteError, atomic_write_all, sha256_bytes
from fenolite.core.state import state_dir

KICAD_TARGETS = (9, 10)
"""The values of ``--kicad-version``: the KiCad majors Fenolite writes for (``versions.TARGET_MAJORS``)."""
DEFAULT_KICAD_TARGET = 10
FORMATS = ("concise", "detailed")
"""The values of ``--format``."""
PAGED_ISSUES = "issues"
MUTATION_FLAGS = ("--dry-run", "--confirm", "--plan")
"""The flags of the mutation protocol, which every mutating command accepts."""


class Interrupted(KeyboardInterrupt):
    """SIGTERM or SIGINT reached ``fenolite``. Raised in the main thread, so that it passes through every
    tool call (which kills its process) and through a write in progress (which rolls back); the dispatcher
    turns it into ``FEN-1003``. A ``KeyboardInterrupt``, not an ``Exception``: no handler of a library
    error catches it, and code that lets Ctrl+C pass lets it pass."""


class _Parser(argparse.ArgumentParser):
    """argparse that raises typed usage errors instead of printing and exiting."""

    def error(self, message: str) -> NoReturn:
        raise CliError("FEN-2001", message, hint=f"run '{self.prog} --help'")


def _add_global_options(parser: argparse.ArgumentParser, *, top_level: bool) -> None:
    default: object = argparse.SUPPRESS
    group = parser.add_argument_group("output and determinism")
    group.add_argument("--json", action="store_true", default=False if top_level else default,
                       help="force JSON output")  # fmt: skip
    group.add_argument("--text", action="store_true", default=False if top_level else default,
                       help="force human-readable output")  # fmt: skip
    group.add_argument("--fields", default=None if top_level else default, metavar="A,B.C",
                       help="keep only these dotted paths of 'result'")  # fmt: skip
    group.add_argument("--limit", type=int, default=None if top_level else default, metavar="N",
                       help="keep N items of the command's main list (see 'page' in the result)")  # fmt: skip
    group.add_argument("--cursor", default=None if top_level else default, metavar="TOKEN",
                       help="continue a list from the 'next' of the page before")  # fmt: skip
    group.add_argument("--format", choices=FORMATS, default="detailed" if top_level else default,
                       help="concise keeps one issue per code, with counts (default detailed)")  # fmt: skip
    group.add_argument("--progress", action="store_true", default=False if top_level else default,
                       help="write progress records on stderr while the command runs")  # fmt: skip
    group.add_argument("--seed", type=int, default=None if top_level else default,
                       help="seed for generated ids (reproducible output)")  # fmt: skip
    group.add_argument("--timestamp", default=None if top_level else default, metavar="ISO8601",
                       help="fixed timestamp for generated dates")  # fmt: skip
    group.add_argument("--no-backup", action="store_true", default=False if top_level else default,
                       help="do not keep .bak copies of overwritten files")  # fmt: skip
    kicad = parser.add_argument_group("KiCad output")
    kicad.add_argument("--kicad-version", type=int, choices=KICAD_TARGETS, dest="kicad_version",
                       default=DEFAULT_KICAD_TARGET if top_level else default, metavar="{9,10}",
                       help="KiCad major that written files target (default 10)")  # fmt: skip
    kicad.add_argument("--allow-lossy", action="store_true", default=False if top_level else default,
                       help="drop content the target KiCad version cannot read, with a warning")  # fmt: skip


def build_parser(commands: dict[str, Command]) -> argparse.ArgumentParser:
    parser = _Parser(prog="fenolite", description="Headless, agent-first PCB design automation.")
    parser.add_argument("--version", action="version", version=f"fenolite {__version__}")
    _add_global_options(parser, top_level=True)
    sub = parser.add_subparsers(dest="command", metavar="COMMAND", parser_class=_Parser)
    for command in sorted(commands.values(), key=lambda c: c.name):
        if command.help is None:  # hidden: not listed in --help
            child = sub.add_parser(command.name)
        else:
            child = sub.add_parser(command.name, help=command.help, description=command.help)
        _add_global_options(child, top_level=False)
        if command.mutates:
            protocol = child.add_argument_group("writing files")
            protocol.add_argument("--dry-run", action="store_true", help="show the plan; write nothing")
            protocol.add_argument("--confirm", action="store_true", help="perform the writes")
            protocol.add_argument(
                "--plan",
                metavar="ID",
                default=None,
                help="with --confirm: write the reviewed plan of this id",
            )
        command.register(child)
    return parser


def global_flags() -> list[str]:
    """The long flags that every command accepts, in the order of ``--help``."""
    parser = argparse.ArgumentParser(add_help=False)
    _add_global_options(parser, top_level=True)
    return [option for action in parser._actions for option in action.option_strings]  # pyright: ignore[reportPrivateUsage]


def _timestamp(value: str | None) -> datetime:
    if value is None:
        return datetime.now(UTC)
    try:
        parsed = datetime.fromisoformat(value)
    except ValueError as exc:
        raise CliError("FEN-2004", f"invalid --timestamp {value!r}") from exc
    return parsed if parsed.tzinfo is not None else parsed.replace(tzinfo=UTC)


def _context(args: argparse.Namespace, mode: OutputMode, err: TextIO) -> Context:
    seed: int | None = args.seed
    rng = random.Random(seed) if seed is not None else random.Random()
    ctx = Context(
        mode=mode,
        seed=seed,
        timestamp=_timestamp(args.timestamp),
        rng=rng,
        no_backup=bool(args.no_backup),
        cwd=Path.cwd(),
        kicad_target=int(args.kicad_version),
        allow_lossy=bool(args.allow_lossy),
        state=state_dir(),
    )
    if not args.progress:
        return ctx
    reporter = progress_records.StderrProgress(mode, err, str(args.command), progress_records.INTERVAL)
    reporter.start()
    return dataclasses.replace(ctx, progress=reporter)


def _quiet(ctx: Context) -> None:
    """End the progress records: what follows on stderr is the error object, alone on the last line."""
    close = getattr(ctx.progress, "close", None)
    if callable(close):
        close()


def _emit(envelope: Envelope, ctx: Context, out: TextIO, text: str | None = None) -> None:
    """Print the envelope. ``text`` (``Result.text``) is used by text mode only."""
    _quiet(ctx)
    out.write((render_json(envelope) if ctx.mode == "json" else render_text(envelope, text)) + "\n")


def _envelope(command: Command, outcome: Result, result: dict[str, object], *, ok: bool,
              receipt: Receipt | None, started: float) -> Envelope:  # fmt: skip
    return Envelope(
        ok=ok,
        command=command.name,
        schema=command.schema,
        input=outcome.input,
        result=dict(result),
        issues=outcome.issues,
        evidence=outcome.evidence,
        receipt=receipt,
        elapsed_ms=max(0, round((time.perf_counter() - started) * 1000)),
    )


def _refusal(exc: Exception) -> Result:
    """A refusal's own issues for the envelope (a ``FenoliteError`` whose ``issues`` holds ``Issue``s)."""
    found: object = getattr(exc, "issues", None) if isinstance(exc, FenoliteError) else None
    if not isinstance(found, (list, tuple)):
        return Result()
    items = tuple(cast(Sequence[object], found))
    if items and all(isinstance(i, Issue) for i in items):
        return Result(issues=cast(tuple[Issue, ...], items))
    return Result()


def _usage(message: str, where: str) -> CliError:
    return CliError("FEN-2001", message, where=where)


def _limit(command: Command, args: argparse.Namespace) -> int | None:
    """The page size in force: ``--limit``, else the command's default. Refused before the command runs:
    a limit below 1, ``--limit`` on a command without a paged list, and a cursor without a limit."""
    given: int | None = args.limit
    if given is not None and command.paged is None:
        raise _usage(f"{command.name} has no list to page; --limit does not apply", "--limit")
    if given is not None and given < 1:
        raise _usage("--limit is at least 1", "--limit")
    limit = given if given is not None else command.default_limit
    if args.cursor is not None and limit is None:
        raise _usage("--cursor needs a limit in force: pass --limit as on the page before", "--cursor")
    return limit


def _holder(result: dict[str, Any], path: str) -> tuple[dict[str, Any], str] | None:
    """The mapping that holds the list at the dotted ``path`` and its key, or ``None``."""
    node: dict[str, Any] = result
    parts = path.split(".")
    for part in parts[:-1]:
        inner: object = node.get(part)
        if not isinstance(inner, dict):
            return None
        node = cast(dict[str, Any], inner)
    return (node, parts[-1]) if isinstance(node.get(parts[-1]), list) else None


def _concise(issues: tuple[Issue, ...]) -> tuple[tuple[Issue, ...], list[dict[str, object]]]:
    """The first issue of each code in order, and per code its count and its counts by severity."""
    first: dict[str, Issue] = {}
    counts: dict[str, dict[str, int]] = {}
    for issue in issues:
        first.setdefault(issue.code, issue)
        by_severity = counts.setdefault(issue.code, {})
        by_severity[issue.severity] = by_severity.get(issue.severity, 0) + 1
    summary: list[dict[str, object]] = [
        {"code": code, "count": sum(counts[code].values()), "by_severity": dict(sorted(counts[code].items()))}
        for code in sorted(counts)
    ]
    return tuple(first.values()), summary


def _paged(command: Command, result: dict[str, Any], issues: tuple[Issue, ...], limit: int,
           cursor: str | None) -> tuple[dict[str, Any], tuple[Issue, ...]]:  # fmt: skip
    """``result`` and ``issues`` with the command's paged list cut to one page and ``result.page`` set.
    A ``total`` and a ``truncated`` beside the list are set to the whole length and to whether the page
    is not the whole list."""
    assert command.paged is not None
    try:
        for path in command.paged.split("|"):
            if path == PAGED_ISSUES:
                cut = page(issues, limit, cursor)
                issues = cast(tuple[Issue, ...], cut.items)
            else:
                found = _holder(result, path)
                if found is None:
                    continue
                holder, key = found
                cut = page(cast(list[Any], holder[key]), limit, cursor)
                result = _replaced(result, path, list(cut.items), cut)
            result["page"] = {
                "path": path, "limit": cut.limit, "offset": cut.offset, "total": cut.total, "next": cut.next,
            }  # fmt: skip
            return result, issues
    except CursorError as exc:
        raise _usage(str(exc), "--cursor") from exc
    if cursor is not None:
        raise _usage(f"{command.name} returned no list to continue", "--cursor")
    return result, issues


def _replaced(result: dict[str, Any], path: str, items: list[Any], cut: Any) -> dict[str, Any]:
    """A copy of ``result`` with the list at ``path`` replaced by ``items`` (the holders are copied)."""
    parts = path.split(".")
    out = dict(result)
    node = out
    for part in parts[:-1]:
        node[part] = dict(node[part])
        node = node[part]
    node[parts[-1]] = items
    if "total" in node:
        node["total"] = cut.total
    if "truncated" in node:
        node["truncated"] = len(items) < cut.total
    return out


def _payload(write: PlannedWrite) -> bytes:
    """The bytes of a planned write. A deferred write's source is called here, once, and what it returns
    must have the declared size and SHA-256 (cli-contract, "Deferred writes")."""
    if write.source is None:
        return write.data
    data = write.source()
    found = sha256_bytes(data)
    if len(data) != write.size or found != write.sha256:
        raise CliError(
            "FEN-3006",
            f"{write.path}: expected {write.size} bytes with SHA-256 {write.sha256}, "
            f"found {len(data)} bytes with SHA-256 {found}; nothing was written",
            where=write.path,
        )
    return data


def _rows(writes: Sequence[PlannedWrite], cwd: Path) -> list[dict[str, Any]]:
    """One row per planned write: what ``result.plan`` shows, and ``replaces``, the SHA-256 of the file
    it would replace (``None`` without one), which the plan id binds."""
    rows: list[dict[str, Any]] = []
    for w in writes:
        target = cwd / w.path
        rows.append(
            {
                "path": w.path,
                "kind": w.kind,
                "bytes": len(w.data) if w.size is None else w.size,
                "sha256": sha256_bytes(w.data) if w.sha256 is None else w.sha256,
                "overwrite": target.exists(),
                "replaces": plans.digest_of(target),
            }
        )
    return rows


def _shown(rows: Sequence[Mapping[str, Any]]) -> list[dict[str, Any]]:
    return [{key: row[key] for key in ("path", "kind", "bytes", "sha256", "overwrite")} for row in rows]


def _digests(depends: Sequence[str], cwd: Path) -> list[tuple[str, str | None]]:
    return [(path, plans.digest_of(cwd / path)) for path in depends]


def _named(path: str) -> str:
    """How an error names a file: as given when relative to the working folder, else by its name."""
    return Path(path).name if Path(path).is_absolute() else path


def _stale(why: str, where: str) -> CliError:
    return CliError("FEN-4002", f"{why}; nothing was written", where=where)


def _replay(command: Command, staged: plans.StagedPlan, args: Mapping[str, Any], ctx: Context) -> Result:
    """The result of the staged plan, its writes holding the staged bytes, once nothing a review relied on
    has changed; ``FEN-4002`` names the first thing that has. The command is not called."""
    if staged.cwd != str(ctx.cwd):
        raise _stale(f"the plan {staged.id} was made in another working folder", "--plan")
    if staged.command != command.name:
        raise _stale(f"the plan {staged.id} was made by the command {staged.command!r}", "--plan")
    if staged.arguments != dict(args):
        keys = sorted(set(staged.arguments) | set(args))
        first = next(key for key in keys if staged.arguments.get(key) != args.get(key))
        raise _stale(
            f"the plan {staged.id} was made for another command line (the argument {first!r} differs)",
            "--plan",
        )
    for path, digest in staged.depends:
        if plans.digest_of(ctx.cwd / path) != digest:
            raise _stale(f"{_named(path)} changed after the plan {staged.id} was reviewed", _named(path))
    for row in staged.writes:
        found = plans.digest_of(ctx.cwd / str(row["path"]))
        if found != row["replaces"]:
            what = "exists now" if row["replaces"] is None else "changed" if found else "is gone"
            raise _stale(f"{row['path']} {what} after the plan {staged.id} was reviewed", str(row["path"]))
    try:
        writes = tuple(PlannedWrite(str(r["path"]), staged.data(r), str(r["kind"])) for r in staged.writes)
        reply = staged.reply
        issues = tuple(Issue(**issue) for issue in reply["issues"])
        evidence = Evidence(**reply["evidence"])
        given = None if reply["input"] is None else InputRef(**reply["input"])
        result = dict(reply["result"])
        write_on_error = bool(reply["write_on_error"])
    except (plans.DamagedPlan, KeyError, TypeError, ValueError) as exc:
        plans.remove(ctx.state, staged.id)
        raise _stale(f"the staged plan {staged.id} is damaged and was removed ({exc})", "--plan") from exc
    return Result(result, issues, evidence, given, writes, write_on_error=write_on_error)


def _load(ctx: Context, plan: str) -> plans.StagedPlan | None:
    try:
        return plans.load(ctx.state, plan)
    except plans.DamagedPlan as exc:
        plans.remove(ctx.state, plan)
        raise _stale(f"the staged plan {plan} is damaged and was removed ({exc})", "--plan") from exc


def _stage(
    command: Command,
    outcome: Result,
    args: Mapping[str, Any],
    ctx: Context,
    plan: str,
    rows: Sequence[Mapping[str, Any]],
    depends: Sequence[tuple[str, str | None]],
) -> Issue | None:
    """Keep the plan for ``--confirm --plan``; the warning ``plan.not-staged`` when it cannot be kept. A
    plan that holds a deferred write has no bytes before ``--confirm`` and is planned again instead."""
    if any(w.deferred for w in outcome.writes):
        return None
    try:
        plans.stage(
            ctx.state,
            plan,
            command=command.name,
            args=args,
            cwd=str(ctx.cwd),
            depends=depends,
            writes=[{k: v for k, v in row.items() if k != "overwrite"} for row in rows],
            payloads=[w.data for w in outcome.writes],
            reply={
                "result": outcome.result,
                "issues": outcome.issues,
                "evidence": outcome.evidence,
                "input": outcome.input,
                "write_on_error": outcome.write_on_error,
            },
        )
    except plans.StageError as exc:
        return Issue(
            "plan.not-staged",
            "warning",
            f"the plan {plan} was not staged: {exc}; --confirm --plan {plan} will run the command again "
            "and write only when the new plan has the same id",
            command.name,
        )
    return None


def _failed(command: Command, exc: Exception, ctx: Context, started: float, out: TextIO, err: TextIO,
            outcome: Result | None = None) -> int:  # fmt: skip
    """The reply of a command that raised: the envelope with ``ok`` false and one error object."""
    failure = exc if isinstance(exc, CliError) else from_exception(exc, command.name)
    shown = _refusal(exc) if outcome is None else outcome
    _emit(_envelope(command, shown, {}, ok=False, receipt=None, started=started), ctx, out)
    write_error(failure.info(), ctx.mode, err)
    return int(failure.exit_code)


def _dispatch(command: Command, args: argparse.Namespace, ctx: Context, started: float,
              out: TextIO, err: TextIO) -> int:  # fmt: skip
    try:
        return _perform(command, args, ctx, started, out, err)
    except KeyboardInterrupt:  # Interrupted, or a Ctrl+C where the handler is not installed
        _emit(_envelope(command, Result(), {}, ok=False, receipt=None, started=started), ctx, out)
        write_error(CliError("FEN-1003", where=command.name).info(), ctx.mode, err)
        return int(ExitCode.INTERNAL)
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

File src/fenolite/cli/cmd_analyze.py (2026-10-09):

# SPDX-License-Identifier: Apache-2.0
# Copyright (c) 2026 Fenolite contributors
"""``fenolite analyze PATH``: current capacity, clearance and creepage of a board, and on request its
power paths, the insulation between its layers and the lengths of its nets (capability board-analyses,
"Analyze command", "Power and insulation kinds" and "Length kind in the analyze command";
``docs/analyses.md``; ``docs/cli-contract.md``, "analyze").

The command reads the board through the backend that detects it, measures, and judges the measures only
against the requirements the user gives. It runs no tool and writes no file. Fenolite assumes no
thickness, no temperature rise, no resistivity, no groove width and no requirement value.
"""

from __future__ import annotations

import argparse
import dataclasses
import hashlib
from collections.abc import Sequence
from decimal import Decimal, InvalidOperation
from pathlib import Path
from typing import Any, cast

from fenolite.analysis import EVIDENCE
from fenolite.analysis.boundary import board_boundary
from fenolite.analysis.copper import ARC_TOL_NM
from fenolite.analysis.current import analyze_current
from fenolite.analysis.distance import analyze_distances
from fenolite.analysis.length import measure_lengths
from fenolite.analysis.power import analyze_power
from fenolite.analysis.report import AnalysisReport, sorted_issues
from fenolite.analysis.requirements import Requirements, load_requirements
from fenolite.backends import registry
from fenolite.backends.base import BoardFrame, BoardPad, LengthFacts, LengthSource, ProjectSet
from fenolite.cli._examples import EXAMPLE_BOARD
from fenolite.cli.api import Command, Context, Result
from fenolite.cli.errors import CliError
from fenolite.cli.output import InputRef
from fenolite.core.coords import Point
from fenolite.core.errors import FenoliteError, FormatError, Issue
from fenolite.core.evidence import Evidence
from fenolite.core.units import Nm, parse_length
from fenolite.model.design import Design

HELP = "measure current capacity, clearance and creepage of a board (read-only)"
"""The opt-in kinds are described with their options: power paths and insulation between layers."""
KINDS = ("current", "clearance", "creepage")
"""The kinds that run without ``--kinds``."""
OPT_IN_KINDS = ("power", "insulation", "length")
ALL_KINDS = (*KINDS, *OPT_IN_KINDS)
ALL_LAYERS = "*"
_CLEARANCE_CODES = ("analysis.clearance-below", "analysis.clearance-undecided", "analysis.embedded-below")
_CREEPAGE_CODES = ("analysis.creepage-below", "analysis.creepage-undecided")


def _register(parser: argparse.ArgumentParser) -> None:
    parser.description = (
        HELP + ". Fenolite measures and the user decides: no reply claims conformance to a standard, and "
        "findings exist only against the requirements you give; see docs/analyses.md."
    )
    parser.add_argument("path", metavar="PATH", help="a board file that a backend reads")
    parser.add_argument(
        "--kinds",
        default=None,
        metavar="K,K",
        help=f"analyses to run (default: {','.join(KINDS)}; on request: {','.join(OPT_IN_KINDS)})",
    )
    parser.add_argument(
        "--requirements", default=None, metavar="FILE", help="your requirements, a TOML file of integers"
    )
    parser.add_argument(
        "--temp-rise", default=None, metavar="KELVIN", help="temperature rise for the capacity, e.g. 10"
    )
    parser.add_argument(
        "--copper-thickness",
        action="append",
        default=[],
        metavar="[LAYER=]LENGTH",
        help="copper thickness of every layer, or of one layer (repeatable), e.g. 35um or In1.Cu=18um",
    )
    parser.add_argument("--via-plating", default=None, metavar="LENGTH", help="plating of a via barrel")
    parser.add_argument("--board-thickness", default=None, metavar="LENGTH", help="thickness of the board")
    parser.add_argument(
        "--pair",
        action="append",
        nargs="+",
        default=[],
        metavar="NET",
        help="measure the distances of this pair of nets: --pair NET_A NET_B (repeatable)",
    )
    parser.add_argument(
        "--within", default=None, metavar="LENGTH", help="measure every pair of nets closer than this"
    )
    parser.add_argument(
        "--arc-tol", default=None, metavar="LENGTH", help="chord error of polygonised copper arcs"
    )
    parser.add_argument(
        "--path",
        dest="power_paths",
        action="append",
        nargs=2,
        default=[],
        metavar=("FROM", "TO"),
        help="with --kinds power: measure the copper between two sets of pads, each REF-PIN[,REF-PIN...] "
        "(repeatable); an estimate against your limits, not a simulation",
    )
    parser.add_argument(
        "--resistivity",
        default=None,
        metavar="NANOOHM_METRES",
        help="with --kinds power: the resistivity of your copper at your temperature, e.g. 17.2; "
        "Fenolite assumes none",
    )
    parser.add_argument(
        "--groove-width",
        default=None,
        metavar="LENGTH",
        help="with creepage: a groove narrower than this is bridged on the creepage path",
    )
    parser.add_argument(
        "--net",
        dest="length_nets",
        action="append",
        default=[],
        metavar="GLOB",
        help="with --kinds length: measure the nets whose name matches this pattern (repeatable); the "
        "total is counted as KiCad of --kicad-version counts it",
    )
    parser.add_argument(
        "--from",
        dest="length_from",
        action="append",
        default=[],
        metavar="REF",
        help="with --kinds length: measure the paths of a net from this part or pad, REF or REF-PIN "
        "(repeatable; default: the first pad of each net)",
    )


def _length(text: str, option: str) -> Nm:
    try:
        value = parse_length(text.strip())
    except ValueError as error:
        raise CliError(
            "FEN-2001", f"{option}: {error}", where=option, hint="lengths need a unit: 35um"
        ) from None
    if value <= 0:
        raise CliError("FEN-2001", f"{option}: must be above 0", where=option)
    return value


def _kinds(text: str | None) -> tuple[str, ...]:
    if text is None:
        return KINDS
    names = [name.strip() for name in text.split(",") if name.strip()]
    unknown = [name for name in names if name not in ALL_KINDS]
    if unknown or not names:
        raise CliError(
            "FEN-2001",
            f"--kinds: unknown kind {', '.join(unknown) or text!r}",
            where="--kinds",
            hint=f"kinds: {','.join(ALL_KINDS)}",
        )
    return tuple(kind for kind in ALL_KINDS if kind in names)
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

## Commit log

2026-09-30 feat: bootstrap Fenolite (package, CLI contract, IP hygiene, design model)
    Implements OpenSpec changes c0001-c0004:
    - c0001 repo bootstrap: stdlib-only `fenolite` package, Apache-2.0 with
    NOTICE and SPDX headers, LEGAL.md/LEGAL-ANNEX.md, DCO, ADR-0004, unit CI
    on ubuntu and macOS, `phenolite` alias distribution and PyPI release
    workflow.
    - c0002 CLI contract v0: JSON envelope and typed errors (schemas), exit
    codes 0-7, --fields, --dry-run/--confirm mutation protocol with atomic
    writes and receipts, --seed/--timestamp, `capabilities` command,
    consistency and package-layering tests.
    - c0003 IP hygiene: ADR-0003 (clean-room), residue scan with pre-commit
    hook and CI step, copylef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
    [api.py, cmd__echo.py, cmd_capabilities.py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]
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2026-10-01 feat(kicad): format versions, token inventory and fuzz on 9.0.9/10.0.6 (c0007)
    Add fenolite.backends.kicad.versions: format constants per kind and
    major, kind and version detection, read/edit/target policy with
    FutureFormatError (FEN-3002), UnsupportedFormatError (FEN-3003) and
    DowngradeRefusedError (FEN-7002), rules text helpers, and the token
    inventory (data/tokens.toml, 184 hand-authored rows with sources, one
    form row, notes for all 40 dated board versions) with matching,
    min_version/min_major and check_emittable. The CLI maps library errors
    to registered codes (new FEN-3003, FEN-3004, FEN-7002).
    tools/kicad_token_fuzz.py proves each row on a real kicad-cli with
    authored CC0 skeletons,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
    [canary.kicad_pcb, future.kicad_pcb, old.kicad_pcb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]
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2026-10-01 feat(kicad): board writer, footprint embedding and DRC reports (c0017)
    - write_board writes a design for KiCad 9.0 or 10.0: target policy (KiCad 8
    boards are read-only, FEN-7003), header, the net form of the target over
    modelled and opaque content, rows 10.0 no longer writes, created boards in
    the canonical child order with the skeleton's head set, key-free uuids,
    outline lowering, projection reconciliation and the emit-check gate with
    --allow-lossy (LossyWriteError, FEN-7001).
    - embed.place_footprint places a library definition on either side with
    uuids derived from a caller key; footprint_extent gives its courtyard or
    pad box. _fpmap gains the definition field map and emit_fo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
    [dimension.kicad_pcb]
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2026-10-02 feat(dsl): thin design DSL and fenolite build (c0011)
    fenolite.dsl describes parts, nets, net classes, interfaces, an outline
    and placements with lengths that always carry a unit and ids keyed by
    names and paths. `fenolite build design.py --out DIR` runs the script
    in-process with its output captured and writes a self-contained KiCad 9
    or 10 project: board, project and rules, vendored footprints with a
    per-target fp-lib-table, the .fenolite/ model and a build record that
    refuses to overwrite outputs edited since the last build.
    GeometryError maps to FEN-3005, refusals list their issues, and
    --fields now also restricts the dispatcher's plan. The CC0 blink is
    checked by kicad-cli 9.0.9 and 10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
    [_script.py, cmd_build.py, main.py]
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2026-10-02 feat(build): --target altium and the experimental Altium build (c0032)
    lens/altium.py checks link forms, texts, letter case and unique ids
    against the closed altium.* table, gives every component the generic
    pins its nets name, validates, writes the project through
    backends.altium, and adds the .fenolite/ layer texts and the c0011 build
    record with target "altium". The project file is planned only when the
    output folder has none, so a project saved by Altium is kept.
    `fenolite build --target {kicad,altium}` (default kicad, unchanged)
    branches before any library is resolved, and `fenolite capabilities`
    lists the writer under result.experimental with INFERRED evidence.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
    [cmd_build.py, cmd_capabilities.py]
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2026-10-02 feat(altium): binary schematic by default and --altium-format (c0033)
    DEFAULT_FORM is now "binary". fenolite build --target altium takes
    --altium-format {binary,ascii}; the option is a usage error (FEN-2001)
    without the Altium target. The schematic's write kind follows the form
    (altium_schdoc_binary or altium_schdoc_ascii), result and the lens summary
    carry schematic_format, and WRITE_KINDS lists the three kinds. A binary
    schematic past 109 FAT sectors gives the error altium.schematic-too-large
    and no file. ALTIUM_BUILD_EVIDENCE also names the H-A-SCHBIN rows.
    c0032's tests that read the schematic as text pass form="ascii", so the
    ASCII golden files are unchanged. Determinism and edited-out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
    [cmd_build.py]
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2026-10-02 feat(check): read-only fenolite check, inspect and doctor (c0013)
    - backends.base: neutral RoundTrip, Validation, Validator, ProjectSet,
    SkippedFile, CanaryState, DrcOutcome and the Oracle protocol.
    - kicad: projectset (the closed copy set of a project, skips
    reported), canary (a clearance rule on its own net appended after the
    user's rules, two tracks beyond the board, inserted as text into
    staged copies), oracle (KicadOracle: verdict, stripping, tool_writes,
    evidence), roundtrip (RT1 in src) and KicadBackend.validate, with
    validate in operations; helpmatrix (command matrix from help pages)
    and kicad_cli_candidates.
    - checks: fixed stages model.validate, erc.lite, drc.kicad an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
    [cmd_check.py, cmd_doctor.py]
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2026-10-02 fix(altium): stagger the power ports of adjacent pins (c0032)
    KiCad 10.0.6's import of the sample showed the ports of U1 and U2 pins 1
    and 2 overlapping: 200-mil stubs on pins 100 mil apart. In a run of ports
    on adjacent pins of one edge, the second, fourth, ... port now gets a
    stub of 200 + 100 * ceil((100 + 70 * M + 100) / 100) mil, M being the
    longest net name of its neighbouring ports, so it sits past both and
    their texts. Nets, records and keys are unchanged; the sample stays on
    A4 in path order, now in three rows.
    The rule is recorded in docs/formats/altium/schematic-ascii.md, the c0032
    requirement "Connectivity on the sheet" is edited in place with the new
    scenario "Ports on adjacent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
    [altium_sample.SchDoc, altium_sample_lf.SchDoc, altium_sample_nouid.SchDoc]
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2026-10-02 feat(altium): symbols of KiCad lib ids in the Altium build (c0034)
    lens.altium resolves KiCad lib ids with c0011's resolver (cmd_build
    builds it only when the design has such lib ids), gives their
    components the symbol's pins, rewrites members named by pin name, takes
    the symbol's Footprint and Value when the part names none, maps the
    symbols into <name>.SchLib and links them there. Unknown pins and
    off-grid symbols are errors, lossy pins warnings. The authored CC0
    example examples/altium_kicad/ has its own KiCad library and table.
    [cmd_build.py]
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2026-10-03 fix(altium): write the PCB library in the form Altium saves (c0035)
    Library/Data now holds the whole board record (2044 fields in 25 lines,
    generated by rule in libboard.py), FileHeader its version double and
    library id, and Library the side streams EmbeddedFonts, ModelsNoEmbed,
    Textures, ComponentParamsTOC and PadViaLibrary. Parameters gains ITEMGUID
    and REVISIONGUID, and the unique-id storage is spelled as Altium spells
    it. FileHeaderSix of the PCB document carries its id block. The test
    reader checks the new rules; the blink goldens and their digests are
    rebuilt. kicad-cli 10.0.6 still converts both files.
    [blink.PcbDoc, blink.PcbLib]
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2026-10-03 fix(altium): write the PCB document in the form Altium saves (c0035)
    Board6 holds the whole board record (docboard.py on top of libboard.py),
    nets and components carry the common keys and unique ids, and the document
    gains UniqueIDPrimitiveInformation, the option storages and the empty
    storages every Altium-saved document holds. The test reader checks the new
    rules with negative controls; blink.PcbDoc and its digest are rebuilt, and
    the spec, design and tasks of c0035 are edited in place.
    [blink.PcbDoc]
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2026-10-03 feat(check): DRC findings, assignment compare and RT2 (c0020)
    fenolite check now judges KiCad's DRC: every violation and unconnected
    item is one located issue (kicad.drc.<type>, REF-PIN through the board's
    native ids, the report position when an item cannot be named), with the
    severity of the report. An unrouted board therefore exits 5.
    Two stages are added. netlist.assignment_compare (default) compares the
    pad nets of the model, the re-read board and pcb export ipcd356 as
    partitions of REF-PIN elements and locates a reassigned pad; the matcher
    of c0009's frame test moves into backends/kicad/padnets.py. roundtrip.rt2
    (opt-in) runs DRC on the board and on Fenolite's re-dump.
    kicad-cli 9.0.9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
    [cmd_check.py]
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2026-10-03 feat(altium): Clearance, Width and Routing Via Style rules, golden documents rebuilt (c0038 9.1, 9.2)
    [blink.PcbDoc, routed.PcbDoc]
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2026-10-03 fix(altium): harness line on the top sheet, small sheets and per-sheet channel offsets (c0037)
    After the maintainer's report of Part H (AD 26.5, 2026-10-03):
    - H3: a harness between two neighbouring modules is one signal harness
    line between the two sheet entries; no blocks or labels on the top
    sheet, so no net gets multiple names.
    - H7: a binary sheet under 4096 bytes gets one hidden sheet parameter,
    so FileHeader is never stored in the mini stream (H-A-SCHBIN-MINI,
    pending); CHANNELOFFSET counts the parts of each sheet (S-0188).
    - A readback checks that every board component links to a schematic
    component through a sheet symbol and that every module sheet is
    reachable from the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
    [altium_hier.PrjPcb, altium_hier.SchDoc]
2026-10-03 fix(altium): list the schematic documents first in the project file, remove the sheet padding (c0037)
    After the maintainer's second report of step H7 (AD 26.5, 2026-10-03):
    - With the minimal project file Altium takes every module sheet into the
    hierarchy only when the schematic documents are listed together, the
    top sheet first, before the PCB document and the libraries
    (H-A-SCH-HIER-ORDER, confirmed by variant l). write_prjpcb now lists
    the top sheet, the module sheets, the PCB document, the libraries and
    the harness files; a build without module sheets keeps its bytes, and
    an existing project file is still kept.
    - The padding of small sheets is removed (padded_records, MINI_CU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
    [altium_hier.PrjPcb]
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2026-10-04 feat(kicad): typed zone settings and pad zone connection (c0031)
    Zones carry their clearance, minimum thickness, pad connection, thermal
    gap and spoke width, fill mode with hatch values, island removal, and
    the filled and locked flags; pads carry their zone connection. They are
    read from 9.0 and 10.0 boards and written with version gating, zones
    can be declared with settings in the DSL, and rebuilds keep zones edited
    in KiCad unless the script locks them. Zones created for target 9 now
    say that their fills have no outline thickness, which stops KiCad from
    drawing them 0.125 mm larger.
    Oracle on kicad-cli: the twenty refill cases match on 10.0.6 (connection
    kinds, thermal gap and spoke width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
    [cmd_build.py]
2026-10-04 feat(checks): Fenolite's own copper check, build guard and via re-net probe (c0029)
    `check_copper` finds copper of different nets that touches or sits
    closer than the clearance in force, with exact integer geometry on
    tracks, arcs, vias, pads in the board frame and zone fills. It runs as
    the `copper.clearance` stage of `fenolite check` and as a guard in
    `fenolite build` for KiCad targets, which refuses a short by default
    (`--copper-check warn` reports only). The clearance comes from the
    project's own rules, net classes and minimums.
    Probed on kicad-cli 9.0.9 and 10.0.6: a via that touches a track of
    another net is exported on the track's net with no short reported, and a
    10.0.6 re-save writ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
    [cmd_build.py]
2026-10-04 feat(altium): net classes in the schematic and component classes on the board (c0048)
    A build for Altium now gives a change order with no removal: each net
    of a net class carries a parameter-set directive with its class name,
    and the project file asks Altium to generate net classes from them, so
    "Update PCB Document" no longer proposes to remove the board's class.
    The PCB document holds one component class per sheet with parts, named
    as Altium names the sheet, and every schematic section carries the
    class-generation keys that turn rooms off.
    Author reports in Altium Designer 26.5: on the per-module sample the
    change order lists only the two "Supply Nets" rules that Altium derives
    from power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
    [altium_hier.PrjPcb, blink.PcbDoc, blink.PrjPcb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]
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2026-10-04 feat(kicad): refill and validate zone fills (c0015)
    Adds KiCad zone refilling and lifted fill support for target 9 and 10, plus the `fenolite fill` command, `zone.fill` check stage, and Docker runner.
    Verified with `make check` (5,617 passed, 26 skipped), the residue and schema checks, and green CI for KiCad 9 and 10.
    [triad_t9.kicad_pcb, triad_t9_filled.kicad_pcb, triad_t9_refilled.kicad_pcb]
2026-10-04 feat(placement): manual and grid placement with a legality check (c0022)
    `fenolite place` moves, rotates and flips footprints of a built board
    and lays parts out on a grid; `move_footprint` keeps pads, fields and
    script copper consistent. Before a build writes, a placement guard
    reports courtyards that overlap, parts outside the outline and parts
    too close to the board edge, from the placed extents of the board frame
    and an outline chained from the edge items.
    Oracle on kicad-cli 9.0.9 and 10.0.6: moved, rotated and flipped
    footprints are exported at the same positions, and courtyards that only
    touch are not reported. The spec was reconciled with the code of c0028
    to c0031 (design, "Reconci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
    [cmd_build.py]
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2026-10-04 feat(altium): write the script's copper in the Altium build (c0053)
    fenolite build --target altium now writes the tracks, vias and stitching
    vias that the design script declares. An intent that does not resolve
    refuses the build instead of being dropped.
    [cmd_build.py]
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2026-10-04 feat(analysis): current capacity, clearance and creepage of a board, and fenolite analyze (c0047)
    fenolite.analysis measures on the neutral model: the capacity of tracks,
    arcs and vias from one published fit whose constants are recorded with
    their sources, the clearance of pairs of nets through air, and their
    creepage along the board surface, around cut-outs and around the board
    edge. Requirements come only from a user TOML file; no requirement
    value, thickness or temperature rise is assumed, and every reply is
    INFERRED or lower.
    A recorded probe on kicad-cli 10.0.6 shows that KiCad's creepage rule
    agrees around a slot and reports nothing across the board edge:
    H-K-AN-CREEP is refuted and H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
    [cmd_analyze.py]
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2026-10-05 fix(kicad): pad copper moved by the drill offset, zone clearance, DSL arcs and pad zone connections, pads command (c0068)
    Loose ends of v0.1. A pad's copper, not its hole, moves by the offset of
    its drill, which removes false clearance findings of check. Also a
    zone's own clearance in the copper check, pad zone connection, arcs and
    via kinds in the DSL, the pads command and a macos-app nightly job.
    [cmd_build.py]
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2026-10-05 fix(kicad): schematic rows on KiCad 9 in CI, the token inventory and the dual-gate test symbol (c0060 follow-up)
    The kicad-9 job fetches the schematic rows. The inventory holds the rows
    of the kinds kicad_sch and kicad_sym, each confirmed by the fuzz on both
    majors. The authored dual-gate symbol lists its pins in the order both
    majors keep, so its library reads back equal after an upgrade on 9.0.9.
    [units_v9.kicad_sch]
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2026-10-05 feat(lens): complete the layout lens with aliases, placements.toml and sync (c0069)
    moved() now takes module paths, and moved_net() renames a net without
    losing its routing. A footprint matched through an alias keeps its
    board node: its uuids, its fenolite.path and its group memberships move
    to the new path, so edits made in KiCad survive a rename.
    fenolite sync --to-source writes placements.toml beside the design
    script, and build reads it for both targets, also with
    --discard-layout. The precedence is locked place(), the board, the
    file, place(), staging. sync --check fails when the committed file is
    stale, and sync reports what the next build would drop.
    The plan's lens acceptance runs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
    [minimal.kicad_pcb]
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2026-10-05 feat(checks): design equivalence in four levels and fenolite equivalent (c0045)
    fenolite.checks.equivalence compares two designs of one board read by
    any two backends, at four levels: components, pad nets, placements and
    pad geometry, in an absolute or a relative frame, with tolerances and
    exclusion rules that name what a tool is known to change. fenolite
    equivalent A B reports the level reached and every difference;
    --against kicad-import compares an Altium board with what kicad-cli
    imports from it.
    On seven public Altium boards the import and KiCad's importer agree
    at all four levels after ten excluded differences: 418 components,
    1 438 pad-net elements, 1 458 pad pairs, at most 9 nm apar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
    [cmd_equivalent.py]
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2026-10-05 feat(cli): the project artifact manifest and its verification states (c0065)
    build, check and export keep one manifest per project (fenolite.artifacts.v0)
    with a state per entry: generated, roundtrip-ok, checked, native-verified.
    Each entry says in held what its next state is missing. Sheets stop at
    roundtrip-ok until the ERC stage of c0062 exists; task 4.1 stays open for it.
    [_assembly.py, _manifest.py, cmd_bom.py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]
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2026-10-05 feat(kicad): build writes the schematic, its symbol libraries and sym-lib-table (c0061)
    A build writes <name>.kicad_sch beside the board, with no-connect flags, power
    flags and net names in KiCad's stored form; pads of unconnected pins get the
    net KiCad gives them. ERC and schematic parity report nothing on both examples
    on KiCad 9.0.9 and 10.0.6. --schematic skip keeps the previous output.
    The maintainer's run of Update PCB from Schematic in 10.0.6 is recorded in
    H-K-SCH-UPDATE, which stays INFERRED.
    [minimal.kicad_sch]
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2026-10-06 feat(kicad): one schematic sheet per module and a readable layout of the generated schematic (c0070)
    A build writes a child sheet for each module under sheets/, with sheet pins
    and hierarchical labels, and lays the sheets out readably: a part beside the
    pin it serves, short wires, labels for the rest. The own netlist and parity
    read the tree of sheets, so they still need no tool for a generated project.
    ERC, parity and the netlist agree with kicad-cli on 9.0.9 and 10.0.6. The
    footprint paths of module parts follow the sheet tree. Tasks 6.2 and 7.1 stay
    open.
    [blink.kicad_sch]
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2026-10-06 fix(kicad): the Reference and Value of a turned schematic symbol are clear of its labels (c0070)
    KiCad draws a field turned with its symbol, so the Reference of a satellite
    turned on its side lay on the label of its far pin. The writer now centres the
    two texts of a turned or mirrored instance, at the angle that is drawn level,
    in a room beside the label of the wired pair; the snap tests that room. A test
    estimates the text boxes from the written sheets of the blink, the acceptance
    design and the generated designs. More parts fit beside their IC pin; boards
    and grid sheets are byte-identical.
    [blink.kicad_sch]
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2026-10-06 feat(checks): level 5 of equivalent compares routing per net (c0089)
    For each net that level 2 pairs, the copper is grouped into connected
    pieces by the exact touch test of the copper check, and the two sides
    must join the same pads, with the same vias per pair of copper spans
    and the same routed length per span within a tolerance. The path of a
    track is not compared.
    equivalent accepts --level 5 and --tolerance-ppm; without --level it
    compares routing when both sides hold copper, so --level 4 gives the
    former result. Stubs and nets that depend on an unfilled zone are
    reported as notices and never make two designs unequal.
    The triangle (KiCad board, written Altium document, KiCad's import)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
    [cmd_equivalent.py]
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2026-10-06 feat(altium): write the script's rules by kind and scope, read them back, export a rule file (c0084)
    An Altium build writes each rule of the design into the PCB document as the
    Altium rule kind that carries it, exactly or not at all, and names every rule
    it does not write with one reason.
    - rulemap.py: the closed table of the twelve neutral kinds. Seven rows are
    exact (Clearance, Width, Routing Via Style, Hole Size, Board Outline
    Clearance, Hole To Hole Clearance, Minimum Annular Ring); hole clearance,
    courtyard clearance, silkscreen clearance and creepage have no counterpart.
    lower() writes a rule only with the limits its record holds and with a
    scope of all objects, a net, a net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
    [cmd_build.py]
2026-10-06 feat(altium): complete the schematic writer: symbol graphics, the module tree, directions, buses, parameters and text outside ASCII (c0086)
    The Altium schematic draws each resolved symbol from its own graphics (the new default of --altium-symbols; generic keeps the former bytes), gives every module a sheet at any depth, writes port and sheet-entry I/O types (--altium-directions), bus records, hidden parameters and, in the binary form, comments and parameter values in Windows-1252 with their UTF-8 twin. Catalog and authored symbols now build for the Altium target.
    The samples blink, kicad_example, no_connect and routed are regenerated; their former bytes, which the author reports covered, ar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
    [altium_kicad.SchDoc, altium_kicad.SchLib, altium_no_connect.SchDoc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]
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2026-10-06 feat(altium): instantiate Repeat statements as channels, resolve their nets, and carry the pin-to-pad map on imported components (c0083, second part)
    [two.PrjPcb, two.SchDoc, two_ch.SchDoc]
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2026-10-07 fix(catalog): show a pin name only where it can be read (c0134)
    In Altium the pin names of BJT_NPN, Comparator, Operational_Amplifier,
    Linear_Regulator and CONN2 lay on each other. Both writers draw what a
    symbol's own flags say, so the definitions change and no writer does.
    A rule, measured by a hermetic test on every symbol Fenolite authors,
    at KiCad's text size and at an estimate of Altium's: no shown pin text
    overlaps another, a shown name has room inside the body, no shown name
    or number lies on a stroke of the body or on the mark of a pin shape
    (bubble, clock wedge, low-level mark, as kicad-cli 10.0.6 draws them),
    and no shown name only repeats its pin's number (tests/_pintext.py,
    tes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
    [altium_kicad.SchDoc, altium_kicad.SchLib, altium_no_connect.SchDoc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]
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

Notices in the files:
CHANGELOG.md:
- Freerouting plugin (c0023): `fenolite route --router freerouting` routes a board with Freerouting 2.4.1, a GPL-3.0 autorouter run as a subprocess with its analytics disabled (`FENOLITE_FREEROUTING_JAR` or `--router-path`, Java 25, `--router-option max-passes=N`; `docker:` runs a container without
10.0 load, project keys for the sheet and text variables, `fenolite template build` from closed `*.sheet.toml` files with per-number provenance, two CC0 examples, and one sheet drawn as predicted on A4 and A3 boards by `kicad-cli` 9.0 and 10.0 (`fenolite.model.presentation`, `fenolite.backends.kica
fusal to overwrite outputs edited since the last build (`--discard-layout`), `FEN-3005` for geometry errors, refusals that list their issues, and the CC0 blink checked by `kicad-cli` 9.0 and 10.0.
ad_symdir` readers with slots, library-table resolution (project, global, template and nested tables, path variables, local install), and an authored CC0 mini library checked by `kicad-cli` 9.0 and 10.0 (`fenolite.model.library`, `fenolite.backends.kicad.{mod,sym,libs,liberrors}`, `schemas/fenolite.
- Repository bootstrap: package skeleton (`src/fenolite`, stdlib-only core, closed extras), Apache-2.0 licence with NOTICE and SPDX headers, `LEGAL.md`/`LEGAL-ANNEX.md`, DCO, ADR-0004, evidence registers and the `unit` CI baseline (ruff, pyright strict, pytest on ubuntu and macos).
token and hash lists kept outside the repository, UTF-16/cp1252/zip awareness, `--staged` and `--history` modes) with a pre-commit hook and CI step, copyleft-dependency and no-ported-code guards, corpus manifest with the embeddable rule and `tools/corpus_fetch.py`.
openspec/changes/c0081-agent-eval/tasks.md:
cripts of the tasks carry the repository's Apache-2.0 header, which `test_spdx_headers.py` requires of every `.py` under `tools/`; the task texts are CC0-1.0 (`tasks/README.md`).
